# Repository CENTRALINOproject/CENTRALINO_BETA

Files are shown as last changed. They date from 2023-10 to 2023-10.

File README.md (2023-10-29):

<p align = "center">
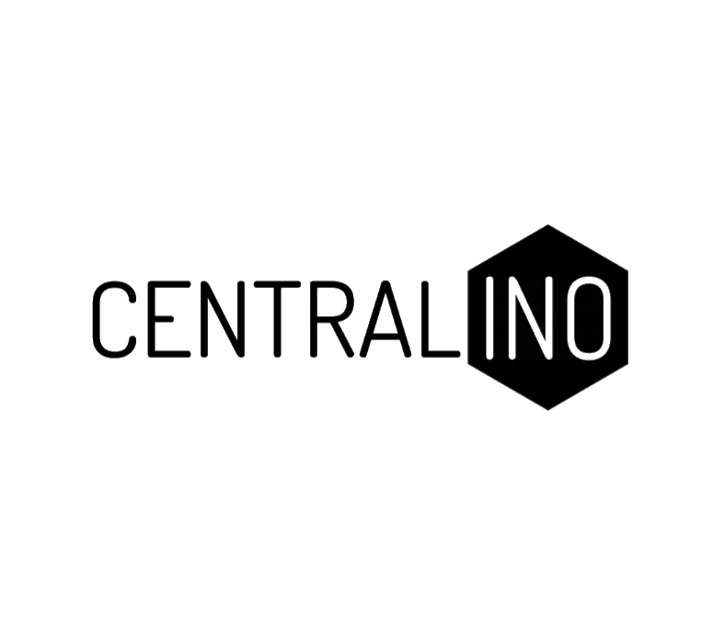
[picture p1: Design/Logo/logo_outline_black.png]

<br>
<i>Your world in your hands.</i>
</p>

> **Arduino-powered device** for _near-field_ **remote control of multiple power outlets**. 
> 
> The device can be programmed and scheduled with timers thanks to its internal clock. 
> 
> It can be **easily configured using its Android app** counterpart, which is designed for devices operating with Android provided of a _bluetooth transmitter_.
> 
> The app also supports **voice commands** with a very simple syntax.

# CENTRALINO
<p align = "right">
Last modified: 19th June 2017
</p>

**Project reference fields:** 

`Novel Technologies`, `Internet of Things (IoT)`, `Home Automation`.

## Hi, I'm Filippo 👋
This is a very old project of mine, it was born in January 2017 and concluded in June the same year. 
This was my first project in the field of electronics and programming.
I was 17 years old and I guess you can tell I was a bit naive, but I was very passionate about it and I still am.

This project has many flaws, but it was a great learning experience, I'm quite fond of it, so I decided to share it here as something to remember. 

Something that will always suggest how ...
<p align = "right">
<b>...every long journey begins with a first step.</b>
</p>

<p align = "center">
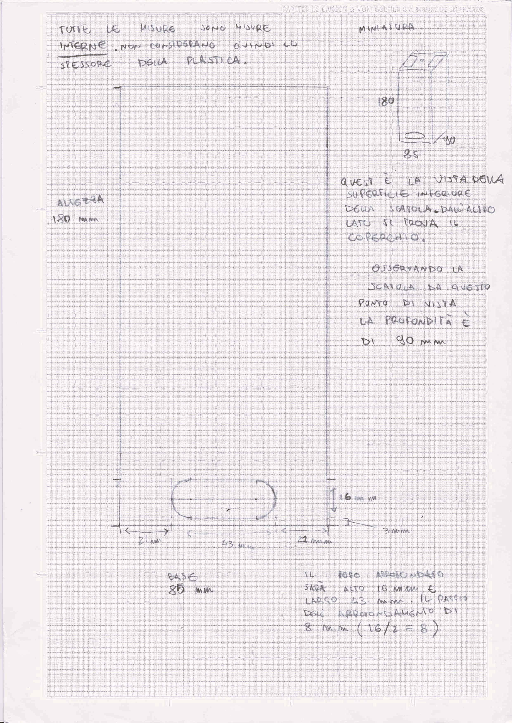
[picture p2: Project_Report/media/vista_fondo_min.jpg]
sketch

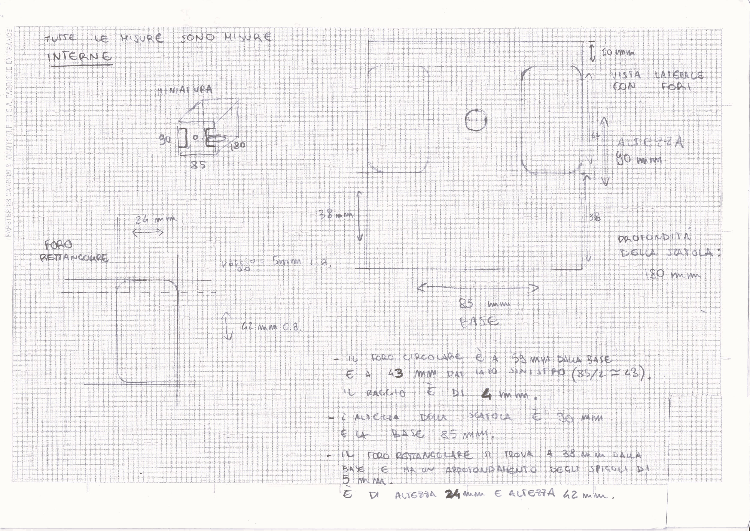
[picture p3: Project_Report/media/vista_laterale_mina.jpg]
lateral sketch

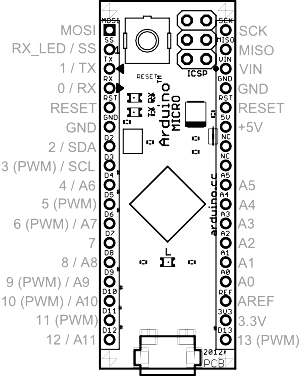
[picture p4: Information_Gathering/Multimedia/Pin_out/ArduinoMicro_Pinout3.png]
pinout arduino micro

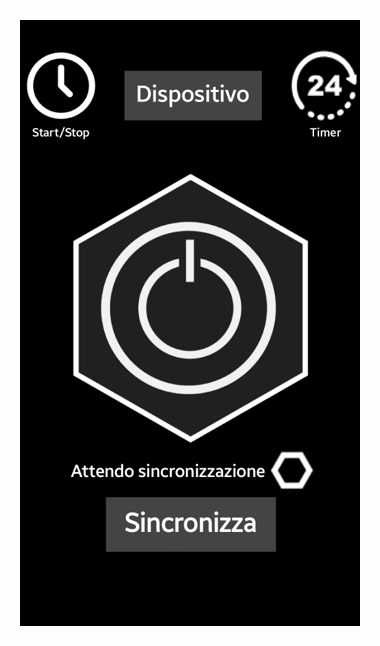
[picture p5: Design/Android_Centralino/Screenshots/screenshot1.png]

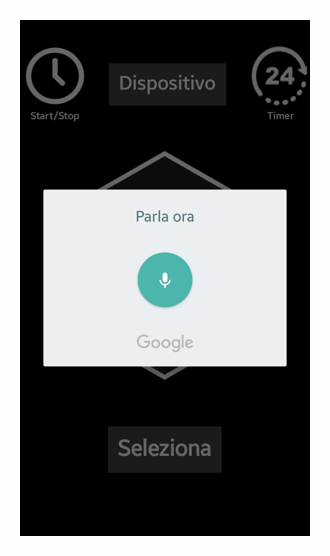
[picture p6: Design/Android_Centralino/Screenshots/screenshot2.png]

</p>

------------------------------------------------------
##### Small note on language 🇮🇹 🇬🇧:
The project was born in Italian, so unfortunately many of the comments in the code as well as documentation and the report are in Italian.
I apologize for this, but I hope that the code is still understandable and that the documentation is still useful (maybe with the help of a translator).

**I decided to have at least the README in English, so that the core of the project as well as the repository structure is understandable to everyone**.

**I also decided to translate a part of the report, concerning the code structure and rationale.**

Such translated document can be found [here](Code_Rationale.md).

**I also translated the Android app presentation concerning the App GUI.** 

Such translated document can be found [here](Design/Android_Centralino/Screenshots/Presentation.md).

## Idea and objective:

The project was born with the purpose of making residential and working complex more connected to the people who inhabit it. The project aims to enhance humans environmental control. 
CENTRALINO is designed to control electrical devices such as household appliances, electric, air conditioners, heating systems, and similar.

An increased control can change a person's experience with the surrounding world. The CENTRALIzation of automation is sometimes not just a convenience but a necessity, e.g. in case of subjects with disabilities. 

"Smart homes" are a topic that companies are vigorously addressing to offer increasing automation and integration between systems and services. 
Home automation involves a complex mix of various technologies and requires strong interdisciplinary collaboration.

### The project aims to:

 - Enhance security of electrical devices populated environments.
 - Reduce operating costs.
 - Convert old environments and old systems into more dynamic ones.
 - Simplify the design, installation, maintenance, and use of technology.
 - As a whole: improve the quality of life.

## Description of the project:

The project is named "CENTRALINO" (Italian for "switchboard"), the name reflects its function of both **centralizing** and **managing** control, much like in telecommunications.

CENTRALINO is a device that allows remote control of multiple power outlets with the possibility to be programmed and scheduled at specific intervals using an internal clock.

The device is easily configured with mobile devices such as phones, tablets, or computers. The latter only needs to run an Android OS and be provided of a Bluetooth transmitter.

## Functions of the device:

Currently, there are three main functions, but the **most important aspect** is that there is an **infrastracture basis that anyone can use to develop their own custom functions** or also implement **new communication protocols**.

1. **Instant On/Off** - Instantaneous switching on and off of the selected device (which means indirect control on its power outlet). 

2. **On/Off with alarm** - Similar to the previous function, but with the possibility of specifying a time at which the device will be turned on or off.

    To do so the device uses the RTC (Real-Time Clock) to compare CENTRALINO's time with the user-set "alarm" time.

3. **On/Off with a timer** - Similar to the previous function, but with the possibility of specifying a duration after which the device will be turned off.

>**Q: How is the CENTRALINO device set to the current time?** 
>
>**A:** It receives the timer duration in minutes from the Android app counterpart and sets the RTC accordingly.

------------------------------------------------------

# Repository structure

    .
    |
    ├── Information_Gathering
    │   ├── Documents                           # Documents concerning components working principles
    │   │    ├── Bluetooth                      # Code snippets and protocol description of bluetooth communication
    │   │    ├── Infra_Red                      # Semiconductor and diodes working principles
    │   │    ├── Transfer_Protocols             # I2C and SPI protocols description
    │   │    └── Flex_sensor                    # Flex sensor working principles
    │   │
    │   └── Multimedia                          # Pin configuration for different hardware components
    │        ├── ...
    │        └── ...
    │
    ├── Design                                  # Design files
    │   ├── Android_Centralino                  # Android app files and latest version apk 
    │   ├── Logo                                # Logo images
    │   └── Software                            # Arduino code files
    |       ├── CLIENTino_versions              # CENTRALINO code versions
    |       ├── Librerie                        # Arduino libraries
    |       └── ...
    │      
    └── Project_Report                          # Final report of the project
        ├── Presentazione_applicazione.pdf      # Android app presentation
        ├── Relazione progetto CENTRALINO.pdf   # Project report
        └── ...

## Information gathering on components: 🔧🔩

I used to create small documentation files for each component and some of them are here listed:

- [Bluetooth Coding](/Information_Gathering/Documents/Bluetooth/Bluetooth_coding.md)
- [Bluetooth](/Information_Gathering/Documents/Bluetooth/Bluetooth_study.md)
- [InfraRed and semiconductors](/Information_Gathering/Documents/Infra_Red/Semiconduttori.md)
- [Transfer Protocols](/Information_Gathering/Documents/Transfer_Protocols/Transfer_protocols.md)
- [Flex Sensor](/Information_Gathering/Documents/Flex_sensor/Flex_sensor.md)

## Design: 📐

Here is possible to find the latest version of the Android app and the Arduino code.

- [Android app](/Design/Android_Centralino/App_builds/STABLE_CENTRALINO1_3.apk) 📱
    - Overview of the App GUI is available [here](/Design/Android_Centralino/Screenshots/Presentation.md)
    - Overview of the App code structure is available [here](Code_Rationale.md#rationale-behind-the-android-app-code-structure)

- [Arduino code](/Design/Software/CLIENTino_versions/CLIENTinoPRESENTATION1_1/CLIENTinoPRESENTATION1_1.ino) ⚙
    - Overview of the Arduino code structure is available [here](Code_Rationale.md#rationale-behind-the-arduino-code-structure)

## Project report: 📝

The project report is available [here](/Project_Report/Relazione%20progetto%20CENTRALINO.pdf) (in Italian).

The android app presentation is available [here](/Project_Report/Presentazione_applicazione.pdf) (in Italian).

------------------------------------------------------

# Implementation 

## Tools used (Software).

 - **Fritzing**: is a free software for electronic design, focused on the transition from simple prototypes to the printed circuit board to be sent to production. Useful for designing the prototype of the circuit even before it is built.
 - **Arduino IDE**: is the integrated development environment (Integrated Development Environment) of Arduino, it is a multiplatform application in Java used to compile the code with which the microcontroller that manages the sensors and other components is programmed.
 - **MIT App Inventor (Framework)**: is a web application created by Google but now owned by the Massachusetts Institute of Technology. A development environment useful for creating applications for personal use.
 - **BlueStacks**: is an application created by the American company BlueStacks Systems Inc. in 2011. BlueStacks App Player is an android app emulator for MacOS and Windows operating systems. The main features are the fully customizable environment, support for multiple operating system configurations and integration with Google Play.

 ## System architecture

A user can connect to CENTRALINO with the appropriate software application simply via Bluetooth. 
  
### The final system will be based on the presence of three characters:

<p align = "center">
diagram
</p>

  - **USER**: connects via bluetooth to the devices.
  - **CENTRALINO**: controls the power outlet.
  - **CENTRALINO-SERVER**: enables the user to control all the associated CENTRALINO (CLIENTs) without ever having to disconnect from CENTRALINO SERVER, which will take care of managing the communications with the others.

    The latter has not been created yet. However, by adding a communication layer on top of the current one with very little effort, it would be possible to create a network of CENTRALINO devices that operate synchronously under the control of a single central server.

------------------------------------------------------

## Tools used (Hardware):

 - Welder.
 - Cellulose adhesive tape.
 - Screwdrivers.
 - Solder wire.
 - Liquid silicone.

## Components used (Hardware):

     • Jumpers for solderless male-male connections.
     • Bread Board for experimental prototypes of solderless circuits.
     • Infrared receiver.
     • Buttons/Buttons.
     • Bluetooth transceiver module – module for Bluetooth transmission and reception.
     • Micro SD Mini Slot – Module for connection with a micro SD card for data storage.
     • Assortment of resistors from 1 to 10 M Ohm (Ω).
     • RTC (Real Time Clock) Real Time Clock – module with battery.
     • Micro ATmegax32u4 powered by 5V (microcontroller).

## Cost of components:

Prices are taken from the following sites:
     - AliExpress: is a branch of the "Alibaba Group" company that unites Chinese companies and offers a retail service to an international market, mainly targeting European buyers. It is the supplier of our components.

     • Jumpers = 120 pieces for €2.39.
     • Bread Board = 2 pieces for €0.74.
     • Infrared LEDs = 20 pieces for €1.25.
     • IR receiver = 10 pieces for €0.73.
     • Buttons/Buttons = 100 pieces for €1.44.
     • RTC (Real Time Clock) = 1 piece for €1.20.
     • Micro ATmegax32u4 = 3 pieces for €4.59 each.
     • Micro SD Mini slot = 2 pieces for €0.47 each.
     • Assortment of resistors = 300 pieces for €1.62.
     • Bluetooth HC-06 module = 2 pieces for €2.73 each.
     • 2-channel relay module (Sain Smart) = 1 piece for €9.00.

TOTAL = 

    2.39 * 1 + 0.74 * 2 + 1.25 * 1 + 0.73 * 1 + 1.44 * 1 + 1.20 * 1 + 4.59 * 3 + 0.47 * 2 + 1.62 * 1 + 2.73 * 2 + 9.00 * 1
= €40.88

> Actually not all the components are strictly necessary, but they were bought in order to have some spare parts in case of damage or malfunction.

#### Enclosure

    • Box = 1 piece for €7.00.

Produced by a local company: Tomea Plastiche.

The enclosure is a box made of plexiglass, a material that is aesthetically pleasing, partially fireproof and relatively easy to work with. Wood and metal were excluded, the first for its predisposition to fire and the second for its well-known electrical conductivity.

### Implementation specifications

In order to be able to implement the device in a larger system, the device only needs a connection to the mains powered at 220 V (Volts) (such as the domestic power grid) and a current voltage not exceeding 15 A (Ampere) to avoid damaging the circuit or incurring a malfunction of the device. 

------------------------------------------------------

### Further development

Possibly in the future the CENTRALINO server may be provided with a wirless antenna in order to communicate with a router, which in turn communicates with the user, possibly via the internet. However, this poses a problem of security and privacy. 

<p align = "center">
diagram
</p>

### Known issues:

 #### Concerning the Instant On/Off function:
For greater safety, future security measures should be implemented to prevent continuous switching on and off of the same outlet to avoid damaging the connected devices and the microcontroller itself.

 #### Concerning voice commands:
The voice commands syntax is very simple, but it is also very limited. It is not possible to deviate even just a little without incurring in unrecognized commands. This is due to the total absence of natural language processing, which in 2017 I dint know how to implement.

 #### Concerning InfraRed communication:
The code structure of the device is able to eventually support infrared communication, but it is not implemented yet to the same extent as Bluetooth. Only basic functions are implemented such as instant on/off of a single outlet. However the physical circuitry is designed to support it and the code structure is ready to be expanded.

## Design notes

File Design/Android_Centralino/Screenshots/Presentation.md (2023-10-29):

# Brief overview of the App UI

## Home Screen

App prompts the user to "connect" to the centralino. This is done by connecting through bluetooth. 

<p align="center">
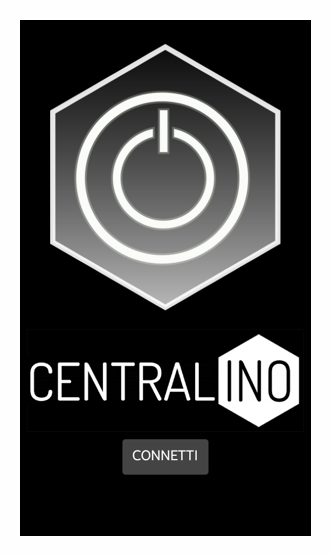
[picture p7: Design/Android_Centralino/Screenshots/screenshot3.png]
Home Screen
    
</p>

> In case the bluetooth is not enabled, the app will ask the user to enable it and guide to settings.

<p align="center">
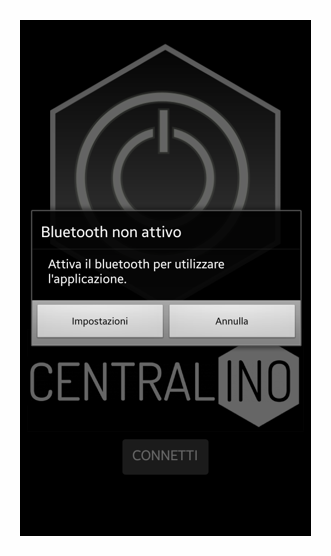
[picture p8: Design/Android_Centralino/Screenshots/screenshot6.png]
BT is not enabled
    
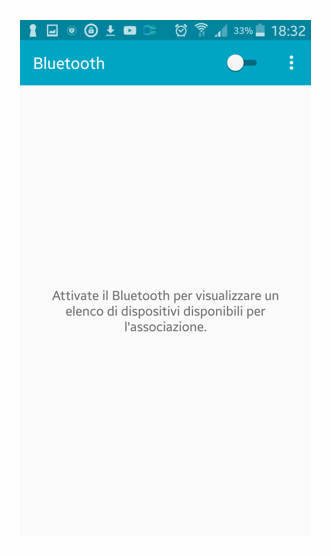
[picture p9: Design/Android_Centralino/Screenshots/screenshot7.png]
BT settings
    
</p>

## Waiting for sync

Once the bluetooth is enabled, the app will start searching for the centralino. Once connected it will prompt the user to sync the available devices connected to the outlets. 

This is done by sending a request to the centralino to send the list of devices connected to the outlets. The centralino will respond with a list of devices. Described in detail [here](../../../Code_Rationale.md#automatic-retrieval-of-the-number-of-devices-connected-to-centralino-by-the-app).

-----------------------------------------------------
### Main screen

<p align="center">
    Waiting for sync
</p>

**Top left**: Alarm icon indicates the possibility to set a time for the device to turn on/off. See [Setting an alarm](#setting-an-alarm).

**Top right**: Timer icon indicates the possibility to set a timer for the device to turn on/off. See [Setting a timer](#setting-a-timer).

**Center**: Main button allows instant on/off control of the currently selected device. 

**Bottom center**: Sync button. This button will be enabled once the centralino is connected. It will allow the user to sync the devices connected to the outlets.

---------------------------------------------------

## Device selection

The app will then display the list of devices and prompt the user to select the device to control.

<p align="center">
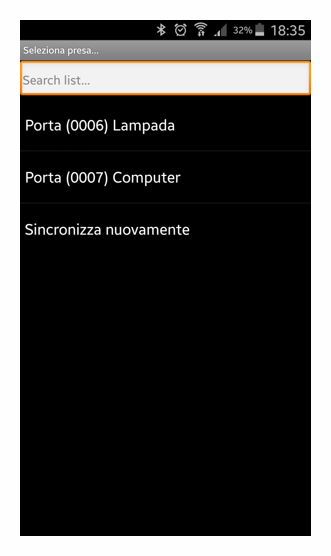
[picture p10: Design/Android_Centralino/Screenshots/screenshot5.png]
Device selection
    
</p>

Devices available in the screehsot are `Lamp`, `Computer`, `New sync`. 

## Voice control

By holding the central button, the user can use voice commands to control the device. The app will prompt the user to speak the command.

<p align="center">
    Voice control
</p>

## Setting a timer

<p align="center">
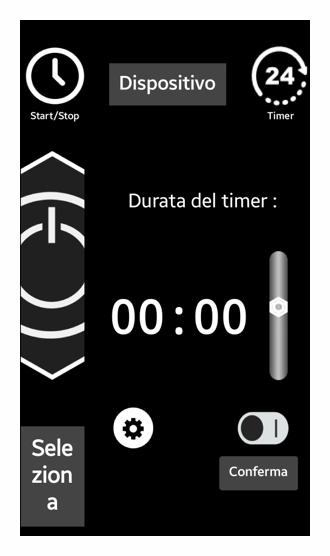
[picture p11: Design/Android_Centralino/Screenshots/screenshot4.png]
Setting a timer
    
</p>

## Setting an alarm

<p align="center">
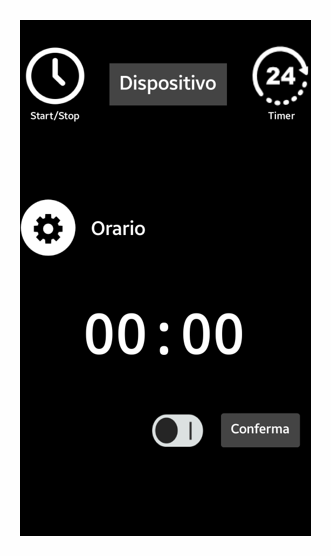
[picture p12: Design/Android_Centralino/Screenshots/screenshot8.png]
Setting an alarm
    
</p>

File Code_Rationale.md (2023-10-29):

# Arduino and Android code rationale
-----------------------------------------------------------

## Rationale behind the Arduino code structure

Referring to the latest version of the code, available [here](/Design/Software/CLIENTino_versions/CLIENTinoPRESENTATION1_1/CLIENTinoPRESENTATION1_1.ino).

### Brief overview of the code structure:
The code utilizes two data structures named `function` and `relay`. 

The `function` structure is responsible for containing the information received through Bluetooth packets, while the `relay` structure is responsible for storing information related to the physical device's outlets. 

Each `relay` structure will have its own:
 - activation and deactivation times, 
 - a timer,
 - a numerical description to indicate on which physical relay to issue a command, especially the pin address so that the microcontroller knows where to send the activation/deactivation signal. 

#### How is the information received from the Bluetooth packets stored?

An additional layer on top of the Bluetooth communication system was created to make the system more flexible. Bluetooth covers all seven levels of the ISO/OSI, but with an additional layer, it is possible to managae different power outlets an the same CENTRALINO (making this comunication mean flexible to our purspose).

#### Bluetooth Packet Structure:

##### Initiator and terminator:
Each Bluetooth packet consists of 16 bytes and has a packet initiator "[" (ASCII: 91) and a terminator "]" (ASCII: 93). 
Without these, it would be impossible to determine when a packet begins or ends, making byte stream handling much more manageable. 

##### Content and divisions:
Inside the packet, there are additional divisions indicated by the symbol "," (ASCII: 44). It helps determine the beginning and end of each packet sector, providing greater packet integrity (in the case of erroneous transmissions, if there are no ",", the packet will not be considered valid. For a better understanding, refer to the "void bluetooth_Parser()" function). 

**Packet final structure**

    [ 
        Activity (2 digits) 
        , 
        Extra_value (4 digits) 
        , 
        Extra_value2 (6 digits) 
    ]

 - `Activity` varies based on Wake-up/Timer and On/Off. 
 - `Extra_value` contains the pin number to which the command should be directed. 
 - `Extra_value2` contains, in the case of "Wake-up," the time in the hh:mm:ss format, and in the case of "Timer," the time in milliseconds.

##### Activity handling:
The system also has an "activity handler"; it serves to manage packets once they have been "routed" and understand the actions required. 

The variable `activity` mentioned in the previous point stores the code corresponding to the action the microcontroller must perform (e.g., 01 and 02 are the `activity` corresponding to instantaneous power On and Off). 

In `Extra_value`, is stored the device number, the packet refers to, so the value found in `rel[x].socket` is, in fact, the pin to which the relay is connected and to which `Extra_value` refers (this mechanism makes it possible to address packets to individual devices, similarly to a "MAC address"). 

In `Extra_value2`, you can find the supplementary value that supports the "activity." For example, the times for "alarms" expressed as "001650" (for integrity reasons, they are always six digits). The one just mentioned is an alarm for 16:50.

> Example packet: "[03,0006,001650]". 
>
> It sets a power-on alarm for 16:50 on pin 6.

### Main Challenges

#### Limitations of the microcontroller:
The microcontroller lacks an internal clock, making it impossible for it to determine the time during activities. This required the use of an external component, a Real-Time Clock module, to manage the time. 

However, this component does not have alarm or timer functions, so the microcontroller had to handle time and activity deadlines on its own. 

Additionally, there was the issue that if two `relay` structures had the same deactivation time and the time for acquiring the time was too slow, the system might be too slow to manage the alarms. This was resolved with the "void turn_by_match()" function, which checks each individual `relay` structure in times well below a second and ensures that multiple `relays` can be turned on/off simultaneously, even when the times coincide down to the second.

#### Automatic retrieval of the number of devices connected to CENTRALINO by the app:
To inform the application about the devices connected to the device, and for this purpose, a superficial description of the power outlets was required. Thus, the `description` variable with a legend (referred to in the code as MEANINGS OF DESCRIPTION) was introduced. The mechanism through which the application learns about the various `descriptions` of the `relay` structures is as follows:

> - The software application sends a packet with activity = 50, i.e., a Discovery (requesting information to be sent).
> - The device sends as many packets as there are "relay" structures with activity = 51 and the respective rel[].description (the description of each structure)
> - Finally sends a packet with activity = 99, which means that the relays have been completed, and the application can stop waiting for more information.

----------------------------------------------------------- 

## Rationale behind the Android app code structure

Referring to the latest version of the code, app .apk available [here](/Design/Android_Centralino/App_builds/STABLE_CENTRALINO1_3.apk)

### Brief explanation
The application mainly uses the use of global variables that are continuously used in block to send packets with the `activity`. These three variables take their name from the physical device system CENTRALINO, therefore they are also called `activity`, `extra_value` and `extra_value2`.

#### Animations
The animations are minimal and take place thanks to the "expansion" of self-moving areas that move the contents of the page to be displayed by the user. When a button is pressed, the cycle starts that "expands" the "push_container" (both "right" and "left") with variables that increase the area covered on the screen. Once "Left_container" and/or "Right_container" have moved, they remain in the position they are in until the next button press.

#### Bluetooth picker
The bluetooth_picker allows you to choose between devices associated with the phone quickly and intuitively.

#### Voice command recognition
Voice command recognition takes place by identifying specific words within a sentence. If the words "turn on" or "turn off" are present in the spoken sentence, the algorithm searches the rest of the sentence for the name of a device that it knows to be connected to the device. If the device is found, the application sends the appropriate signal, otherwise it signals it with a sound notification.

#### On the infrastructure of the app
The App Inventor development platform is based on the use of events. Android events act as a system kernel. They allow you to always know when a certain action has occurred and therefore allow you to call specific functions when those "events" occur. For example, when a button is pressed, it will raise the button.onclick() event and it will be possible to call your own "procedure" (function) whenever the event is raised. Events are many and very varied. The events related to the screen, i.e., "screen.BackPressed()" and "screen.Initialize()", the events related to the buttons of various types ("timePicker" and similar) have been mainly used, and as can be seen from the operating code, the tinyDB object/component with its various methods and functions has been widely used.

### Main Challenges

#### Event Handling
The transition from a conventional programming paradigm to a more intricate one can pose substantial challenges. Unlike traditional sequential code, this paradigm relies on dynamic event-driven behavior, necessitating a shift in coding approach.

#### Scarcity of Documentation
Given that App Inventor is not structured around a conventional programming language, authoritative documentation pertaining to command syntax is notably sparse. While the platform's intuitive operation aids in most cases, instances where intuitive cues fall short demand extensive research and comprehension of commands for achieving predefined objectives.

#### App Inventor Limitations
Significant impediments arise from the utilization of App Inventor, primarily owing to its ongoing beta development status. This platform is susceptible to recurrent crashes, diverse bugs, and frequent disruptions in its partial functionality, posing substantial operational challenges.

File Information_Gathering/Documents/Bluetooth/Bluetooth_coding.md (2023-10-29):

# Bluetooth Codici 

## Note preliminari:

Citazione dalla grande guida dei moduli HC-0X :

 > "3. Notes. (1) HC-03 and HC-05’s command should end up with “\r\n”. It means when you finish programming, you should add terminator (“ENTER” or “0x0d 0x0a”) to the program. It’s different from HC-04 and HC-06 (They don’t need terminator)." 
 
-cit [source](http://cdn.instructables.com/ORIG/FKY/Z0UT/HX7OYY7I/FKYZ0UTHX7OYY7I.pdf)

Secondo la guide di Arduino e instructables i pin del bluetooth vanno connessi così: 
> Pin del Micro per RX ———->      TX

> Pin del Micro per TX ———->      RX

> 3.3V         ———->      VCC

> GND        ———->      GND

### Librerie necessarie:

#include <SoftwareSerial.h>

### Dichiarazioni:

Pre-setup & post-libreria questo :
 - SoftwareSerial nomedelsoftwareseriale(esempio:"bluetooth")(PIN RX,PIN TX);
Nel setup:
 - Nomedelsoftwareseriale.begin(38400);

"In modalità AT il modulo HC comunica a 38400 baud." -cit
"Gran parte di questo capitolo è preso da questa guida su Instructables. Per cambiare configurazione al vostro modulo (ad es. cambiare velocità di trasmissione, nome, pin, ecc.) dovete entrare in modalità AT. L'HC-06 dovrebbe essere sempre in questa modalità, mentre l'HC-05 dev'essere acceso tenendo premuto il tasto "KEY" oppure mettendo a +3.3v il pin key sulla board. " 
-cit http://www.raspibo.org/wiki/index.php?title=HC-05_e_HC-06#Differenze_HC-05_e_HC-06

## Funzioni:

### Verifica della connessione :
#Questa funzione ritorna 1 se la software serial è attiva e sta "ascoltando" (streammando il flusso dati) mentre ritorna 0 se non sta "ascoltando" .

``` C++
int nomedelsoftwareseriale_connection_state()
  {int a=0;
if (nomedelsoftwareseriale.isListeninig())
{a=1}
return a; 
  }
  ```

### Flush del buffer sul software seriale :
#Questa funzione semplicemente scarta TUTTO quello che c'è nel buffer inserendolo nella variabile flush e sovrascrivendolo ogni volta. Non c'è modo di invertire questa funzione.

``` C++
void buffer_flush()
{
  while(nomedelsoftwareseriale.available()>0)
    {
    char flush = nomedelsoftwareseriale.read();
    }
} 
```

### Trasmissione di un messaggio intero e stringa :
#Questa funzione trasmette sul software seriale inizializzato (qualsiasi dipendentemente dal nomedelsoftwareseriale ) una stringa o un intero passata/o alla funzione, il nome della variabile nella funzione è 'transimission'.
``` C++
void message_string_transmit (string transmission)
{
nomedelsoftwareseriale.write(transmission);
}

Piccola variante della funzioni precedenti che permette di inviare variabili di interi. 

void message_int_transmit (int transmission)
{
nomedelsoftwareseriale.write(transmission);
}
```

### Funzione per la restituzione della lunghezza del buffer del software seriale.

``` C++
int buffer_lenght();
{int lenght=0;
x=nomedelsoftwareseriale.available();
return x;
}
```

### Verifica dei messaggi :
#Questa funzione ritorna il contenuto del buffer del software seriale se presente altrimenti ritorna NULL, se il buffer supera il limite di 2048 elementi il buffer non viene letto e viene flushato poiché illeggibile.
Esiste anche readString ma questo metodo mi sembra più sicuro, non ottimale, sicuro.

``` C++
char serial_buffer_retrieve() 
{int char_ind=0, char_ind2=0, x; 
 x=lenght_buffer();

if (x>0)&&(x<2048)
#'x>0' significa che ci sono x dati nel buffer, svuota (buffer_flush()) il buffer se ci sono più di 2048 elementi, altrimenti si va verso il buffer overflow.
{
      char buffer_retrieve[x];
 
      #inizializzazione buffer_retrieve[x](sotto) 
for (char_ind=0; char_ind<x; char_ind++) 
{
buffer_retrieve[char_ind]=' ';
} 

#scrive su buffer_retrieve[x](sotto)
for (char_ind2=0; char_ind2<x; char_ind2++) 
{
char_retrieve[char_ind2] = nomedelsoftwareseriale.read(); 
} 
return char_retrieve[x]; 
} 
buffer_flush();
return null;
}
```

Funzione per l'identificazione (detecting) di messaggi singoli o multipli contenuti nel vettore di caratteri passato alla funzione. 
Si utilizza la variabile char end_message per stabilire una combinazione di caratteri all'interno del messaggio con il significato di 'fine messaggio'.
Si utilizza la variabile int lenght per sapere quanto è lungo il vettore di caratteri essa sarà calcolabile grazie alla funzione buffer_lenght(), la funzione appena esplicitata andrà posizionata con criterio prima della funzione serial_buffer_retrieve;
La funzione ritorna il numero di messaggi (il numero di volte che viene trovato nel vettore 'detecting' il vettore char 'end_message') sotto forma di intero.

### Esempio : 

Vettore end_message = "*r"
Vettore detecting = "ciao *r come *r stai? *r"
in questo esempio verrano detectati 3 messaggi (3 volte è presente "*r").

``` C++
int message_detect(char detecting[], char end_message[|2 circa?|], int lenght)
{int number_of_messages=0, utility_ind=0;
for( utility_ind=0; utility_ind<lenght; utility_ind++)
{
if( detecting[utility_ind] == end_message[1])
if(( detecting[utility_ind+1] == end_message[2])&&(utility_ind!=lenght-1))
#la riga sovrastante serve ad evitare che venga letto un carattere in più rispetto alla lunghezza del vettore stesso. (esempio utility_ind==19 allora utility_ind+1==20 QUESTO NON DEVE ACCADERE) questo problema è anche risolvibile modificando il for ma una soluzione vale l'altra in questo caso.
  number_of_messages++; 
}
return number_of_messages;
}
```

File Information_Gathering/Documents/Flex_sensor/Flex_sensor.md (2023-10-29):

# Cosa è un "Flex sensor" e come funziona.

Un "Flex sensor" è...

Un sensore che ha la forma di una striscia sottile. Esso permette di ricevere un segnale elettrico analogico che varia in base all'angolo di curvatura del sensore. Nell'immagine sottostante esso è fotografato nel suo stato di tensione e quello di flessione.

<p align="center">
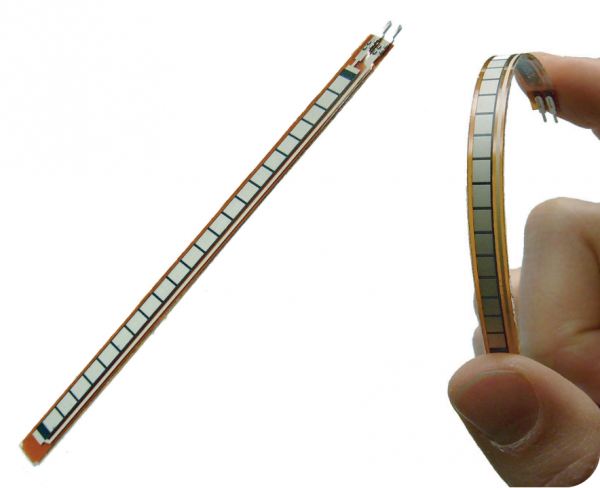
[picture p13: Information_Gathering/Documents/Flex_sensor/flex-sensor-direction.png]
  
</p>

## Come funziona il "Flex sensor":

Su un lato il "Flex sensor" (sensore di flessione) è ricoperto di un inchiostro polimerico che ha particelle conduttrici in esso. Quando il sensore è teso (completamente dritto), le particelle danno all'inchiostro una resistenza di circa 30kΩ. Quando il sensore è curvo o flesso in qualsiasi modo le particelle si distanziano tra loro, aumentando la resistenza (fino a circa 50-70kΩ quando il sensore è piegato a 90°, come nel disegno sottostante).
 
Quando il sensore si tende nuovamente, la resistenza ritorna al valore originale. Misurando la resistenza, si può determinare quanto il sensore sia piegato. 
 
<p align="center">
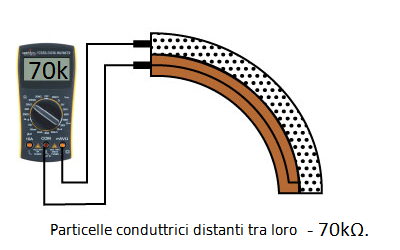
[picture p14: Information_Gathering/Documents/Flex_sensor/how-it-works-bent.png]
  
</p>

<p align="center">
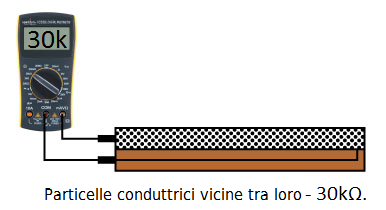
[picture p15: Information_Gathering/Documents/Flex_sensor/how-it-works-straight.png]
  
</p>

Connessioni :

•	Una resistenza dovrebbe connettere AX(Pin analogico n° X) al GND(terra).
•	 Il "Flex sensor" dovrebbe connettere AX all'erogatore di tensione 3.3V
Quanto più la resistenza sul sensore aumenta (in seguito ad una flessione), tanto più il voltaggio su AX dovrebbe dimminuire.
Nelle due immagini sottostanti si mostra come è necessario collegare un "Flex sensor" ad un microcontrollore a finché funzioni correttamente. 

<p align="center">
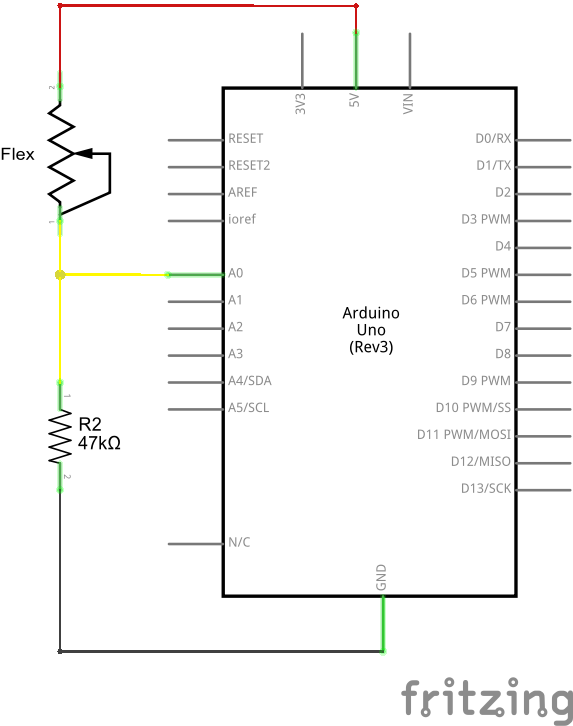
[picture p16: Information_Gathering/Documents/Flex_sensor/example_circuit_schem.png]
  
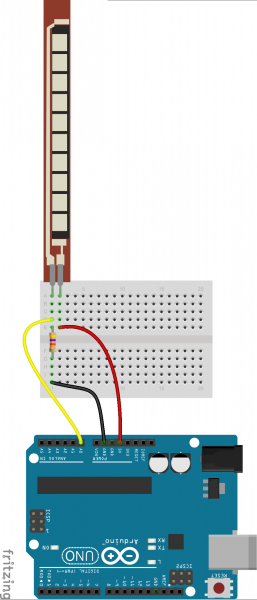
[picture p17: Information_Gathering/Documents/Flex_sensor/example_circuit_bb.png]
  
</p>

Dichiarazioni :

``` C++
const int FLEX_PIN = AX; // Pin analogico connesso al divisore dell'output del sensore

// Measure the voltage at 5V and the actual resistance of your 47k resistor, and enter them below:
const float VCC = 4.98; // Measured voltage of Ardunio 5V line
const float R_DIV = 47500.0; // Measured resistance of 3.3k resistor

// Upload the code, then try to adjust these values to more
// accurately calculate bend degree.
const float STRAIGHT_RESISTANCE = 37300.0; // resistance when straight
const float BEND_RESISTANCE = 90000.0; // value of resistance at 90 deg
```

Dichiarazione nel setup():
``` C++
void setup() 
{
  Serial.begin(9600);
  pinMode(FLEX_PIN, INPUT); 
}
```
Dichiarazione nel loop():
``` C++
void loop() 

{
  // Read the ADC, and calculate voltage and resistance from it
  int flexADC = analogRead(FLEX_PIN);
  float flexV = flexADC * VCC / 1023.0;
  float flexR = R_DIV * (VCC / flexV - 1.0);
  Serial.println("Resistance: " + String(flexR) + " ohms");
  // Use the calculated resistance to estimate the sensor's bend angle:
  float angle = map(flexR, STRAIGHT_RESISTANCE, BEND_RESISTANCE,0, 90.0);
//la funzione map() serve a rapportare il valore flexR tra straight_resistance(minimo) e
// bend_resistance(massimo) sulla scala tra 0(minimo) e 90(massimo) (gradi)
  Serial.println("Bend: " + String(angle) + " degrees");
  Serial.println();

  delay(500);
}
```

Fonti:

https://learn.sparkfun.com/tutorials/flex-sensor-hookup-guide#example-program
"One side of the sensor is printed with a polymer ink that has conductive particles embedded in it. When the sensor is straight, the particles give the ink a resistance of about 30k Ohms. When the sensor is bent away from the ink, the conductive particles move further apart, increasing this resistance (to about 50k-70K Ohms when the sensor is bent to 90°, as in the diagram below).
When the sensor straightens out again, the resistance returns to the original value. By measuring the resistance, you can determine how much the sensor is being bent. "

"Development environment specifics:
Arduino 1.6.7"

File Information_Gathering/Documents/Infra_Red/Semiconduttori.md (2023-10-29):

# I SEMICONDUTTORI
L'atomo usato nei semiconduttori è il silicio, un atomo tetravalente (4 elettroni di valenza), che per ciò forma legami molto forti con gli altri atomi di silicio. Per creare corrente bisogna creare un passaggio di elettroni, quindi si usa inserire atomi diversi: questo processo è chiamato drogaggio. 
Drogaggio tipo Negativo: si inseriscono elementi pentavalenti (Arsenico), così facendo vi è un elettrone in meno, che è libero. 
Drogaggio tipo Positivo: si inseriscono elementi trivalenti (alluminio), così si crea una lacuna, e gli altri elettroni vi si spostano.
# DIODO
il diodo è composto da due elementi: uno a drogaggio P (con le lacune), uno con drogaggio N (elettroni in più, negativi). Il punto di giunzione si chiama Giunzione PN. Dalla parte della P vi è l'ANODO, dalla parte della N vi è il CATODO.  
<p align="center">
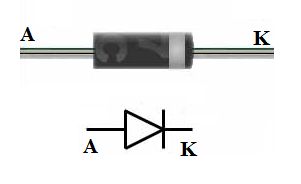
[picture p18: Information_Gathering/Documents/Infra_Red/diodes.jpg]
diodes
  
</p>

La resistenza è da 1KOhm. La corrente scorre dall'anodo al catodo (anche se in realtà la corrente scorre al contrario). 

## Sommario
IL DIODO SERVE A FAR SCORRERE LA CORRENTE IN UN SOLO VERSO. PASSA CORRENTE SOLO SE Va>Vk. QUANDO IN UN DIODO SCORRE CORRENTE, AI SUOI CAPI SI CREA UNA TENSIONE DI SOGLIA (0.6 – 0.7 V.)

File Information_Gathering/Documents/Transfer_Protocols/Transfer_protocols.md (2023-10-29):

# Protocolli di trasferimento

Per rendere semplice il trasferimento di informazioni tra sensori e microcontrollori sono stati realizzati due tipologie di protocolli: I2C (Inter-Integrated Circuit) e SPI (Serial Peripheral Interface).
Entrambi i sistemi hanno i propri pro e contro che li rendono più o meno convenienti per l’applicazione data.
Le librerie di Arduino permettono di utilizzare questi protocolli con estrema facilità.
In fase progettuale la scelta del protocollo dipende dal tipo di dispositivo che si vuole utilizzare. Sicuramente potrete trovare in commercio dispositivi che permettono di utilizzare entrambi i protocolli ma è più comune trovare dispositivi che supportano un solo standard.

## DIFFERENZE TRA SPI E I2C
SPI supporta la comunicazione full-duplex con un throughput molto più alto rispetto ad I2C. non è limitato a parole di 8 bit, in modo da poter inviare messaggi di ogni genere e con contenuti e scopi arbitrari. L’interfaccia SPI non richiede resistenze di pull-up, il che si traduce in un minore consumo di energia. Tuttavia, I2C è più semplice avendo meno linee il che significa che meno piedini sono richiesti per interfacciarsi ad un circuito intergrato. Quando si comunica con più di un dispositivo slave, I2c possiede il vantaggio di un indirizzamento in banda (a noi non interessa), al posto di avere una linea chip select per ogni slave. I2c supporta inoltre lo slave acknowledgment che significa che si è certi del dispositivo con cui si sta comunicando. Con SPI, un master può inviare dati a vuoto e non saperlo. In generale SPI è consigliato per applicazioni che comunicano lunghi flussi di dati e non solo parole come locazioni di memoria.
Lunghi flussi di dati sono presenti in applicazioni in cui si lavora con un processore di segnali digitali o con un ADC, per esempio, SPI sarebbe perfetto per riprodurre dell’audio memorizzato in una eeprom e riprodotto attraverso un convertitore digitale analogico. Inoltre, dato che SPI supporta elevate dimensioni di dati in confronto a I2C, soprattutto grazie alla sua capacità duplex, è molto raccomandato per applicazioni veloci, che raggiungono le decine di MegaHertz. Inoltre dato che non ci sono dispositivi per l’indirizzamento sviluppati per SPI il protocollo è molto più difficile da usare nel caso di più dispositivi slave. Questo significa che quando si utilizzano più di un nodo, in genere utilizzare I2C è consigliato

## INTERFACCIA SPI

<p align="center">
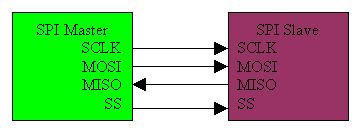
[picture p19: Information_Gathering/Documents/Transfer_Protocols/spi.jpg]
  
</p>

come si può vedere nella figura, SPI ha 4 linee. La linea SCLK è la linea di clock, il clock è generato dal master e scandisce la comunicazione in entrambe le direzioni, e questa linea è un ingresso per tutti gli slave. MOSI è la linea master output slave input e porta i dati dal master verso lo slave. La linea MISO è l’opposto, prende l’output dello slave e lo indirizza al master. Per finire la linea SS conosciuta anche come CS è utilizzata per selezionare lo slave a cui trasferire i dati. Di solito la sequenza di trasferimento consiste nel porre a livello basso la linea SS con un piedino di I/O generico, inviare un numero di X segnali di clock con la giusta polarità e fase, porre a livello alto la linea SS per terminare la comunicazione.
I dati sono trasmessi in entrambe le direzioni, per cui in un sistema “transmit only” i byte ricevuti saranno scartati e in un sistema “receive only” deve essere mandato un byte fittizio. Bisogna aver cura di non invertire la il segnale SS durante la comunicazione siccome questo introdurrà errori. La polarità e il controllo della fase del clock avvengono su ogni fronte del segnale di clock in cui i dati sono ricevuti o inviati. Deve essere settato per coincidere tra master e slave. Esiste inoltre una versione di SPI 3-wire che tuttavia supporta solo la comunicazione half duplex. Questa implementazione usa una linea SISO, questa linea bidirezionale singola trasporta i dati in entrata e in uscita dallo slave. Questa modalità ha una tendenza a non essere supportato dai microcontroller ma può essere facilmente implementato via software.

## I2C

<p align="center">
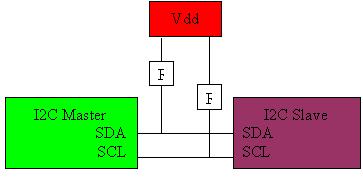
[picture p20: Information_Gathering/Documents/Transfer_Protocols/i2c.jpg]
  
</p> 

I2C consiste di due linee bidirezionali che sono tenute alte a Vdd. La linea SDA corrisponde ai dati seriali e SCL è il clock seriale. I moduli standard I2C supportano indirizzi slave a 7 bit e supportano fino a 112/128 nodi, alcuni moduli estesi supportano indirizzamenti slave a 10 bit, tuttavia tutti i moduli sono limitati ad una capacità di bus di 400pF. Le velocità standard si aggirano intorno ai 10kbps per la modalità Low-speed 100kbps nella modalità Fast plus, e 3.4Mbps nella modalità Hi-speed. I tre tipi di messaggi definiti dal protocollo I2C sono un singolo messaggio che il master scrive ad uno slave, un singolo messaggio che il master legge da uno slave e un messaggio combinato dove il master dispone almeno due letture e/o scritture ad uno o più slave.
La sequenza di comunicazione inizia con il master che invia un bit di start seguito dall’indirizzo dello slave a 7 o 10 bit e infine un bit che seleziona l’operazione: 1 per leggere e 0 per scrivere. A questo punto, se l’indirizzo dello slave esiste sul bus, lo slave invierà un bit di acknowledgment al master. I data sono dunque trasmessi sulla linea SDA nella direzione specificata dal master. Un bit di acknowledgment viene mandato alla fine della trasmissione di ogni byte fino al ricevimento della fine della trasmissione. L’unica eccezione si ha quando il master è in modalità ricevimento e lo slave in modalità trasmissione il master non invierà nessun bit di acknowledgment dopo l’invio dell’ultimo bit ricevuto. In ultimo la comunicazione viene terminata con il master che invia un comando di stop.
I comandi di start e stop altro non sono che semplici transizioni dall’alto al basso (start) sulla linea SDA con SCL alta, o dal livello basso al livello alto (stop) sulla linea SDA con SCL a livello alto. Le transizioni per i bit di dati sono sempre eseguite quando la linea SCL è bassa; lo stato alto è solo per i comandi di start e stop.
Fortunatamente questo fornisce una conoscenza migliore di questi due protocolli, e le loro differenze. Dovrebbe essere molto più semplice scegliere tra i due per un’applicazione data. Ma la vita non è così semplice, bisogna comunque considerare se altri tipi di comunicazione non si addicono bene per l’applicazione sarebbe meglio ancora non utilizzare affatto un protocollo seriale ma utilizzare un tipo di comunicazione parallela.

Fonti: 
http://www.maffucci.it/2015/10/03/esercizio-arduino-in-60-minuti-usare-un-display-oled/
http://it.emcelettronica.com/comunicazione-seriale-i2c-o-spi-quale-usare

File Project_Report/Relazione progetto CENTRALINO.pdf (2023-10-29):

1

CENTRALINO

Di Castellani Filippo.

Data ultima modifica

7/7/2017

Progetto CENTRALINO | 2

Indice

Dispositivo fisico CENTRALINO.

- Documentazione generale di progetto :
- Idea del progetto.
- Caratteristiche.
- Funzioni.
- Disegno forma e cianografia.
- Interfaccia utente.
- Elenco componenti.
- Scelta componenti e preventivo.
- Simulazioni.
- Scheda di progetto.
- Analisi dei requisiti.
- Analisi delle competenze necessarie.
- Architettura di sistema.
- Specifiche implementative.
- Documento tecnico :
- Documentare il completamento del progetto e tabella sui tempi delle attività.
- Strumenti utilizzati (Software).
- Strumenti utilizzati (Hardware).
- Codice.
- Spiegazione del codice e le sue funzionalità e particolarità.
- Problematiche degne di nota affrontate nella creazione del codice.

- Manutenzione.

Applicazione software CENTRALINO.

- Documentazione generale di progetto :
- Idea del progetto
- Caratteristiche.
- Interfaccia utente.
- Simulazioni.
- Architettura di sistema.
- Specifiche implementative.
- Documento tecnico :
- Documentare il completamento del progetto e tabella sui tempi delle attività.
- Codice.
- Spiegazione del codice e le sue funzionalità e particolarità.
- Problematiche degne di nota affrontate nella creazione del codice.
- Manutenzione.
- Licenze
- Codici e relative spiegazioni.
- Codice dispositivo fisico CENTRALINO
- Codice per microcontrollore Arduino.
- Breve spiegazione.
- Problematiche principali.
- Codice applicazione CENTRALINO
- Codice descrittivo della grafica dell'applicazione.
- Codice operativo dell'applicazione.

- Breve spiegazione.
- Problematiche principali.
- Conclusioni :
- Futuri sviluppi.
- Dedica.
- Fonti.

Dispositivo fisico CENTRALINO

Documentazione generale di progetto :

- Idea del progetto.
- Il progetto nasce con l'intenzione di rendere qualsiasi plesso abitativo,

residenziale o lavorativo più connesso con le persone stesse che lo popolano. Il

progetto è il tentativo di portare ad un nuovo il livello di controllo dell'ambiente

per l'uomo. CENTRALINO rende a portata di mano il controllo di tutto ciò che di

elettrico ci circonda. È possibile controllare elettrodomestici, strumenti di lavoro,

strumenti musicali, fornelli elettrici, impianti di aereazione, condizionatori,

sistemi di riscaldamento e così via tutto ciò che necessita di elettricità per

funzionare. Questa centralizzazione di controllo può in alcuni casi cambiare

totalmente l'esperienza di una persona con il mondo circostante, per esempio nel

caso di una persona disabile. La comodità dell'automatizzazione a volte non è solo

una comodità è bensì una necessità. In questi anni il tema della cosa domotica è

un tema in cui le aziende si stanno confrontando duramente per offrire sempre una

maggiore automazione e integrazione con sistemi domotici. La domotica è un

complesso di moltissime tecnologie diverse e richiedono una forte

interdisciplinarità si parla di ingegneria edile, architettura, ingegneria energetica,

automazione, elettrotecnica, elettronica, telecomunicazioni, informatica e design.

Il progetto CENTRALINO come la domotica in generale ambisce perciò a:

- Migliorare la qualità della vita.
- Migliorare la sicurezza.

- Semplificare la progettazione, l'installazione, la manutenzione e l'utilizzo

della tecnologia.

- Ridurre i costi di gestione.
- Convertire i vecchi ambienti e i vecchi impianti in ambienti più dinamici.
- Caratteristiche.
- Il nome del progetto è "CENTRALINO", prende il nome proprio dal tipo di

operazione che fa, sia "centralizzare" il controllo ma anche gestirlo, come accade

in telefonia. Consiste in un dispositivo che permette il controllo remoto di un

presa di più prese di corrente con la possibilità di essere programmabile ad

intervalli di tempo grazie ad un orologio interno. Il dispositivo si configura

facilmente con i dispositivi mobili come telefoni, tablet o computer. Quest'ultimo

deve solamente supportare applicazioni create per sistemi operativi Android ed

essere provvisto di trasmettitore Bluetooth.

- Settore di riferimento : nuove tecnologie, Internet of Things (Internet delle Cose),

domotica.

- Funzioni
- Le funzioni per ora sono 3 ma la cosa più importante è che ormai c'è una base che

chiunque può usare per sviluppare le proprie funzioni personalizzate. Le funzioni

sono :

- 1) Spegnimento/Accensione istantaneo/a – Per una maggiore sicurezza in

futuro saranno implementate misure di sicurezza secondo le quali non sarà

possibile accendere e spegnere in continuazione la stessa prese per evitare di danneggiare la componentistica del dispositivo collegato e di

CENTRALINO stesso.

- 2) Spegnimento/Accensione con sveglia. Sfrutta l' RTC per confrontare il

tempo di CENTRALINO con l'orario che viene impostato dall'utente che

imposta la "sveglia".

- 3) Spegnimento/Accensione con timer. Sfrutta la libreria <Time.h> che

permette l'utilizzo di un oggetto (strumento informatico) di

immagazzinamento di orario, data e fondamentalmente permette di avere

un orario locale sempre aggiornato anche senza un dispositivo come

l'RTC. Interrogare in continuazione l'RTC significherebbe aumentarne

troppo il consumo di batteria (la batteria dell'RTC) e siccome richiede

tempo cambiarla si preferisce usare la libreria citata e aumentare quindi la

durata della batteria. Il dispositivo fisico CENTRALINO riceve

dall'applicazioni software CENTRALINO in minuti la durata del timer e

esegue delle operazione per sapere a quante ore, minuti e secondi

corrispondono.

- Disegno forma e cianografia.

- Interfaccia utente.
- L'interfaccia utente di CENTRALINO è prettamente manuale, è possibile solo la

disattivazione completa di esso tramite il pulsante blu all'interno della scatola

contenitrice. CENTRALINO è programmabile ed è possibile interagire con esso

solo con l'applicazione software apposita a meno che non lo si voglia spegnere

tramite il suddetto pulsante interno.

- Elenco componenti.
Nome | Venditore | Prezzo (€) | Breve descrizione
Modulo relay da 2 canali | Sain Smart | 9.00 | Modulo per il controllo del flusso di
| | | corrente.
Arduino Micro | Ali-express 4.50 | Microcontrollore
Modulo Bluetooth HC-06 | Ali-express 5.20 | Modulo per la trasmissione senza fili
| | | Bluetooth
Modulo RTC (Real Time
Clock)
Ali-express 3.50 | Modulo orologio indipendente e
| | | autonomo (alimentato a batteria)
Scatola | Tomea
| plastiche | 7.00 | Scatola contenitrice.

Tabella 1

- Scelta dei componenti e preventivo.
- I componenti hanno uno scopo prototipale, non si esclude affatto la futura

rielaborazione e nuova creazione di una lista di componenti più specifici.

- La scatola contenitrice è appositamente stata realizzata in plexiglass perché è il

materiale che più si avvicina alla necessità di un materiale esteticamente

accattivante, parzialmente ignifugo e relativamente facilmente realizzabile. Sono

stati esclusi legno e metallo, il primo per la sua predisposizione al fuoco e il

secondo per la sua nota conduttività elettrica.

- Il preventivo per la realizzazione dello stesso progetto è di 29.2 € per quanto

riguarda la componentistica che è stata utilizzata. Supponendo una produzione in

serie il prezzo calerebbe drasticamente. Una delle forze infatti del progetto stesso

è anche il basso costo di costruzione che esso richiede.

- Simulazioni.
- Sono state effettuate delle simulazioni in ambienti controllati e sicuri con esiti

positivi, testando tutte le funzionalità di CENTRALINO.

Scheda di progetto

- Analisi dei requisiti.
- CENTRALINO è stato pensato per funzionare con i mezzi di comunicazione senza

fili. Requisito basilare è perciò un mezzo di comunicazione senza fili, la versione

attuale sfrutta la tecnologia Bluetooth ma lascia aperte le possibilità all'utilizzo di

altre non essendo strettamente dipendente da essa.

- CENTRALINO è stato pensato per funzionare come una rete di dispositivi che

collaborano nello stesso ambiente. Perciò il protocollo di messaggistica tra i vari

CENTRALINO si è sviluppato intorno a questa necessità, provvedendo a far si che

fosse possibile avere molti dispositivi tutti collegati contemporaneamente. Come

avviene lo scambio di pacchetti di dati tra i vari CENTRALINO verrà spiegato

successivamente nell'apposito paragrafo.

- Analisi delle competenze necessarie.
- Inglese:
- Le ricerche necessarie a comprendere e documentarsi sulle strumentazioni

più adatte a dar vita a questo progetto sono in vasta preponderanza presenti

sul web in lingua inglese. Senza la conoscenza della lingua fare ricerche

specifiche sarebbe quasi impossibile. C'è inoltre grande bisogno di una

conoscenza di termini tecnici della lingua poiché si utilizza un determinato

tipo di lessico nelle documentazioni al proposito di apparecchi elettronici.

- Fisica generale ed elettronica:

- Conoscenza necessaria per un sicuro lavoro manuale con correnti ad alte

tensioni come quelle con cui CENTRALINO lavora. Conoscenza del

funzionamento di un circuito e dei possibili corretti posizionamenti dei relay

magnetici. In più sono necessarie le conoscenze di sintassi informatica e

logica specifiche dei circuiti, indispensabili per il funzionamento dei

programmi.

- Informatica:
- Vengono utilizzati per la produzione del progetto i seguenti linguaggi di

programmazione :

- C.
- C++.
- Conoscenze base di java.
- Essi non sono strettamente collegati allo studio effettuato a scuola, tuttavia

i metodi per interfacciarsi ed imparare nuovi linguaggi sono in maggior

parte stati appresi con lo studio in aula.

- Elettronica pratica:
- Conoscenze tecniche per l'assemblaggio, la saldatura dei componenti e la

realizzazione del circuito.

- Italiano:
- Capacità descrittive per la più adeguata forma di descrizione e spiegazione

per un progetto che necessita di alte capacità lessicali per non fraintenderne

il funzionamento. Necessarie per la compilazione di un manuale tecnico

facilmente interpretabile.

- Tecnologia progettazione di sistemi:
- Conoscenze di tecniche di base e approfondite per lo sviluppo di:
- Software multi-piattaforma.
- Conoscenza dei sistemi di trasferimento dati necessari al

trasferimento senza fili (Bluetooth ora ma futuramente verrà

sviluppato anche WI-FI, e onde-radio a meno di 2.5 Ghz)

protocollato a pacchetti.

- Conoscenza del sistema ISO/OSI.
- Interfaccia per l'utente.
- Interfacciamento tra il sistema operativo del dispositivo fisico

CENTRALINO e il software applicativo CENTRALINO (sul

dispositivo Android).

- Le sottocategorie sono innumerevoli perciò queste due grandi categorie a simbolo

delle vaste conoscenze necessarie.

- Organizzazione d'impresa:
- Possibili e probabili risvolti futuri non ancora presi in

considerazione per mancanza di tempo.

- Capacità manuali e di inventiva:
- Da non sottovalutare.

Architettura di sistema

- Un utente può collegarsi a CENTRALINO con l'apposita applicazione software

semplicemente tramite le impostazioni Bluetooth offerte dall'applicazione stessa. Una

volta che l'utente si connette ad un CENTRALINO, per controllarne un altro dovrà prima disconnettersi da quello a cui è già collegato. Il sistema finale si baserà sulla presenza di

tre personaggi :

- Utente controllore (utilizza applicazione software descritta nella sezione

successiva della relazione) che impartisce i comandi ai dispositivi

CENTRALINO.

- CENTRALINO (descritta in questa parte della relazione) che controlla la presa di

corrente.

- CENTRALINO-SERVER (non descritta in questa relazione ma di cui è prevista

la futura creazione) che da la possibilità all'utente di controllare tutti i

CENTRALINO associati senza mai doversi disconnettere da CENTRALINO

SERVER che provvederà lui stesso a gestire le comunicazioni con gli altri.

- Specifiche implementative
- Per funzionare ed essere implementato in un sistema più grande, CENTRALINO

necessità solamente di una connessione alla rete elettrica alimentata a 220 V (Volt)

(come ad esempio la rete elettrica domestica) ed una tensione di corrente non

superiore a 15 A (Ampere) per non rischiare di danneggiare il circuito o incorrere

in un malfunzionamento del dispositivo.

Documento tecnico :

- Documentare il completamento del progetto e tabella sui tempi delle attività.
- CENTRALINO si trova al momento nella sua versione ultima ma come già

espresso in questo documento sono già previste future migliorie. Il progetto è

stato pensato a Febbraio 2017 e la sua realizzazione prototipale è giunta al

termine in Giugno 2017 . Le macro fasi del completamento del progetto sono

state:

Fase | Durata
- Ideazione del progetto e stesura di un documento
iniziale dove si chiariscono gli obbiettivi e le
funzionalità del progetto che si intende realizzare.
| 2 settimane ca.
- | Analisi dei requisiti. | 1 settimana ca.
- | Analisi delle peculiarità tecniche dei requisiti. | 1 settimana ca.
- Ricerche di natura tecnica sulle caratteristiche dei
| componenti e le loro funzionalità, in particolare moduli e ricerche sul funzionamento delle reti elettriche. | 2 settimane ca.
- | Scelta dei componenti. | 3 giorni ca.
- Ideazione e progettazione del software residente
| nel microcontrollore che gestisce tutti i componenti collegati. | 1 settimana ca.
- Lunga e dolorosa creazione del software (trattata
nell'apposito paragrafo).

1 mese ca.

- | Assemblaggio dei componenti. | 1 settimana ca.
- Test e cura dei difetti di creazione, hardware e
| software, ma soprattutto software. | 1 settimana ca.
- Ideazione dell'applicazione software utile al
| controllo di CENTRALINO | 4 giorni ca.
- Progettazione e realizzazione del sistema di
| scambio dati tra : applicazione e CENTRALINO; tra CENTRALINO e CENTRALINO SERVER.. | 2 settimane ca.
- Scelta dei criteri per la creazione dell'apparato
grafico e successiva creazione.

1 settimana ca.

- Realizzazione del sistema software utilizzato dall'applicazione.

1 settimana ca.

- Test di funzionamento dell'applicazione e correzione di errori grafici e software

1 settimana ca.

- Test di utilizzo dell'applicazione all'opera in casi reali d'uso (connessa a CENTRALINO).

1 settimana ca.

- Progettazione della scatola contenitrice di
CENTRALINO.

2 giorni ca.

- | Creazione di questo documento | 2 giorni ca.
Tabella 2
- Strumenti utilizzati (Software).
- Fritzing: è un software libero per la progettazione elettronica, focalizzato sul

passaggio da semplici prototipi al circuito stampato da inviare alla produzione.

Utile a disegnare il prototipo del circuito ancora prima che venga costruito.

- Arduino IDE: è l'ambiente di sviluppo integrato (Integrated Development

Enviroment) di Arduino, è un'applicazione multipiattaforma in Java usata per

compilare il codice con cui viene programmato il microcontrollore che gestisce i

| sensori e gli altri componenti.
- AliExpress: è un ramo dell'azienda "Alibaba Group" che unisce imprese cinesi e

offre un servizio di vendita al dettaglio a un mercato internazionale, rivolgendosi

prevalentemente a compratori europei. E' il fornitore dei componenti.

- MIT App Inventor (Framework): è una applicazione web creata da Google ma ora

posseduto dal Massachusetts Institute of Technology. Un ambiente di sviluppo

utile a creare applicazioni per android di uso personale.

- BlueStacks : è un'applicazione creata dall'azienda americana BlueStacks Systems

Inc. nel 2011. BlueStacks App Player è un emulatore di app android per i sistemi

operativi MacOS e Windows. Le caratteristiche principali sono l'ambiente

completamente personalizzabile, il supporto per molteplici configurazioni di

| sistema operativo e l'integrazione con Google Play.

- Strumenti utilizzati (Hardware):
- Saldatore.
- Cacciaviti vari.
- Stagno.
- Silicone liquido.
- Strumenti di misura di precisione.
- Spiegazione del codice e le sue funzionalità e particolarità.
- (Si trova nella sezione apposita "codici e relative spiegazioni").
- Problematiche degne di nota affrontate nella creazione del codice.
- (Si trova nella sezione apposita "codici e relative spiegazioni").
- Manutenzione.
- CENTRALINO è completamente autonomo e non necessità di manutenzione. Se

si desidera effettuare un aggiornamento del software è possibile farlo connettendo

il microcontrollore di CENTRALINO ad un qualsiasi dispositivo provvisto di

compilatore ARDUINO IDE e scaricando il codice open source fornito. Il codice

aggiornato di CENTRALINO si trova sul sito di hosting GitHub all'indirizzo web:

- " https://github.com/CENTRALINOproject "

Applicazione software CENTRALINO

Documentazione generale di progetto :

- Idea del progetto.
- L'idea di CENTRALINO si concretizza solamente con la creazione di un mezzo

che ne rende immediato l'utilizzo. La soluzione per questo progetto è stata quella

di creare un'applicazione che rendesse intuitivo l'utilizzo del dispositivo e di

conseguenza l'utilizzo delle sue funzionalità. Nulla esclude che un domani

CENTRALINO non possa essere controllato da un qualsiasi dispositivo capace di

trasmettere messaggi Bluetooth.

- Caratteristiche.
- L'applicazione riconosce da se stessa se il dispositivo su cui è eseguita può

supportare le sue funzionalità e le quando non lo è lo segnala con notifiche

all'utente.

- Per essere il più intuitiva possibile l'applicazione è stata creata tenendo in mente

un principale obbiettivo fisso ovvero "la semplicità". Si desiderava che l'utente

trovandosi davanti ad una nuova interfaccia non si trovasse mai spiazzato e perciò

è stata adottata una tecnica stilistica sviluppatasi ffin dalla metà del 1900, ovvero

il minimalismo (Minimal art). Le icone risultano perciò quasi scarne e i colori

sono ridotti al minimo (bianco e nero).

- Interfaccia utente.
- Nelle seguenti tabelle e paragrafi si mostrano le funzionalità del "Menù a

scorrimento" e del "pannello dei pulsanti". Nelle seguenti tabelle si parla spesso di

"accendere" / "spegnere" / "accensione" / "spegnimento"; in questi casi ci si riferisce sempre all'accensione e lo spegnimento dei dispositivi connessi al

dispositivo fisico CENTRALINO.

- L'interfaccia deve dare modo all'utente di impostare le tre attività offerte

dall'applicazione, ovvero : Spegnimento/accensione istantaneo/a, Sveglia

(permette di impostare l' accensione/spegnimento ad orari precisi), Timer

(permette di impostare l' accensione/spegnimento ad un intervallo di tempo

preciso).

- L'interfaccia è stata completamente realizzata partendo da zero. Persino le icone

sono state curate poiché era impossibile trovare immagini che fossero "adatte" o

che in generale calzassero per l'effetto che si intendeva ottenere.

- L'interfaccia utente si struttura di 2 schermate principali (il codice si trova nel

paragrafo successivo):

- Home (pagina iniziale).
- Schermata delle attività (nel codice "Default_screen").
- La "schermata delle attività" si può a sua volta scomporre in due macro aree:
- Menù a scorrimento (nel codice "Slider_container").
- Pannello dei pulsanti (nel codice "Button_panel"). Permette di accedere

alle varie aree del "Menù a scorrimento".

Menù a scorrimento

Nome | Icona (se presente) | Nome nel codice | Funzione
Imposta manualmente | | Sveglia / Timerpicker_timer | Permette di scegliere manualmente l'orario a cui si vuole impostare l'accensione o lo spegnimento .

Interruttore
acceso/spento
| Toggle_on_off | Fa si che all'orario
| | impostato dell'utente
| | CENTRALINO spenga
| | o accenda.
Pulsante di conferma | Set_clock_send /
| Confirm_timer | Conferma l'attività che
| | si vuole e la imposta su
| | CENTRALINO.
Slider del tempo | Slider_canvas | Permette di impostare
| | manualmente il tempo
| | del timer.

Pulsante
spegnimento/accensione
istantaneo/a

Hexagon_button Permette di spegnere/accendere Istantaneamente. Il colore del pulsante cambia in base allo stato della presa di corrente.

Pulsante comandi
vocali

Hexagon_button Permette di controllare con la voce i dispositivi collegati a CENTRALINO utilizzando i comandi "spegni (nome dispositivo)" e "accendi (nome dispositivo)".

Pulsante di
sincronizzazione
Sync_button | Se premuto effettua la sincronizzazione dei dispositivi connessi al dispositivo fisico CENTRALINO con l'applicazione.

Tabella 3

Pannello dei pulsanti

Nome | Icona (se presente) | Nome nel codice | Funzione
Apri-sezione destra | | Right_button | Apre la sezione destra del menù, le sezione per la funzione Timer.

Selezione
dispositivo
| Bluetooth_picker | Apre il menù a lista che
| | permette di scegliere tra i
| | dispositivi associati tramite
| | Bluetooth.
Apri-sezione sinistra | Left_button | Apre la sezione destra del
| | menù, le sezione per la
| | funzione Sveglia.

Tabella 4

- Simulazioni.
- Sono state effettuate delle simulazioni sull'emulatore di sistemi Android

BlueStacks versione 2.0.8.5638 e sul dispositivo Samsung S5 con sistema

operativo Android versione 5.0 con esiti positivi.

- Architettura di sistema
- Si rimanda alla lettura del paragrafo sull'architettura di sistema presente nel

capitolo "Dispositivo fisico CENTRALINO".

- Specifiche implementative
- Per funzionare ed essere implementato l'applicazione CENTRALINO necessità

solamente di una connessione Bluetooth con il dispositivo fisico CENTRALINO e

che il dispositivo su cui è installata l'applicazione supporti l'applicazione stessa

(sistemi operativi Android 4.0 / 5.0 / 6.0).

Documento tecnico :

- Si rimanda alla lettura della Tabella 2 presente nel capitolo "dispositivo fisico

CENTRALINO".

- Codice (Si trova nella sezione apposita "codici e relative spiegazioni").

- Spiegazione del codice e le sue funzionalità e particolarità (Si trova nella sezione

apposita "codici e relative spiegazioni").

- Problematiche degne di nota affrontate nella creazione del codice (Si trova nella sezione

apposita "codici e relative spiegazioni").
- Manutenzione.
- L'applicazione CENTRALINO non necessità di manutenzione e verrà aggiornata

ogni volta che si troverà un difetto o verrà introdotta una nuova funzione. Essa

potrà essere scaricata gratuitamente dalla pagina di GitHub ufficiale di

CENTRALINO citata nel seguente punto.

- L'applicazione di CENTRALINO si trova al seguente indirizzo web e per

scaricarla non è necessaria nessuna registrazione.

- " https://github.com/CENTRALINOproject "

Licenze.

- Il software di CENTRALINO è registrato secondo la MIT License. La MIT

License "è una licenza permissiva, cioè permette il riutilizzo nel software

proprietario sotto la condizione che la licenza sia distribuita con tale software."

- Relativa etichetta :
- Il software dell'applicazione di CENTRALINO è anche esso distribuito secondo

la stessa licenza. In più bisogna specificare che l'applicazione è stata creata con

l'applicazione web "MIT AppInventor 2.0 Beta" che si basa sulle teorie

dell'apprendimento del costruzionismo ("Il costruzionismo è basato sulla teoria

del costruttivismo secondo la quale l'individuo che apprende costruisce modelli

mentali per comprendere il mondo intorno a lui. Il costruzionismo sostiene che

l'apprendimento avviene in modo più efficiente se chi apprende è coinvolto nella

produzione di oggetti tangibili"). MIT AppInventor gode della sua propria

licenza, le applicazioni create con esso sono perciò soggette anche ad essa.

- Per quanto riguarda la forma fisica di CENTRALINO, la componentistica di

CENTRALINO sono aspetti non ancora tutelati da nessuna licenza o brevetto data

la non totale certezza di quali componenti si utilizzeranno in futuro, tuttavia

quando verranno rese di pubblico dominio le caratteristiche saranno distribuite

secondo la licenza Attribution-ShareAlike 4.0 International (CC BY-SA 4.0)

- Relativa etichetta :

Codici e relative spiegazioni.

Codice dispositivo fisico CENTRALINO

- Codice per microcontrollore Arduino.

{Versione del codice CLIENTinoBETA1.4.ino}

#include <MemoryFree.h>

#include <SoftwareSerial.h>

#include <IRremote.h>

#include <string.h>

#define rxPin 9

#define txPin 10

#define RECV_PIN 4

/***************************PLEASE MODIFY THIS LINE WHEN NEEDED*************************/ #define total_relay 2 // Total number of relay connected

#include <Wire.h>

#include "RTClib.h"

#include <TimeAlarms.h>

#include <TimeLib.h>

#include <Time.h>

/********RTC*********************/ RTC_DS1307 rtc;
tmElements_t tm;

#if defined(ARDUINO_ARCH_SAMD)

// for Zero, output on USB Serial console, remove line below if using programming port to program the Zero!
#define Serial SerialUSB

#endif

/********BLUETOOTH***************/ SoftwareSerial bluetooth(rxPin, txPin);

/*******Infra-Red****************/ IRrecv irrecv(RECV_PIN);
decode_results results;

String bluetooth_Buffer;

struct function
{
int activity;
int extra_value;
int extra_value2;
} function_temp;

struct relay
{
int socket = 0;
int hour_daily_end = 61;
int minute_daily_end = 61;
int second_daily_end_and_start = 0; int hour_daily_start = 61;
int minute_daily_start = 61;

int timer_off_hour = 61;
int timer_off_minute = 61; int timer_off_second = 61;

int timer_on_hour = 61;
int timer_on_minute = 61;
int timer_on_second = 61;

int description = 0;
} rel[total_relay];

void all_rel_HIGH()
{
for (int i=0; i<total_relay ;i++)
{
digitalWrite(rel[i].socket, HIGH); Serial.print("Impostato ad HIGH pin n. "); Serial.print(rel[i].socket); Serial.print(" per struttura rel[] n. "); Serial.println(i);
}
}

void init_output_rel()
{

for (int i=0; i<total_relay ;i++)
{
pinMode(rel[i].socket, OUTPUT); Serial.print("Inizializzato pin n. "); Serial.print(rel[i].socket); Serial.print(" per struttura rel[] n. "); Serial.println(i);
}
}

void setup ()
{
/*
#ifndef ESP8266

while (!Serial); // for Leonardo/Micro/Zero #endif
*/
Serial.begin(9600); //set baud rate bluetooth.begin(9600);
init_output_rel(); //Declare output all relays all_rel_HIGH(); //Set HIGH all relays delay(1000);

irrecv.enableIRIn(); // Start the receiver //FOR DEBUG
/* Serial.begin(57600);
if (! rtc.begin()) {
Serial.println("Couldn't find RTC"); while (1);
}
*/

if (! rtc.begin()) {
Serial.println("Couldn't find RTC"); while (1);
}
if (! rtc.isrunning()) {
Serial.println("RTC is NOT running!");
rtc.adjust(DateTime(F(__DATE__), F(__TIME__)));
// rtc.adjust(DateTime(year, month, day, hour, min, sec)); IF NEED ADJUSTMENTS }
DateTime now = rtc.now();
setTime(now.hour(),now.minute(),now.second(),now.month(),now.day(),now.year());

/*********PLEASE HERE DECLARE THE PIN'S OF THE RELAYS, ONE EACH REL[] STRUCTURE*******/ //example : rel[].socket = pin connected to relay ;

rel[0].socket = 6;
rel[0].description = 1;
rel[1].socket = 7;
rel[1].description = 3;

}
void printDigits(int digits) {
Serial.print(":");
if(digits < 10)
Serial.print('0');
Serial.print(digits);
}

void digitalClockDisplay()
{
// digital clock display of the time DateTime now = rtc.now();
Serial.print(now.hour());
printDigits(now.minute()); printDigits(now.second()); Serial.println();
}

bool ir_handler(decode_results *results) {
if (results->value == 0xA90 ) turn_off();
else
return false;
}

void bluetooth_handler()
{
char check = ' ';
check = bluetooth.read();
if ((int(check)!= 13)&&(int(check)!= 10 )&&(int(check)!= 32)) //Ignore '\r' , '\n' and spaces bluetooth_Buffer += check;
else
{
Serial.println("Relivated unprintable chars, ASCII value is : "); Serial.println(int(check));
}
Serial.print("Value of bluetooth buffer is = '"); Serial.print(bluetooth_Buffer); Serial.println("'");

if (check==']')
bluetooth_Parser();
}

/********************************MEANINGS OF DESCRIPTIONS********************************* 1 = Lamp
2 = Chandelier
3 = Computer
4 = Fridge
5 = Fan
6 = Microwave
7 = Charger
8 = Electric shutter
9 = Amplifier
10 = Speakers
11 = Aircooler
12 = Confetti's cannon
*****************************************************************************************/

/**********************STRUCTURE BLUETOOTH PACKAGE**************************************** * ('figures' in italian : 'cifre')
* ([) Message opening 1 position : [0]
* (1st number, two figures) Activity 2 position : [2]
* (,) 1 position : [3]
* (2nd number , four figures) Extra_value 4 position : [7] * (,) 1 position : [8]
* (3rd number , six figures) Extra_value2 6 position : [14]
* (]) message closer 1 position : [15] Total = 16 *****************************************************************************************/

void bluetooth_Parser()
{ Serial.println("Open bluetooth parser");
if (int(bluetooth_Buffer.length())!=16) //Hard coded dimensions and particularities of the message
{Serial.println("Lenght check not passed"); Serial.println(int(bluetooth_Buffer.length()));
bluetooth_Buffer = "";}
else if (bluetooth_Buffer[0]!='[') {Serial.println("Opener check not passed"); Serial.println(bluetooth_Buffer[0]); bluetooth_Buffer = "";}
else if (bluetooth_Buffer[3]!=',') {Serial.println("First comma check not passed"); Serial.println(bluetooth_Buffer[3]); bluetooth_Buffer = "";}
else if (bluetooth_Buffer[8]!=',') {Serial.println("Second comma check not passed"); Serial.println(bluetooth_Buffer[8]); bluetooth_Buffer = "";}

else if (bluetooth_Buffer[15]!=']') {Serial.println("Closer check not passed"); Serial.println(bluetooth_Buffer[15]); bluetooth_Buffer = "";}
else
{ String temp_string;
long temp=0;

Serial.print("Received package : ");
Serial.println(bluetooth_Buffer);
temp_string=bluetooth_Buffer.substring(1,3); // substring (from [index] ,to [index we want in the sub +1])// https://www.arduino.cc/en/Reference/StringSubstringtemp=atoi(temp_string.c_str());
function_temp.activity = int(temp);
Serial.print("Received activity : "); Serial.println(function_temp.activity); temp_string=bluetooth_Buffer.substring(4,8); temp=atoi(temp_string.c_str()); function_temp.extra_value = int(temp); Serial.print("Received extra_val : "); Serial.println(function_temp.extra_value); temp_string=bluetooth_Buffer.substring(9,15); temp=atoi(temp_string.c_str()); function_temp.extra_value2 = int(temp); Serial.print("Received extra_val2 : "); Serial.println(function_temp.extra_value2);

bluetooth_Buffer=""; //Reset buffer for new packets

activity_manager();
}
}

// ACTIVITY MANAGER
void activity_manager ()
{ Serial.println("Open activity manager"); Serial.println(function_temp.activity);
digitalClockDisplay();
if (function_temp.activity == 1) // Turn OFF relay n. extra_value turn_off();
if (function_temp.activity == 2 ) // Turn On relay n. extra_value turn_on();

if (function_temp.activity == 3 ) // Set timer to turn ON relay n. extra_value in time extra_value2

set_timer_on();

if (function_temp.activity == 4 ) // Set timer to turn OFF relay n. extra_value in time extra_value2
set_timer_off();
if (function_temp.activity == 5 ) // Set daily START on relay n. extra_value in time extra_value2
set_daily_start();

if (function_temp.activity == 6 ) // Set daily END on relay n. extra_value in time extra_value2
set_daily_end();

if (function_temp.activity == 50 ) // REQUEST of OFFER bluetooth_offer();

// 51 is an OFFER package (Will never be received on CLIENTino)
// 99 is a CLOSE communication_packet (Will never be received on CLIENTino)*/

return;
}

void bluetooth_offer()
{
Serial.println("Offer now :");
for (int i=0; i<total_relay; i++)
send_package(51, rel[i].socket, rel[i].description ); send_package(99, 0, 0); //Close comunication return;
}

void send_package(int activity, int extra_value, int extra_value2) { //Serial.println("FLAG send package");
//Serial.println("Send package"); //Serial.print("freeMemory()=");
//Serial.println(freeMemory());
if ((activity>99)||(extra_value>9999)||(extra_value2>999999))
{
Serial.println("Unable to send the packet because of uncorrect values"); }
else
{

String packet = "";
String aux_activity = zero_padd(activity, 2); //Serial.println("THIS IS AUX ACT"); //Serial.println(aux_activity);
String aux_extra_value = zero_padd(extra_value, 4); //Serial.println("THIS IS AUX EXTRA"); //Serial.println(aux_extra_value);
String aux_extra_value2 = zero_padd(extra_value2, 6); //Serial.println("THIS IS AUX EXTRA 2"); //Serial.println(aux_extra_value2);

packet += '[';
packet += aux_activity;
packet += ',';
packet += aux_extra_value; packet += ',';
packet += aux_extra_value2; packet += ']';

Serial.print("This is packet"); Serial.println(packet); //packet.concat(aux_activity) bluetooth.print(packet);
}
return;
}

String zero_padd(int value, int spaces) { Serial.println("FLAG zero_padd"); String result="";
Serial.println("FLAG zero_padd1"); int padds=spaces, aux_value=value; Serial.println("FLAG zero_padd2");

if(aux_value!=0)
{
do
{
Serial.println("FLAG zero_padd3"); Serial.println(aux_value);
if (aux_value > 0)
{
aux_value = aux_value / 10; Serial.println("This is aux after /10"); Serial.println(aux_value);
padds--;
}

}
while (aux_value > 0);

}
else
{
padds=spaces-1;
}
Serial.print("This is value :"); Serial.println(value);
Serial.print("This is spaces :"); Serial.println(spaces);
Serial.print("This is padds :"); Serial.println(padds);
if (padds!=0)
{
if (padds==1)
result="0";
else if (padds==2)
result="00";
else if (padds==3)
result="000";
else if (padds==4)
result="0000";
else if (padds==5)
result="00000";
else if (padds==6)
result="00000";
}

result.concat(value);

return result;
}

void set_timer_off()
{
rel[function_temp.extra_value].timer_off_hour = hour()+function_temp.extra_value2/3600; rel[function_temp.extra_value].timer_off_minute = minute()+function_temp.extra_value2/60; rel[function_temp.extra_value].timer_off_second = second()+function_temp.extra_value2%60; adjust_timer_off();
}

void set_timer_on()
{

rel[function_temp.extra_value].timer_on_hour = hour();//+function_temp.extra_value2;///3600; rel[function_temp.extra_value].timer_on_minute = minute();//+function_temp.extra_value2;///60; rel[function_temp.extra_value].timer_on_second = second()+function_temp.extra_value2 ;//%60; adjust_timer_on();
}

void adjust_timer_on()
{
if(rel[function_temp.extra_value].timer_on_second >= 60) {
rel[function_temp.extra_value].timer_on_minute = rel[function_temp.extra_value].timer_on_minute + rel[function_temp.extra_value].timer_on_second / 60; rel[function_temp.extra_value].timer_on_second = rel[function_temp.extra_value].timer_on_second % 60; }

if(rel[function_temp.extra_value].timer_on_minute >= 60)
{ rel[function_temp.extra_value].timer_on_hour = rel[function_temp.extra_value].timer_on_hour + rel[function_temp.extra_value].timer_on_minute / 60 ; rel[function_temp.extra_value].timer_on_minute = rel[function_temp.extra_value].timer_on_minute % 60;
}

if(rel[function_temp.extra_value].timer_on_hour >= 24) rel[function_temp.extra_value].timer_on_hour = rel[function_temp.extra_value].timer_on_hour % 24;

}

void adjust_timer_off()
{
if(rel[function_temp.extra_value].timer_off_second >= 60) {
rel[function_temp.extra_value].timer_off_minute = rel[function_temp.extra_value].timer_off_minute + rel[function_temp.extra_value].timer_off_second / 60; rel[function_temp.extra_value].timer_off_second = rel[function_temp.extra_value].timer_off_second % 60; }

if(rel[function_temp.extra_value].timer_off_minute >= 60)

{ rel[function_temp.extra_value].timer_off_hour = rel[function_temp.extra_value].timer_off_hour + rel[function_temp.extra_value].timer_off_minute / 60 ; rel[function_temp.extra_value].timer_off_minute = rel[function_temp.extra_value].timer_off_minute % 60; if(rel[function_temp.extra_value].timer_off_hour >= 24) rel[function_temp.extra_value].timer_off_hour = rel[function_temp.extra_value].timer_off_hour % 24;
}
}

void set_daily_end()
{
rel[function_temp.extra_value].hour_daily_end = function_temp.extra_value2/100; rel[function_temp.extra_value].minute_daily_end = function_temp.extra_value2%100; }

void set_daily_start()
{
rel[function_temp.extra_value].hour_daily_start = function_temp.extra_value2/100; rel[function_temp.extra_value].minute_daily_start = function_temp.extra_value2%100; }

int match_time(int i)
{ int result=0; //No match founded

int hour_now = hour();
int minute_now = minute();
int second_now = second();
if ( (rel[i].hour_daily_end==hour_now) && (rel[i].minute_daily_end==minute_now) ) //return 6 (same n. as activity)
if ( rel[i].second_daily_end_and_start==second_now)
{

Serial.println(" match with daily_end, I'll return 6");

result=6;
}
if ( (rel[i].hour_daily_start==hour_now) && (rel[i].minute_daily_start==minute_now)) //return 5 (same n. as activity)
if( rel[i].second_daily_end_and_start==second_now )
{
Serial.println(" match with daily_start, I'll return 5"); result=5; //Turn on founded

}
if ( (rel[i].timer_off_hour==hour_now) && (rel[i].timer_off_minute==minute_now ) ) //return 4 (same n. as activity)
if (rel[i].timer_off_second==second_now)
{
Serial.println(" match with timer_off, I'll return 4"); rel[i].timer_off_hour = 61;
rel[i].timer_off_minute = 61;
rel[i].timer_off_second = 61;
result=4;
}
if ( (rel[i].timer_on_hour==hour_now ) && (rel[i].timer_on_minute==minute_now) ) //return 3 (same n. as activity)
if( rel[i].timer_on_second==second_now )
{
Serial.println(" match with timer_on, I'll return 3"); rel[i].timer_on_hour = 61;
rel[i].timer_on_minute = 61;
rel[i].timer_on_second = 61;
result=3;
}

return result;
}

void turn_by_match()
{ Serial.println("Checking by match : "); for (int i=0; i<total_relay; i++)
{int match_result = match_time(i);
if (match_result == 6) //daily_end turn_off_pin(i);
else if (match_result == 5) //daily_start turn_on_pin(i);
else if (match_result == 3) //timer_on turn_on_pin(i);
else if (match_result == 4) //timer_off turn_off_pin(i);
else Serial.println("No match founded"); }
}

void turn_on_pin(int index) {
digitalWrite( index , LOW); Serial.println("ON");

delay (4000);
}

void turn_off_pin(int index) {
digitalWrite( index , HIGH); Serial.println("OFF");
delay (4000);
}

void turn_off()
{
digitalWrite(function_temp.extra_value , HIGH); Serial.println("OFF");
delay (4000); //this is to not overcharge the relay }

void timer_turn_off()
{
digitalWrite( rel[function_temp.extra_value2].socket , HIGH); Serial.println("OFF");
delay (4000); //this is to not overcharge the relay
}

void timer_turn_on()
{
digitalWrite( rel[function_temp.extra_value2].socket , LOW); Serial.println("ON");
delay (4000); //this is to not overcharge the relay
}

void turn_on()
{
digitalWrite(function_temp.extra_value , LOW); Serial.println("ON");
delay (4000); //this is to not overcharge the relay }

void digitalClockDisplay_notRTC()
{
// digital clock display of the time

Serial.print(hour());
printDigits(minute());
printDigits(second());
Serial.println();
}

void loop ()
{
if(bluetooth.available())
bluetooth_handler();
if (irrecv.decode(&results)) ir_handler(&results);

digitalClockDisplay_notRTC(); turn_by_match();
Serial.print("freeMemory()="); Serial.println(freeMemory());

delay(50);
}
- Breve spiegazione
- Il codice sfrutta due strutture dati chiamate "function" e "relay". La struttura

"function" ha il compito di contenere le informazioni che vengono ricevute con i

pacchetti Bluetooth, mentre, la struttura "relay" ha il compito di contenere le

informazioni relative alle prese del dispositivo fisico CENTRALINO. Ogni

struttura "relay" avrà un suo orario di accensione e spegnimento, un suo orario per

il timer e avrà una descrizione numerica che servirà invece a far capire all'utente

che controlla CENTRALINO su quale "relay" andrà ad impartire un comando e

soprattutto l'indirizzo del pin tramite il quale il microcontrollore sa dove inviare il

segnale di accensione / spegnimento. Nel paragrafo seguente verrà spiegato

perché è stato necessario adottare tante strutture "relay" quante sono le prese.

- Il sistema di comunicazione è molto importante perché grazie ad esso si riesce ad

ottenere un livello di comunicazione all'interno del livello 7 del modello ISO/OSI

il Bluetooth infatti copre tutti e 7 i livelli dell'ISO/OSI ma senza un'ulteriore

divisione interna sarebbe stato impossibile avere più di una sola presa di corrente

allo stesso CENTRALINO (rendendolo poco flessibile). Ogni pacchetto bluetooth

è composto di 16 byte e ha un iniziatore di pacchetto "[" (ASCII: 91) e un

terminatore "]" (ASCII: 93) senza di essi non si potrebbe determinare quando un

pacchetto inizia o finisce e questo rende molto facile maneggiare i flussi di byte.

All'interno del pacchetto ci sono ulteriori divisioni date dal simbolo "," (ASCII:

44) esso serve a capire quando inizia un settore del pacchetto e ne inizia un altro,

in più danno un maggiore grado di integrità al pacchetto stesso (in caso di

trasmissioni errate se non sono presenti "," il pacchetto non verrà considerato

valido. Per maggiore comprensione guarda la funzione void bluetooth_Parser() ).

La struttura finale del pacchetto è questa.

Struttura di un pacchetto Bluetooth :

[ Activity
(2 cifre)

, Extra_value
(4 cifre)
, | Extra_value2
(6 cifre)

]

Tabella 5
- Dentro ai pacchetti si trovano i comandi impartiti dall' applicazione software

CENTRALINO. Activity varia in base Sveglia/Timer e Acceso/spento.

Extra_value contiene il numero del pin a cui deve essere indirizzata il comando.

Extra_value2 contiene nel caso della "Sveglia" il tempo in formato hh:mm:ss e

nel caso del "Timer" il tempo in millesimi di secondo.

- Il sistema ha anche un "activity handler"; esso serve ad amministrare i pacchetti

una volta che sono stati "smistati" e capire quali azioni sono richieste a

CENTRALINO. Con la variabile "activity" mostratasi nel punto precedente si

immagazzina il codice che corrisponde all'azione che CENTRALINO deve

compiere ( Es. 01 e 02 sono le "activity" che corrispdono ad Accensione e

Spegnimento istantanei). In "Extra_value" si trova il dispositivo a cui il pacchetto

sta facendo riferimento, perciò il valore che troviamo in rel[x].socket è di fatto il

pin a cui il relay è collegato e quello a cui fa riferimento Extra_value (questo

meccanismo rende indirizzabili i pacchetti ai singoli dispositivi, similmente al

"MAC address" di un computer). In "Extra_value2" si trova il valore suppletivo

che da manforte alla "activity". In "Extra_value2" si trovano ad esempio i tempi

per le "sveglie" espressi così "001650"(per motivi di integrità sono sempre 6

cifre), questa appena scritta è una sveglia per le 16 e 50.

- Esempio pacchetto : "[03,0006,001650]". Esso imposta una sveglia di

accensione alle ore 16 50 per il pin 6.

- Problematiche principali.
- Le problematiche principali sono state tante ma per comodità del lettore ne

verranno tratte solo due tra tante elencate e non.

- 1) Il microcontrollore non ha un orologio interno è perciò impossibile far

si che esso capisca da se che ore sono al momento delle attività. Questo ha

fatto si che fosse necessario un componente adibito proprio a quello (Real

Time Clock module) tuttavia questo componente non ha funzioni di

sveglia o timer era perciò necessario che il microcontrollore gestisse da se

l'orario e le scadenze delle attività. Inoltre si aggiunge l'ulteriore problema

che se due strutture "relay" avessero avuto lo stesso orario di scadenza e il tempo di acquisizione dell'orario fosse stato troppo lento c'era possibilità

che il sistema fosse troppo lento a gestire le sveglie. Si è risolto con la

funzione void turn_by_match() che controlla ogni singola struttura "relay"

in tempi molto al di sotto del secondo e fa si che sia possibile

spegnere/accendere più "relay" contemporaneamente anche quando gli

orari combaciano al secondo.

- 2) Doveva essere possibile far sapere all'applicazione software

CENTRALINO quali dispositivi erano connessi al dispositivo fisico

CENTRALINO e per fare questo era necessaria una descrizione anche

superficiale delle prese di corrente. Per questo è stata introdotta la

variabile "description" che ha una leggenda (nel codice sotto il nome di

MEANINGS OF DESCRIPTION). Il meccanismo tramite il quale

l'applicazione viene a sapere le varie "description" delle strutture "relay" è

questo :

- App. Software CENTRALINO manda pacchetto con activity = 50

ovvero una Discovery (richiede che gli vengano mandate le

informazioni).

- Disp. Fisico CENTRALINO manda tanti pacchetti quante sono le

strutture "relay" con activity = 51 e la relativa rel[].description

(description di ogni struttura) e infine manda un pacchetto con

activity = 99 che significa che i relay sono terminati e l' A.S.

CENTRALINO può smettere di aspettare che glie ne arrivino altri.

- 3) Zero padding (non affrontata sul documento).

- 4) Conflitti di formato dati e atoi() (non affrontata sul documento).

Codice applicazione CENTRALINO

- Codice descrittivo della grafica dell'applicazione.

{I seguenti documenti si trovano nel file .aia generato dal framework di App Inventor}

- Codice operativo dell'applicazione.

Per motivi di compatibilità questa parte di codice avrà un aspetto leggermente differente da

quello visto fino ad ora. Essendo App Inventor ancora in una versione BETA non è possibile

esportare i progetti in formato testuale perciò si è costretti ad esportarlo in formato grafico.

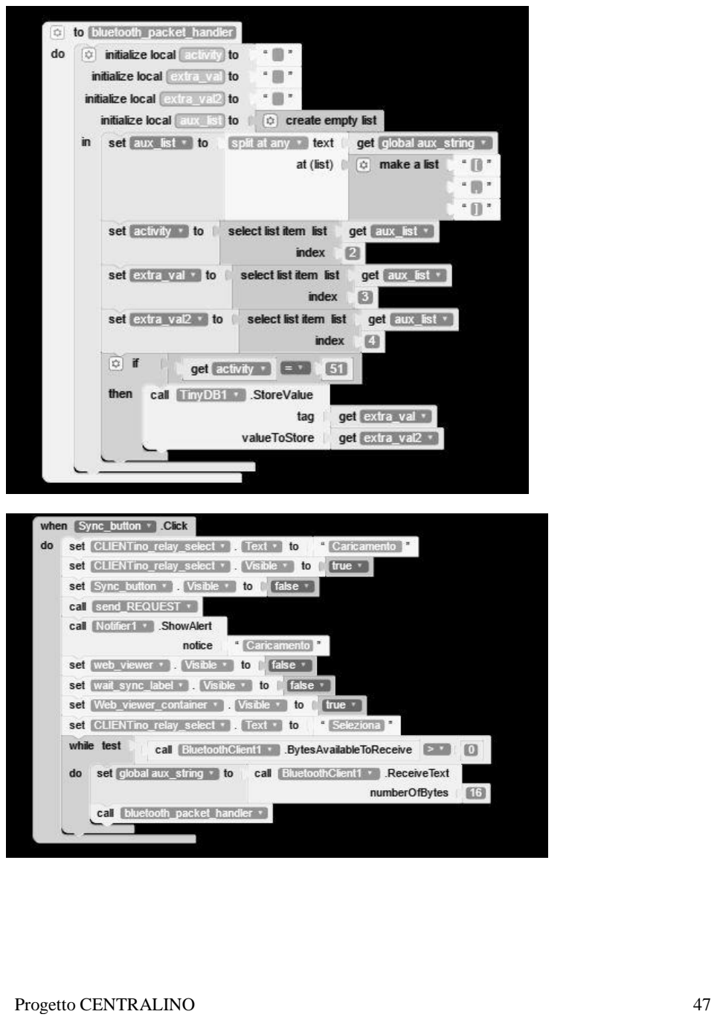
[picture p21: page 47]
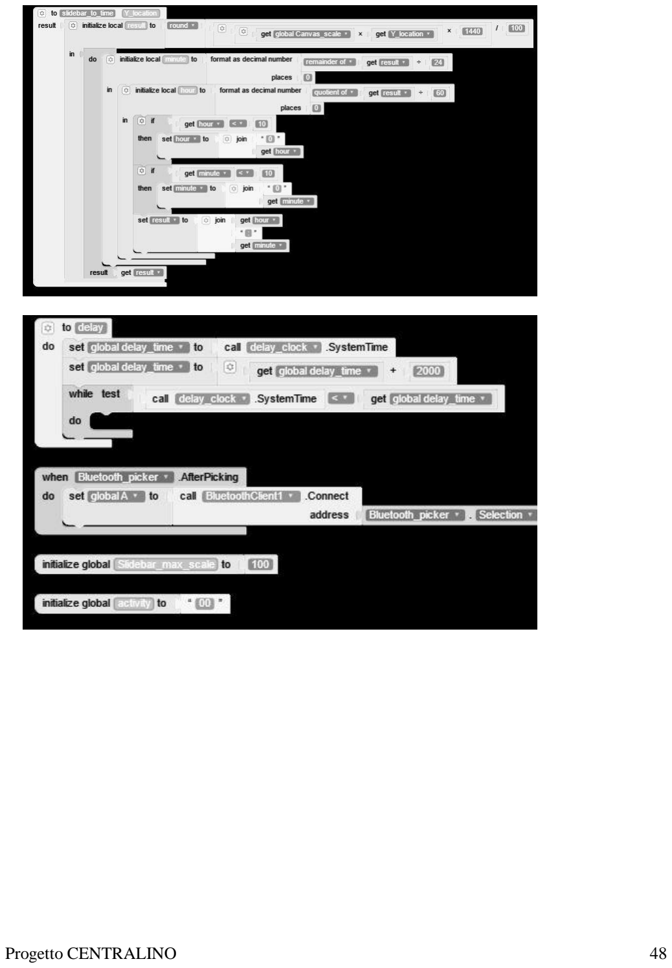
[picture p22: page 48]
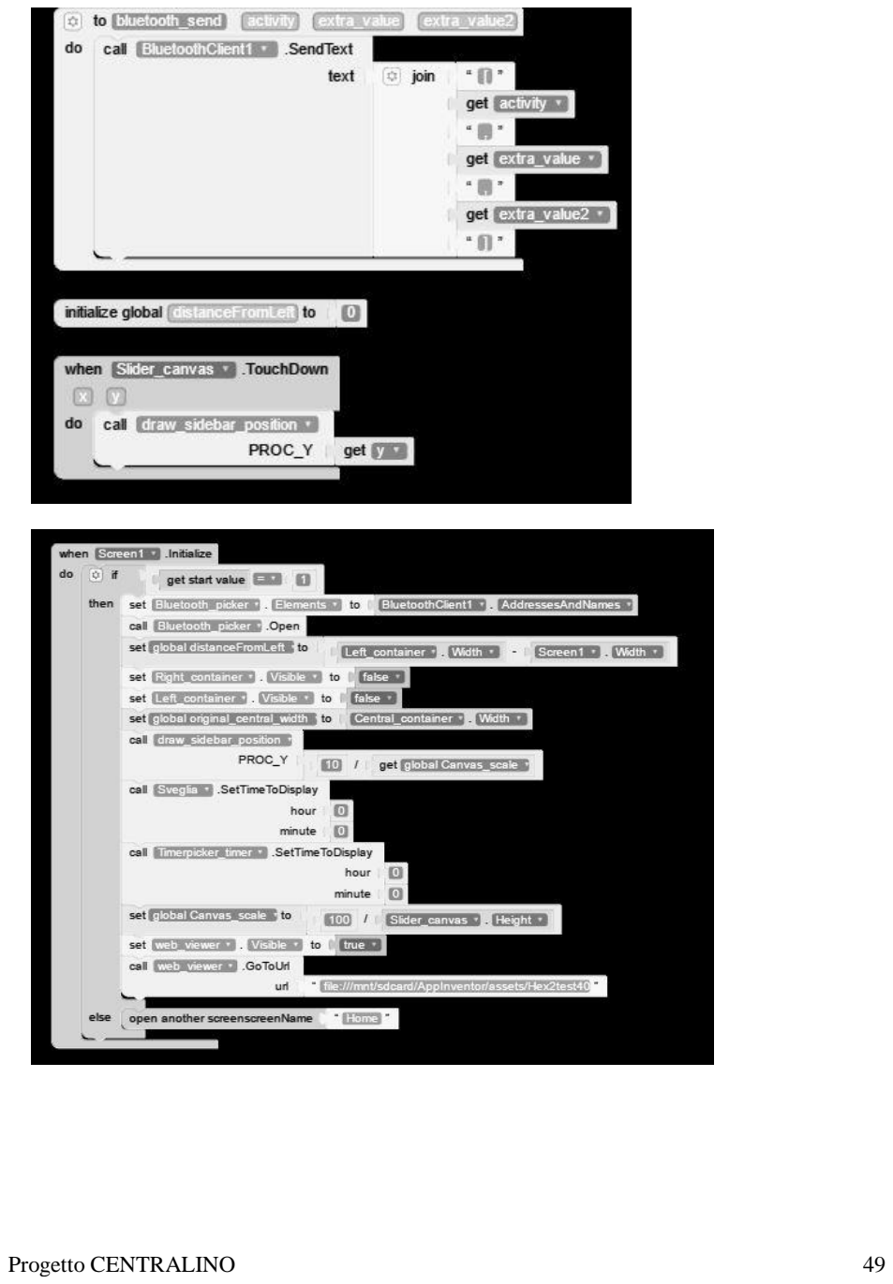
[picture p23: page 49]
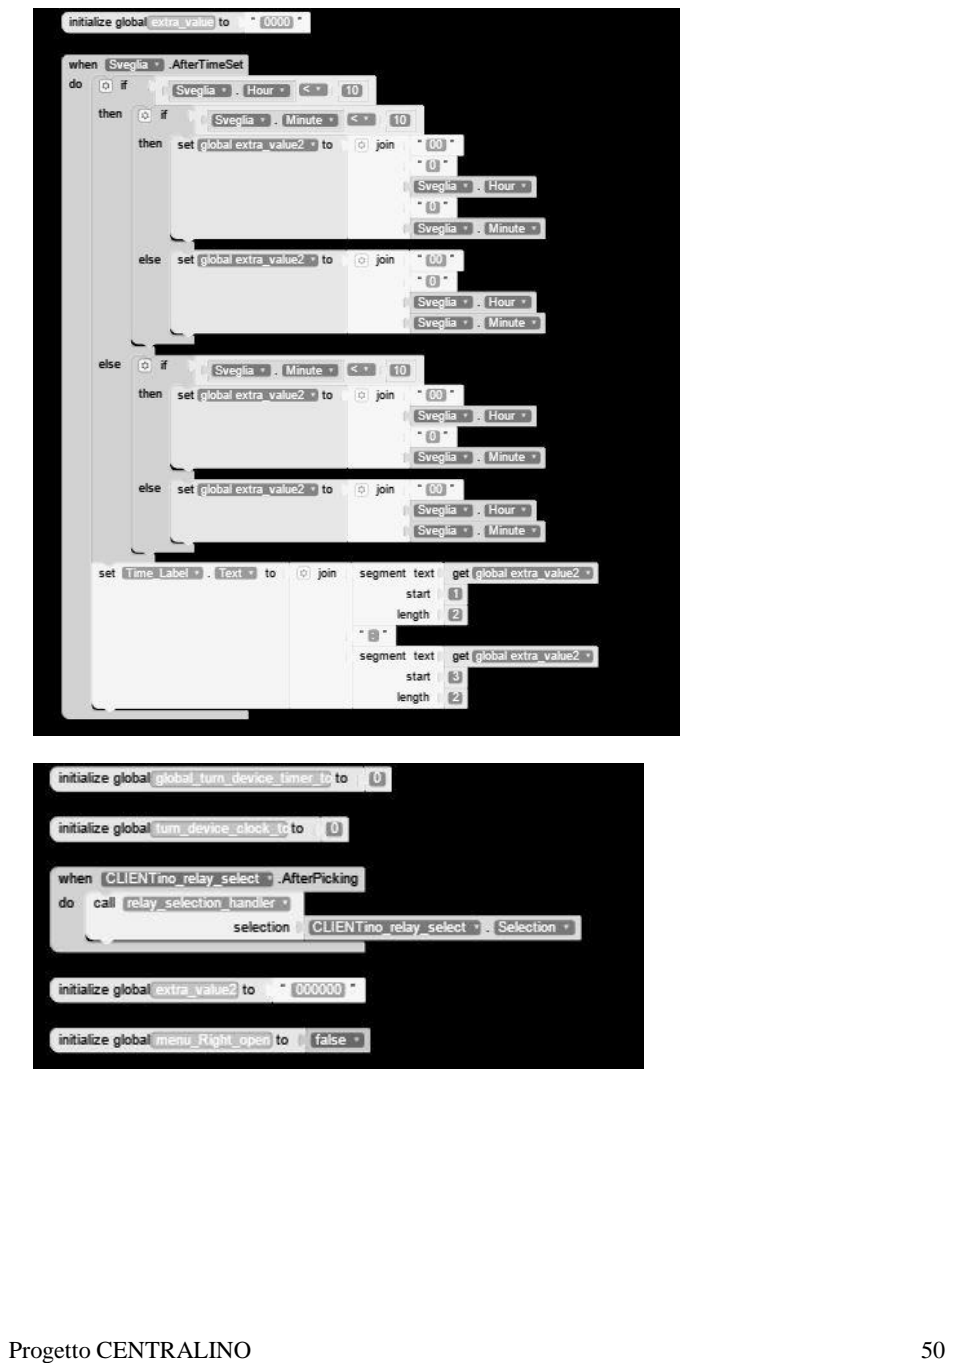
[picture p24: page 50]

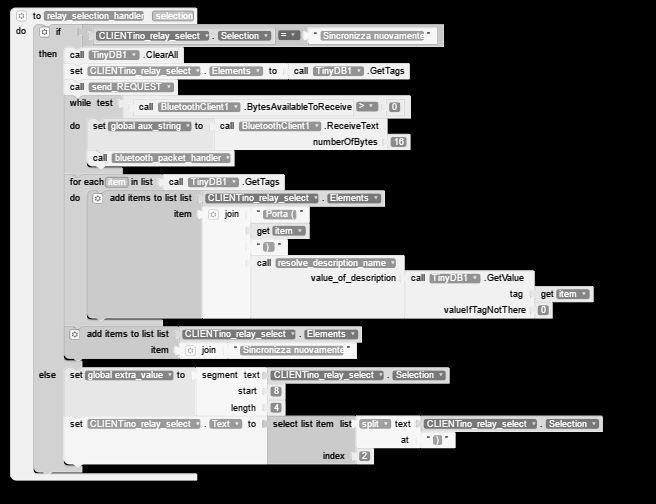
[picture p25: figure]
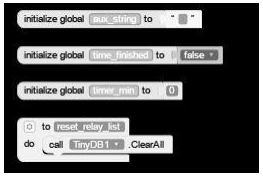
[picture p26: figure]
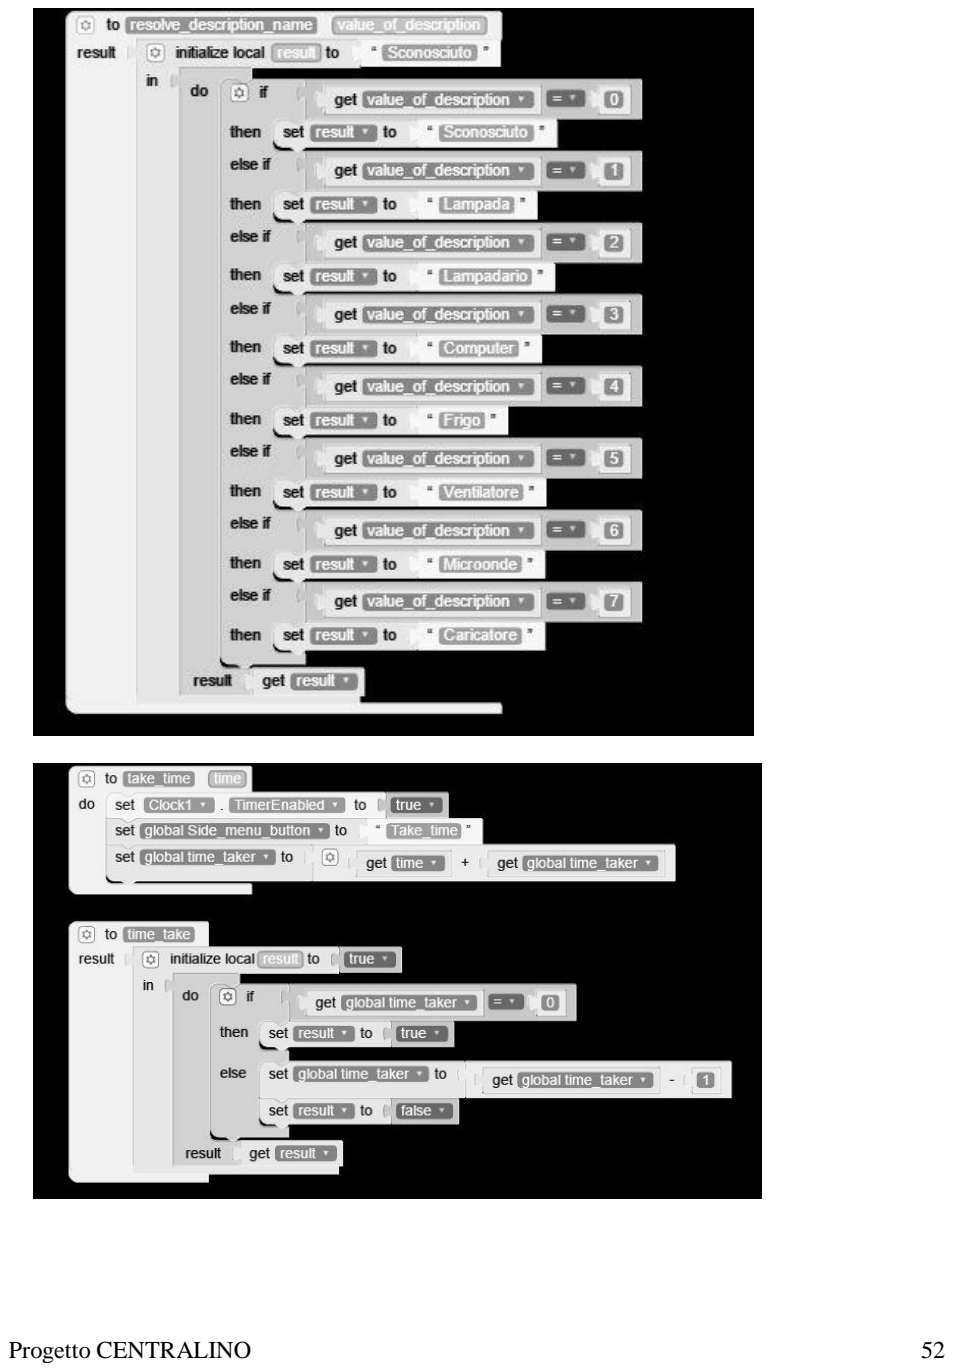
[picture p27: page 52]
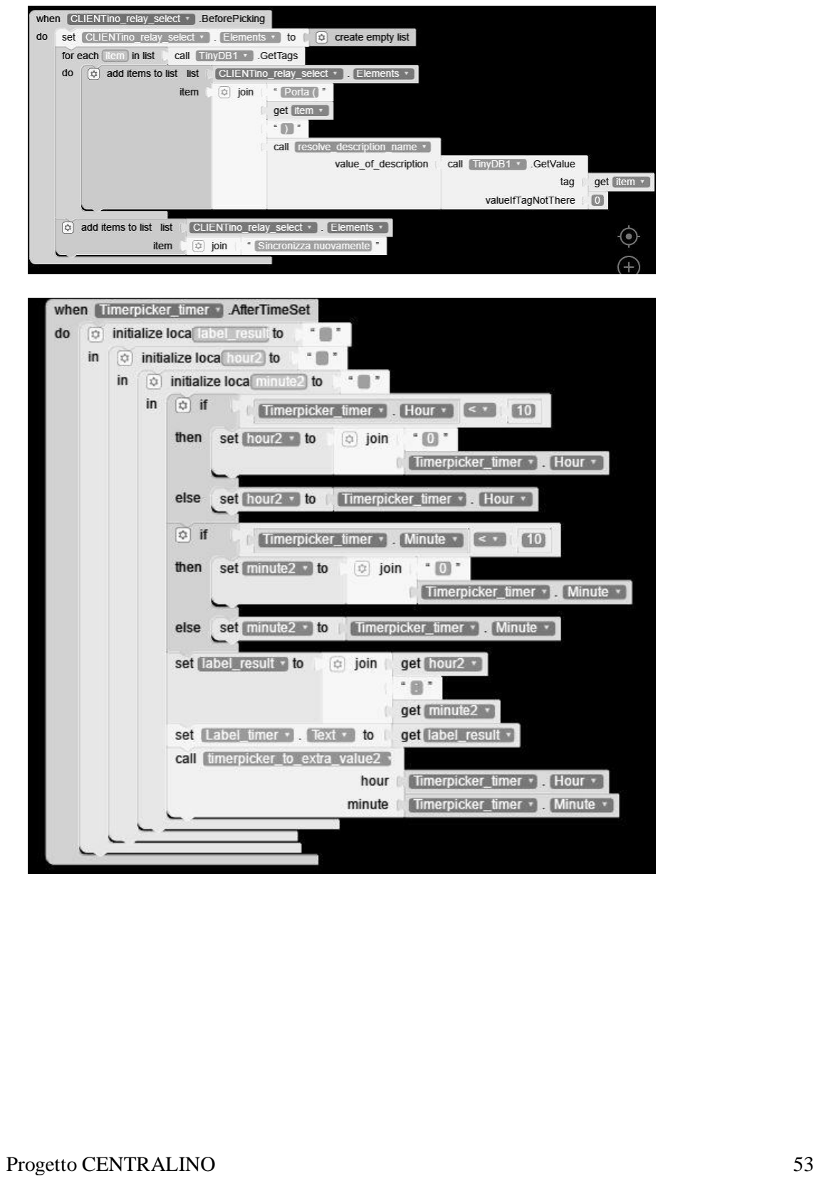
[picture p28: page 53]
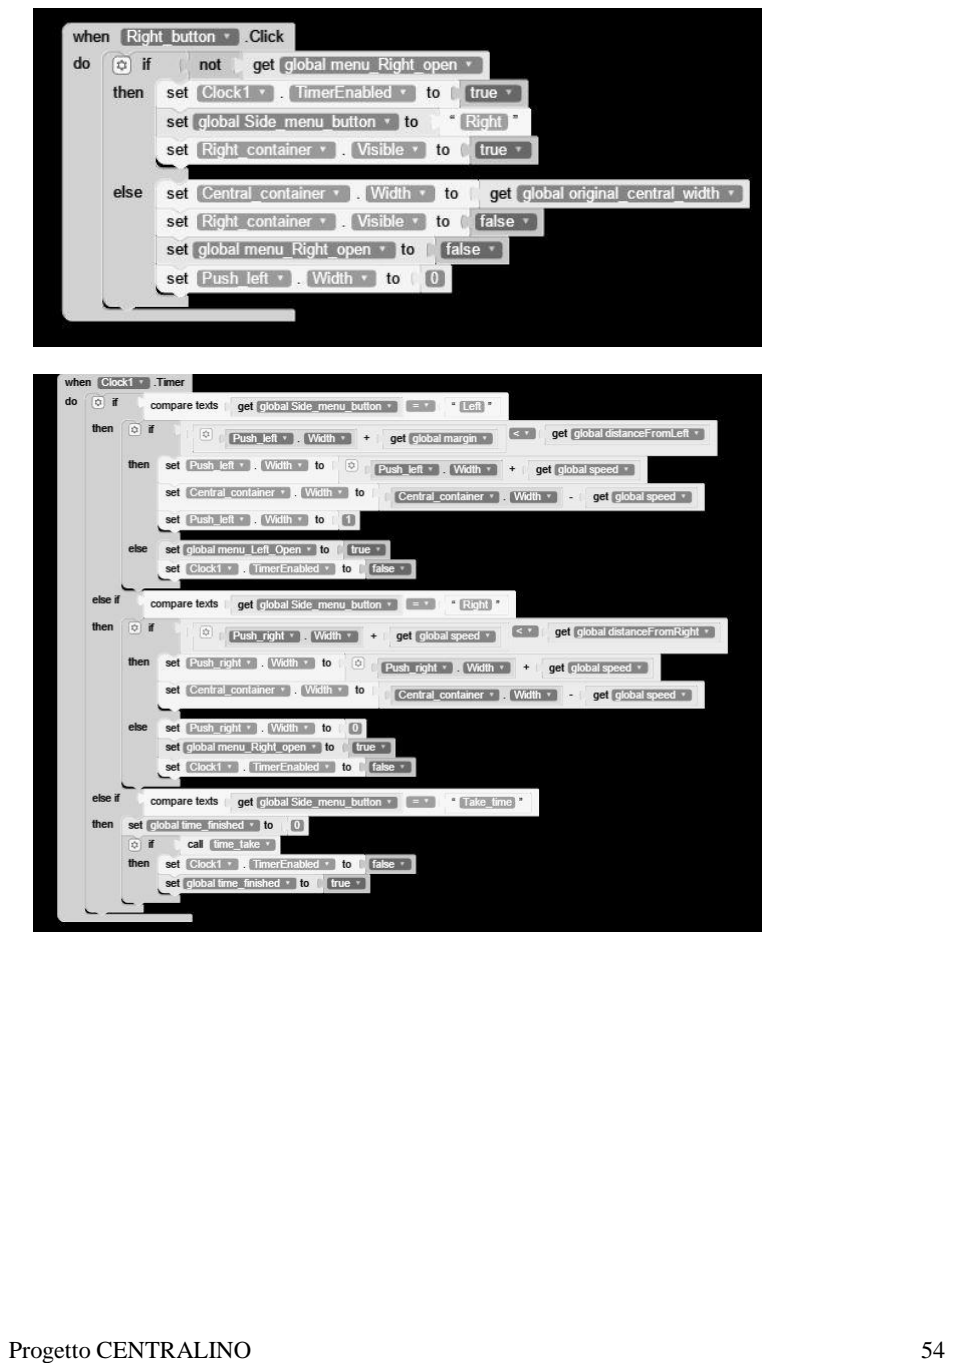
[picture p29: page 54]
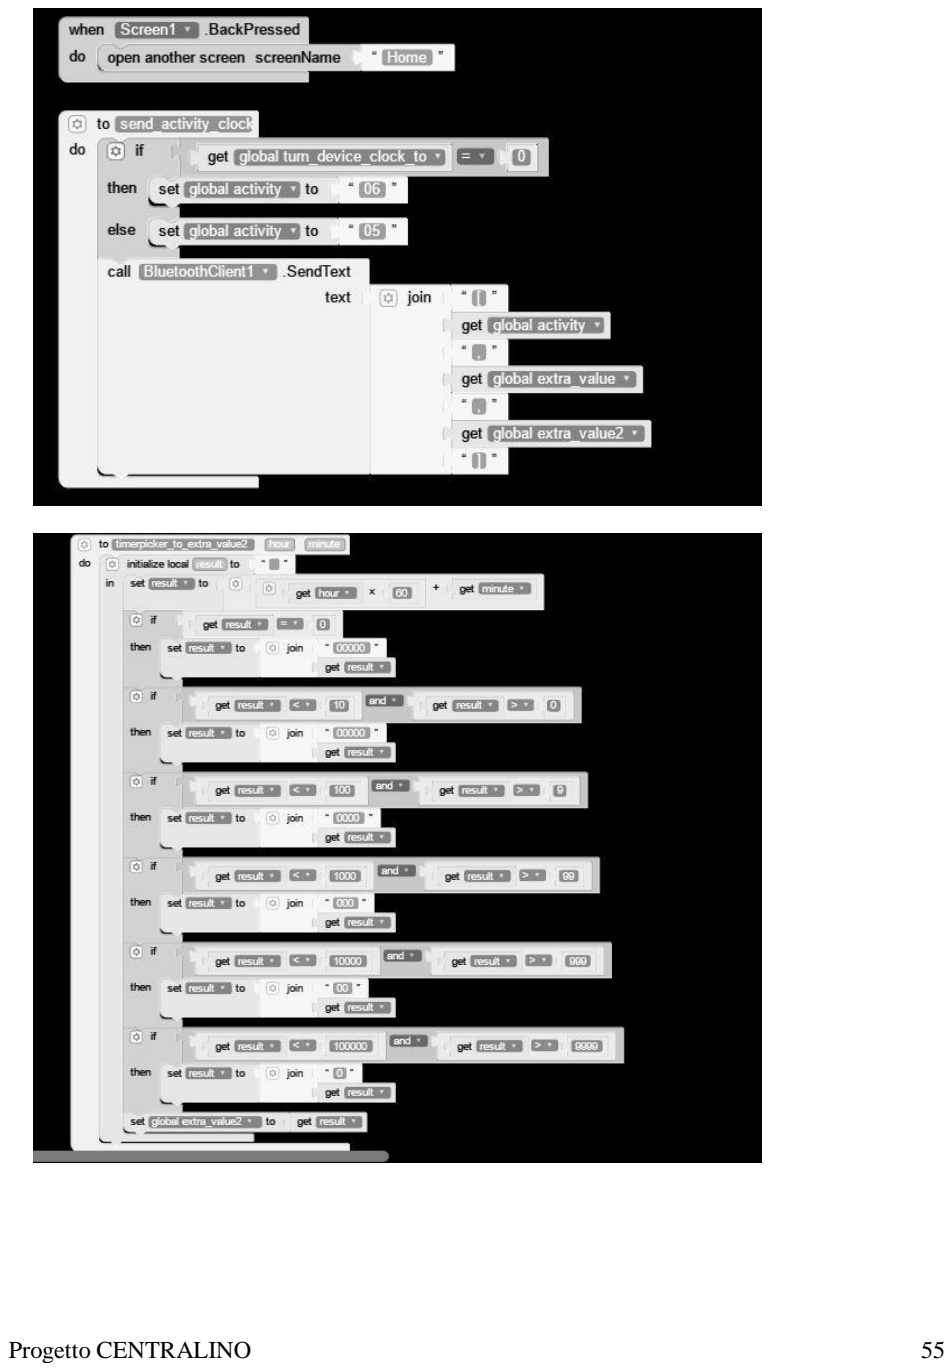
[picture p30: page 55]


- Breve spiegazione
- L'applicazione sfrutta principalmente l'utilizzo di variabili globali che vengono

continuamente usate in blocco per mandare i pacchetti con le "activity". Queste

tre variabili prendono il nome dal sistema del dispositivo fisico CENTRALINO,

pertanto si chiamano anche esse "activity", "extra_value" e "extra_value2".

- La piattaforma di sviluppo di App Inventor si basa sull'utilizzo degli eventi. Gli

eventi di Android fungono come un kernel di sistema. Essi permettono di sapere

sempre quando una determinata azione è accaduta e permettono quindi di richiamare funzioni specifiche quando quegli "eventi" si verificano. Per esempio

quando un pulsante viene premuto solleverà l'evento pulsante.onclick() e sarà

possibile chiamare una propria "procedure" (funzione) ogni qualvolta si solleverà

l'evento. Gli eventi sono molti e molto variegati. Sono stati utilizzati

principalmente gli eventi legati allo schermo ovvero "screen.BackPressed()" e

"screen.Initialize()",gli eventi legati ai pulsanti anche di vario tipo ("timePicker" e

simili) e come si può evincere dal codice operativo si è fatto largo uso

dell'oggeto/componente tinyDB con i suoi vari metodi e funzioni.

o

- Problematiche principali
- Innanzitutto il passaggio da un sistema di programmazione tradizionale ad uno

più articolato può essere fuorviante. Certamente lo è stato, iniziare a ragionare

non più per flusso di codice ma per eventi. Sapere che il codice non fa sempre le

stesse operazioni in sequenza bensì si comporta in modo differente in base agli

eventi che nascono è molto differente da ciò che è stato appreso in classe, tuttavia

con il tempo è stato possibile districarsi sempre meglio in questo tipo di mentalità

di programmazione.

- Non essendo App Inventor un vero e proprio linguaggio di programmazione è

molto raro trovare documentazione affidabile sulla sintassi dei comandi,

fortunatamente il loro funzionamento è molto intuitivo ma nei casi in cui questa

intuitività è venuta meno, c'è stato bisogno di spendere molto tempo nella ricerca

e nella comprensione di comandi adeguati al perseguimento degli obbiettivi.

- Un grande problema è stato riscontrato nell'utilizzo stesso di App Inventor proprio

per via del fatto che è una piattaforma in via di sviluppo e si trova ancora nella

fase BETA, è spesso soggetta a crash, bug di varia natura e frequenti interruzioni

di funzionamento parziale.

- Conclusioni :
- Futuri sviluppi:
- CENTRALINO come già detto è un progetto che ha ancora molte

potenzialità da sviluppare, anzi , si può dire quasi che questo primo lavoro

sia solo l'inizio. In futuro si prediligerà certamente un altro tipo di

integrazione con l'ambiente, come ad esempio, macchinari che nascono di

fabbrica con la possibilità di integrarsi in sistemi domotici.

- Dedica
- Dedico questo lavoro ai professori e i compagni che mi hanno spinto a

fare questo progetto, che hanno creduto che lo potessi fare e mi hanno

sorriso quando cercavo di spiegare cosa fosse quando ancora non aveva

forma. Ancora di più lo dedico e ringrazio i professori e i compagni che

non hanno creduto che lo potessi fare, e si sono stupiti quando il progetto

ha iniziato a prendere forma, senza l'una o l'altra non avrei avuto la spinta

necessaria a portarlo a termine.

Fonti

" https://it.wikipedia.org/wiki/Licenza_MIT "

" https://it.wikipedia.org/wiki/Costruzionismo_(teoria_dell%27apprendimento) "

" https://it.wikipedia.org/wiki/Domotica"

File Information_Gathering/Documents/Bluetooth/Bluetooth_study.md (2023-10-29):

# Studio sul Bluetooth

Il Bluethoot opera a bande di frequenze assegnato circa sui 2,45 Ghz.
Per ridurre interferenze possiede 79 canali e prevede un Frequency Hopping di 1.600 volte al secondo. (Il che lo rende estremamente sicuro per le trasmissioni).
Solo uno Slave (dispositivo associato ricevente) alla volta può comunicare con il Master (dispositivo mittente) sebbene si possano connettere fino a 7 Slave ad un solo Master.

<p align="center">
  
</p>

I collegamenti che possono essere stabiliti tra i diversi dispositivi sono di due tipi: orientati alla connessione (Connection Oriented) e senza connessione (Connectionless).
Un collegamento orientato alla connessione richiede di stabilire una connessione tra i dispositivi prima di inviare i dati;
mentre, un link senza connessione non richiede alcuna connessione prima di inviare i pacchetti.

La tecnologia Bluetooth definisce due tipi di collegamenti a supporto delle applicazioni voce e trasferimento dati: 
Un servizio asincrono senza connessione (ACL, Asynchronous ConnectionLess) 
Un servizio sincrono orientato alla connessione (SCO, Synchronous Connection Oriented).

## Stati di un dispositivo Bluetooth

Un dispositivo Bluetooth si può trovare essenzialmente in due stati: in quello di connessione o in quello di standby. L'unità si trova nello stato di connessione se è connesso ad un altro dispositivo ed è coinvolto con esso alle normali attività. Se il dispositivo non è connesso, o non è coinvolto alle attività della piconet, allora esso si trova automaticamente nello stato di standby. Questo stato è stato concepito come un modo per far risparmiare energia ai dispositivi. Se uno di essi non è coinvolto attivamente all'interno di una connessione, non c'è motivo che assorba picchi di potenza pari a quelli dei dispositivi attivi. Quando un'unità si trova in standby ascolta il canale ogni 1,28 secondi per eventuali messaggi dal master.

## Modalità di un dispositivo Bluetooth

Quando un dispositivo passa dallo stato di standby a quello di connessione, esso può essere collocato in una delle seguenti modalità:

    •  Active mode: l'unità partecipa attivamente alla piconet, sia in ricezione che in trasmissione, ed è sincronizzata al clock del master. Il master trasmette regolarmente per mantenere la sincronizzazione del sistema. Gli slave hanno un indirizzo di 3 bit AM_ADDR (Active Member Address).
    •  Hold mode: il master può mettere i dispositivi slave nello stato di Hold per un tempo determinato. Durante questo periodo nessun pacchetto può essere trasmesso dal master anche se il dispositivo mantiene il suo AM_ADDR e la sincronizzazione con il master. Questa modalità operativa è utilizzata generalmente nel momento in cui non si devono inviare pacchetti ad un dispositivo per un periodo relativamente lungo (questo ci fa capire che tale modalità operativa è supportata solamente nel caso in cui tra due dispositivi bluetooth ci sia un collegamento di tipo ACL). Durante questo periodo, il dispositivo si può spegnere per risparmiare energia. L’Hold mode può essere utilizzata anche nel caso in cui un'unità vuole scoprire o essere scoperta da altri dispositivi bluetooth o vuole partecipare ad altre piconet.
    •  Sniff mode: lo slave che passa in questo stato si trova in una modalità di risparmio energetico. Per entrare nello sniff mode, master e slave devono negoziare due parametri: uno “sniff interval” ed uno “sniff offset”. Con il primo si fissano gli slot di sniff, mentre con il secondo si determina l'istante del primo slot di sniff. Quando il collegamento entra in sniff mode, il master può inviare pacchetti solamente all'interno degli sniff slot. Quindi lo slave ascolta il canale ad intervalli ridotti. Il master può costringere lo slave ad entrare in sniff mode, ma entrambi possono chiedere il passaggio. L'intervallo di sniff mode è programmabile.
    • Park mode: il dispositivo è ancora sincronizzato alla piconet ma perde il suo indirizzo di dispositivo attivo (AM_ADDR) e riceve un nuovo indirizzo di 8 bit (PM_ADDR, Park Mode Address). Questa modalità è stata ideata per avere la possibilità di costituire piconet con più di sette slave. Infatti si possono avere fino ad massimo di 255 (28-1) dispositivi in modalità Park. Utilizzando tale indirizzo il master è in grado d'identificare un particolare dispositivo in tale modalità ed effettuare il passaggio all’active mode. Le unità in questo stato ascoltano regolarmente il traffico sulla rete per risincronizzarsi e ricevere messaggi di broadcast. Questi ultimi, infatti, sono gli unici messaggi che possono essere inviati ad uno slave in park mode. La richiesta di passaggio in park mode può avvenire indifferentemente da parte del master o dello slave. Lo slave per richiedere l'attivazione al master riceve un indirizzo di Active Request (AR_ADDR) non unico.

## Architettura delle comunicazioni Bluetooth

<p align="center">
  
</p>

### Bluetooth Protocol Stack
Come avviene per l'architettura OSI, Bluetooth specifica un approccio a livelli nella sua struttura protocollare. Differenti protocolli sono utilizzati per differenti applicazioni. Indipendentemente del tipo di applicazione, però, lo stack protocollare Bluetooth porta sempre all'utilizzo dei livelli data-link e fisico. Non tutte le applicazioni usano tutti i protocolli dello stack Bluetooth, infatti, esso è rappresentato su più livelli verticali, al di sopra dei quali c'è un'applicazione specifica.
Scendendo un po' più in dettaglio è possibile identificare le funzioni principali svolte dai protocolli più importanti dello stack Bluetooth:
Bluetooth Radio: definisce i requisiti della parte in radio frequenza. Qui è dove i segnali radio vengono processati.

    •  Baseband: abilita il collegamento fisico tra dispositivi all'interno di una piconet. Tale livello si basa sulle procedure di inquiry e di paging per la sincronizzazione e la connessione di dispositivi bluetooth. Permette di stabilire i due diversi tipi di connessione (ACL e SCO).
    •  LMP: è responsabile dell'organizzazione del collegamento, del controllo tra dispositivi bluetooth e del controllo e negoziazione della dimensione dei pacchetti. È anche utilizzato per quanto riguarda la sicurezza: autenticazione e crittografia, generazione, scambio e controllo chiavi. Effettua anche il controllo sulle diverse modalità di gestione della potenza (park, sniff, hold) e sullo stato della connessione di un dispositivo all'interno della piconet. I messaggi LMP sono filtrati ed interpretati dal link manager in sede di ricezione, di conseguenza non saranno mai trasmessi ai livelli superiori. Questi messaggi hanno priorità maggiore rispetto ai pacchetti che trasportano dati utenti.
    •  L2CAP: esegue il multiplexing dei protocolli di livello superiore, la segmentazione e il riassemblaggio dei pacchetti e il trasporto di informazione relativa alla QoS (Quality of Service) ovvero è possibile richiedere una certa QoS da riservare ad un determinato link. L2CAP permette ai protocolli dei livelli superiori ed alle applicazioni di trasmettere e ricevere pacchetti di dati di dimensione superiore a 64 KB. Esso definisce solamente un collegamento di tipo connectionless. I canali audio di solito vengono fatti girare su collegamenti SCO; per ovviare a questo problema dati audio possono essere inviati all'interno di pacchetti di protocolli che girano su L2CAP.
    •  RFCOMM: emula una porta seriale (RS-232) sul protocollo L2CAP. Questo livello è necessario in quanto esistono applicazioni (come per esempio OBEX) che utilizzano un meccanismo di trasmissione seriale.
    •  TCS BIN: opera a livello bit e definisce i segnali di controllo per le chiamate voce e dati tra dispositivi Bluetooth e le procedure per gestire gruppi di dispositivi TCS.
    •  SDP: è un elemento importante all'interno della tecnologia Bluetooth, in quanto permette alle applicazioni di avere informazioni sui dispositivi, sui servizi offerti e sulle caratteristiche dei servizi disponibili. Dopo aver individuato il dispositivo che implementa un determinato servizio è possibile stabilire una connessione.
    •  AUDIO: la funzione di questo strato è quella di codificare il segnale audio. Due tecniche possono essere adottate: log PCM e CVSD; entrambe forniscono un flusso di bit a 64 kbit/s. La codifica log PCM (Pulse Code Modulation) consiste in una quantizzazione non uniforme a 8 bit. Nella codifica CVSD (Continuous Variable Slope Delta Modulation) il bit d'uscita indica se il valore predetto è maggiore o minore del valore della forma d'onda in ingresso, costituita da un segnale PCM con quantizzazione uniforme. Il passo è determinato dalla pendenza della forma d'onda.

Fonte : https://it.wikipedia.org/wiki/Bluetooth

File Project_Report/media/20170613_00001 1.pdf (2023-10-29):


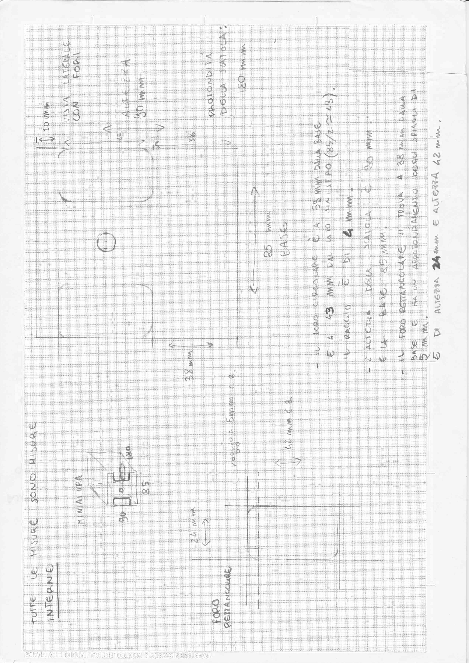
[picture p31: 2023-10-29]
Project_Report/media/vista_laterale_min.jpg

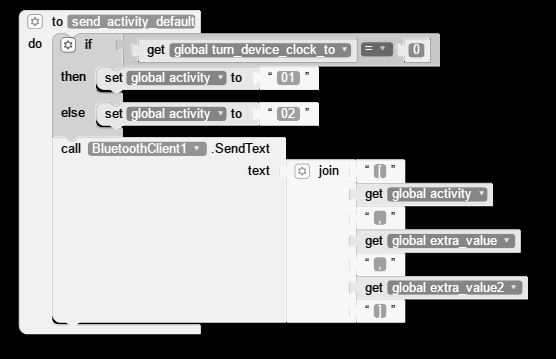
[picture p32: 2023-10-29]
Project_Report/Appinventor_blocks/cap/Capture21.JPG

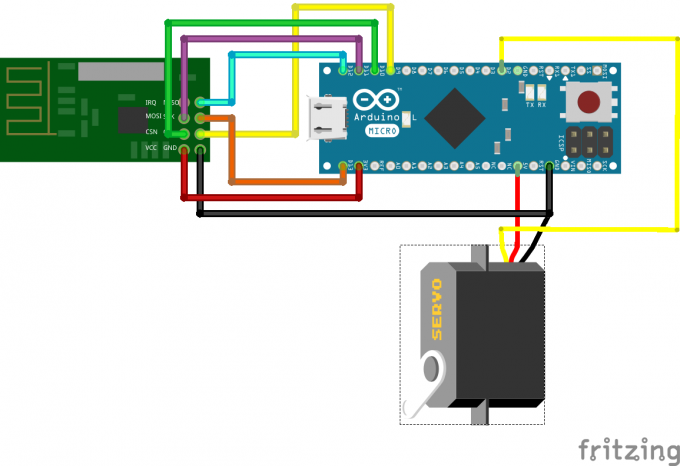
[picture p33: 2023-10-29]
Information_Gathering/Multimedia/Servo_pinout/NRf24L01-reciever_bb_615e38.png

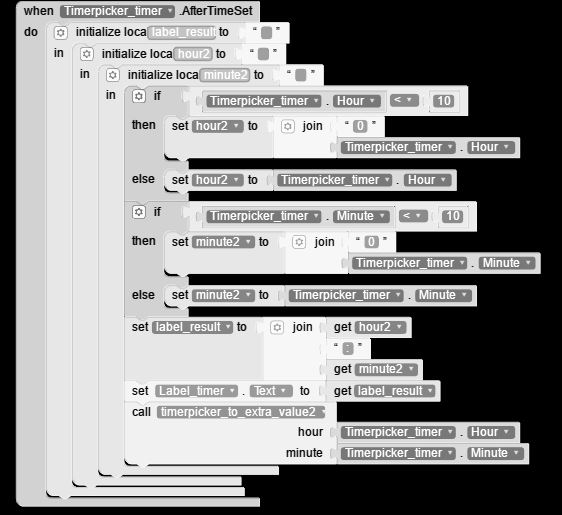
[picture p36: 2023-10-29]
Project_Report/Appinventor_blocks/cap/Capture15.JPG

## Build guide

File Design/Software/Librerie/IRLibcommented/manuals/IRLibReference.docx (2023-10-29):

# Users Manual for IRLib.

# A Library for Receiving, Decoding and Sending Infrared Signals Using Arduino.

(Revised June 2014)

This library is designed for using Arduino controllers for receiving, decoding and sending infrared signals such as those used by infrared remotes on consumer electronics. The work is based on earlier library called IRremote which was created by Ken Shirriff. This library is a major rewrite of that system. The original library defined only decoding and sending classes. The decoder class included the code for receiving the raw signals and measuring time intervals in them.

In this rewrite we separated the receiving from the decoding initially to make the code easier to understand. Our thinking was that receiving portion of the code was extremely hardware oriented and required knowledge of hardware interrupts, hardware times and other technical issues. Whereas the decoding portion of the process dealt with protocols used by IR devices. It was more likely that users want to implement new protocols and they would not want to have to deal with the technical details.

Overall I wanted to take a “black box” approach that would isolate as many of the internal details as possible so that the end-user did not have to deal with them. The separation of receiving and decoding also allowed for the possibility that the receiver could be reset to receive another sequence of signals while the decoding process was going on (although decoding is not generally very time intensive). This design decision to split receiving from decoding also facilitated the later decision in version 1.3 of the library to implement other methods of receiving signals.

This manual is divided into three major sections. First is a complete reference of all the classes, structures and methods included in the library. The reference section is designed for those who want to make maximum use of the facilities of the library. However you may not need to understand everything in this section in order to use it. We suggest that novices proceed to part two which is the tutorials section. There you will find some examples of the basic use of the library. Finally you can move on to the third section of this documentation which explains how to add additional protocols to the decoding and sending sections.

Note also that the code is well documented and skilled programmers who are familiar with infrared protocols and Arduino hardware or anyone interested should simply browse through the code itself for useful information.

# 1. IRLib Reference

This section is intended to be a complete reference to the classes, methods, and structures used in the library. It is divided into three sections: the receiver classes, the decoder classes, and the sending classes.

## 1.1 Receiver Classes

IR data is received on an input pin of the Arduino as a square wave of pulses of varying lengths. The length of the on and off pulses encodes the data. It is the job of the receiver class to record the timing of the pulses in the spaces between in an array and pass that information to the decoder class. This section contains an overview discussion of the receiving process, with an explanation of the base receiver class and three derived classes each with its own unique characteristics. In addition to the receiver classes which record basic pulse widths, there is a new additional receiver class for measuring the modulation frequency of an IR signal.

### 1.1.1 Receiver Overview

Infrared signals are received by an IR receiver device such as the first TSOP4438 or TSO58438 or similar. See the Hardware Considerations section for details. Although IR signals are sent as a series of modulated pulses, these receivers filter out the modulations and send you a signal in the form of a clean square wave. The output of the receiver is connected to one of the digital input pins of your Arduino. It is the job the receiver class to monitor this signal and to determine the length of the pulses known as “marks” in the length of the intervening idle periods known as “spaces”. The hardware receiver devices typically are normally high and the low when a signal is received. However the code compensates for this sort is useful to think of a “mark” as being “on” and a “space” as being “off”.

The duration of marks and spaces is measured in microseconds (1/1,000,000 of a second). Note however that the software makes use of the built-in Arduino function “micros(void)” which returns results in four microssecond granularity. Which means that values are always a multiple of four. This is for typical 16 MHz clocks on most Arduino models. On 8 MHz models results are in eight microsecond granularity. So whatever results we achieve are going to be no more accurate than that.

The receiver software is organized as a base class which of itself is not functional but contains methods which are common to all of the classes. The classes are:

- IRrecvBase Abstract base class
- IRrecv Original receiver class which uses 50 µs interrupt sampling
- IRrecvPCI Uses pin change interrupts to measure pulse duration
- IRrecvLoop Uses a tight code loop to poll the input pin

The data is stored in an array of unsigned int values. The first element of the array is the number of microseconds from the time the receiver is enabled until the time the first mark is received. This gap is typically discarded by the decoding routines. From there on, odd-numbered elements of the array contain the duration of the marks and even-numbered elements contain the duration of the spaces.

Most of the receiver classes are interrupt driven which means once they are initialized you can go off and do whatever you want until a complete sequence has been received. You determine when the sequence is complete by polling the method GetResults and when it returns true you can then obtain the results. Once a complete sequence has been received, the receiver class ignores any subsequent signals until it is reinitialized by you. However the IRrecvLoop is not interrupt driven and so when you call GetResults it sits in a tight loop and does not release control back to you until the complete signal has been received.

Although the library implements three different extensions to the base receiver class, you should have one and only one instance of a receiver class in your program because all the classes make use of global data and methods that are common to all of the classes. The data must be declared globally in the library because it is accessed by interrupt service routines. The structure of an interrupt service routines does not allow for the passing of any parameters. Therefore any data that the ISR accesses must be global.

You should read the next section about the base class because most of the methods work identically regardless of which derived class you actually instantiate. You should then read the section on the class which you are going to use so that you will understand the class specific issues.

Here is an extremely simple sample sketch showing the use of the IRrecv class. Either of the other two classes could be substituted in this example. You may wish to refer to this sample code while reading the description of the methods.

#include <IRLib.h>

IRdecode My_Decoder;

IRrecv My_Receiver(11); //Create the receiver. Use pin 11

void setup()

{

Serial.begin(9600);

My_Receiver.enableIRIn();//start receiving

}

void loop() {

if (My_Receiver.GetResults(&My_Decoder)) {//wait till it returns true

My_Decoder.decode();

My_Decoder.DumpResults();

My_Receiver.resume(); //restart the receiver

}

}

### 1.1.2. The IRrecvBase class

This base class is an abstract class which in and of itself is not functional but contains common code for the other receiver classes. The prototype of the class is in “IRLib.h” and the code is implemented in “IRLib.cpp”. The prototype is…

class IRrecvBase

{

public:

IRrecvBase(void) {};

IRrecvBase(unsigned char recvpin);

void No_Output(void);

void blink13(bool blinkflag);

bool GetResults(IRdecodeBase *decoder, const unsigned int Time_per_Ticks=1);

void enableIRIn(void);

virtual void resume(void);

unsigned char getPinNum(void);

unsigned char Mark_Excess;

protected:

void Init(void);

};

The constructor is

IRrecvBase(unsigned char recvpin);

The value passed is usually the pin number to which the receiver is connected. Although the single parameter is called “recvpin”, in the case of the IRrecvPCI class, the value passed constructor is not the receiver pin number but is the interrupt number. See IRrcevPCI for details.

Creating an instance of the receiver class does not enable the receiving of data. You must enable the receiver by calling

void enableIRIn(void)

This method sets the input pin to input mode and resets the index into the array of data values to zero. On the interrupt driven classes this enables interrupts and the receiver starts recording intervals. However when using the IRrecvLoop class, recording of signals does not begin until you call GetResults.

If you are only receiving signals in your program, you need only call this method one time. However if your program sends and receives IR signals, it cannot do both simultaneously. The sending of an IR signal disables the receiver. After you have sent a code you must reenable the receiver class using enableIRIn().

Once the receiver is running you then need to poll the class to see if a complete sequence has been received. You do this by repeatedly calling…

bool GetResults(IRdecodeBase *decoder,

const unsigned int Time_per_Ticks=1);

This method will return “true” when a complete sequence has been received and will return “false” otherwise. The first parameter is a pointer to a decoder class. This facilitates passing data from the receiver to the decoder.

The second parameter is optional. Is a multiplier which converts the recorded data into microseconds. The IRrecv class produces results in 50 µs ticks. It passes the number 50 as the second parameter so that GetResults will multiply the values in the array by 50 to convert them into actual microseconds. The other two receiver classes use the default multiplier 1 because they record actual microseconds do not need converting.

This method passes data into your decoder class. You can configure your decoder to use the same global array that is used by the receiver classes or your decoder can define its own extra buffer in which case the interval data is copied from the receiver’s array to the decoder’s array. The method also passes the index of the last array element used.

When a complete sequence has been received by the class it does not continue recording signals. It also does not resume recording once you have called GetResults because your decoder may be using the same array as the receiver and you do not want the receiver overwriting the array before you get it decoded.

To resume receiving data you must call the method…

virtual void resume(void);

That method is declared “virtual” because it is called by the IRrecvBase::enableIRIn method in the derived classes. This allows the derived classes to do things they need to do for themselves when resume is called.

In summary, you would typically call enableIRIn once at the beginning of your program and if your program uses the send classes you would need to use it after each sending of an IR signal. You would use “resume()” to resume reception after decoding or immediately after GetResults if your decoder uses its own array. You need not call “resume()” if you have called “enableIRIn()” because it will call it for you.

The remaining methods are not essential to the operation of the receiver but are useful.

For debugging purposes you may want to know if your Arduino is receiving a signal. If you initially call

void blink13(true)

Pin 13 will be blinked on every time a mark is received and blinked off when a space is received. The default is off and blinking will not occur.

Some users create custom boards for input and output of IR signals and those boards are connected to their Arduino even in the case where there really a sketch that only does input. It is theoretically possible that when running an “input only” sketch that the output pin could initialize high and your output LED would be on all the time. LED driver circuits are sometimes designed to overdrive the LED because it is used only intermittently. If it were to be accidentally left on continuously, it could burn out your circuit. If you want to ensure that this does not happen you can call.

void No_Output(void);

This will ensure that your output pin is set low. Note that in this library the output pin is determined at the time that the library is compiled and is based on the choice of internal hardware timer in the “IRLibTimer.h” file. That is why the receiver team can know what output pin to drive low.

As noted earlier, the constructor for IRrecvPCI is passed an interrupt number rather than a pin number. The pin number is computed based upon the type of hardware you are using and interrupt chosen. You can return the value of this pin number using…

unsigned char getPinNum(void);

This method also works for the other receiver classes although you probably already know which pin you are using because you sent it that information in the constructor.

Depending on the type of IR receiver hardware you are using, the length of a mark pulse is over reported and the length of a space is underreported. Based on tests performed by Ken Shirriff who wrote the original IRremote library upon which this library is based, the length of a received mark is about 100µs too long and a space is 100µs too short. That is the default value used by the receiver classes. However my own experience is that 50µs is a better value. In order to maintain backwards compatibility with earlier versions of the library we have maintained the 100µs default however you can now change that value based on your own experiences by changing the value of

unsigned char Mark_Excess;

You can examine or change this variable as desired. It is applied by adding that value to all odd-numbered elements of the interval array and is subtracted from even-numbered elements when the data is passed to your decoder by GetResults.

There is one protected method which is used for internal use.

void Init(void);

Is called by the constructors and it initializes the blink flag and the default mark excess values. There is also a global function used by the receiver class.

void do_Blink(void);

This performs the actual blinking of pin 13. It cannot be a method of this class because it is called from within an interrupt service routine. This function is used internally only.

### 1.1.3. IRrecv Class

This receiver class is based on the original receiver created by Ken Shirriff in his library IRremote upon which this library is based. It uses a hardware timer to trigger an interrupt every 50µs. Inside the interrupt routine it counts the number of these 50µs ticks while the pin is a mark and when the state changes it counts how many ticks in the space. When it receives an extraordinarily long space it presumes that the sequence has ended. It sets an internal flag noting that the sequence has been received. It stops recording time intervals and when the user calls GetResults the next time it will return true.

The internal hardware timer used is controlled by settings in the “IRLibTimer.h” file. Each type of Arduino platform such as Arduino Uno, Leonardo, Mega etc. has a choice of different timers. For example the Uno uses TIMER2 while the Leonardo uses TIMER1. You may need to change the default timer in the event of a conflict with some other library. For example the Servo library makes use of TIMER1 so if you’re using a Leonardo with a servo you would need to change the value in “IRLibTimer.h” to use a different timer.

The prototype of the class is in “IRLib.h” and the code is implemented in “IRLib.cpp”. The prototype is…

class IRrecv: public IRrecvBase

{

public:

IRrecv(unsigned char recvpin):IRrecvBase(recvpin){};

bool GetResults(IRdecodeBase *decoder);

void enableIRIn(void);

void resume(void);

};

As previously noted in the discussion of the base class, the constructor is passed the pin number of the input pin to which you have connected your receiver. There are no restrictions and any digital input pin can be used.

Note that when calling GetResults you only use the first parameter which is a pointer to your decoder class. Although the prototype only lists the constructor and three other methods, all of the methods available to the base class are available in this class.

You will need to enable input by calling enableIRIn() and will need to poll the GetResults method in your loop until it turns true. Although in our example code we called GetResults in a very small loop, because this class is interrupt driven you can do just about anything else inside your main loop function and only call GetResults when you are ready.

A reminder that when a complete stream has been received, no additional measurements are taken until you call the “resume()” method. If your decoder does not use its own buffer and relies upon the global buffer for the library, be sure not to call resume until your decoding is complete when you no longer have need of the buffer.

Because the interrupt service routine for this class must be declared globally, it is always created even if you do not use the IRrecv class. If you are using a timer interrupt for some other purpose, it can create a conflict because there are duplicate ISR functions declared. There is a conditional compile flag available in IRLib.h that effectively removes this entire class and the ISR from the library. If you need to remove the class you should comment out the line that reads

#define USE_IRRECV

There is no similar define to disable IRrecvPCI or IRfrequency classes because they use a different type of ISR with a unique name that will not conflict with other libraries or code. Also the IRrecvLoop is not interrupt driven so it will never conflict and does not need to be disabled.

Because this receiver only samples the input every 50µs there is a chance that it could sample at inopportune times and be as much as 98µs off when measuring intervals. If you are decoding a known protocol, this margin of error is usually acceptable. The decoder functions typically use +/-25% tolerance and that produces acceptable results. However if you are trying to analyze an unknown protocol you would be better suited to use either the IRrecvPCI or IRrecvLoop receiver class instead.

### 1.1.4. IRrecvPCI Class

This receiver class makes use of the hardware interrupt available on some pins of Arduino microcontrollers. It was created because it gives more accurate timings than the original IRrecv class which only samples the input every 50µs. The code is loosely based upon and inspired by the work by the developers of the AnalysIR program. AnalysIR is a Windows-based application which allows you to graphically analyze IR input signals through and Arduino, Raspberry Pi or other microcontrollers systems. Many thanks to the developers of that software for their assistance and input into the development of this class. You can find more about their software at http://analysir.com

The class sets up the pin change hardware interrupt which calls the interrupt service routine every time the input pin switches from low to high or high to low. At each change, the code calls the built in function “micros()” and that value is subtracted from the timestamp of the previous change. Because the micros() function is only accurate to 4µs on 16 MHz systems or 8µs on 8 MHz systems, that is the limitation of accuracy of this method.

While it is much more accurate than the original IRrecv class which only had 50µs or worse accuracy, it may not be suitable for everyday use. The class has difficulty determining when a sequence has ended. Normally we assume a sequence has ended when a space interval is longer than a certain amount. But we cannot know how long the final trailing space is until the first mark of the next sequence begins. The code attempts to compensate for this by checking for an extremely long space each time that the user calls GetResults. However unless you call that routine extremely frequently, it is more likely that the next sequence will begin. While that does not adversely affect the reception and subsequent decoding of an initial sequence, if the next sequence comes quickly then the receiver may miss it or may start reception in the middle of a sequence thus giving only partial therefore jumbled results. To avoid this problem we suggest that you not resume the receiver immediately but instead put a “delay(500);” or longer statement after you have finished decoding.

Although this class does not use internal hardware timers, it is still recommended that you call “enableIRIn()” after using any sender routines.

As with the IRrecv class, the interrupt service routine is disabled once a completed sequence has been detected and is not re-enabled until you call either “enableIRIn()” or “resume()”.

The prototype of the class is in “IRLib.h” and the code is implemented in “IRLib.cpp”. The prototype is…

class IRrecvPCI: public IRrecvBase

{

public:

IRrecvPCI(unsigned char inum);

bool GetResults(IRdecodeBase *decoder);

void resume(void);

private:

unsigned char intrnum;

};

Note that the parameter passed to the constructor is an interrupt number and not a pin number. The value you specify is passed to the built in “attachInterrupt()” function. The table below shows which interrupts are available on various types of Arduino hardware and the resulting pin numbers used by those interrupts. NOTE: these interrupt numbers which are passed to “attachInterrupt()” are not necessarily identical to the interrupt numbers in the datasheet of the processor chip you are using. These interrupt numbers are a system unique to the “attachInterrupt()” Arduino function. For more information on attachInterrupt see http://arduino.cc/en/Reference/AttachInterrupt

Board | int.0 | int.1 | int.2 | int.3 | int.4 | int.5 | Int.6
Uno, Ethernet | 2 | 3
Mega2560 | 2 | 3 | 21 | 20 | 19 | 18
Pinoccio | 4 | 5 | SCL(15) | SDA(16) | RX1(13) | TX1(14) | 7
Leonardo | 3 | 2 | 0 | 1 | 7
Due | (see below)

The Arduino Due board has powerful interrupt capabilities that allow you to attach an interrupt function on any available pins. This library has not been tested using this platform but theoretically should work.

Note this table is also used by the IRfrequency class and is implemented by the following global function which is implemented in IRLib.cpp and whose prototype is in IRLib.h..

unsigned char Pin_from_Intr(unsigned char inum);

The constructor takes the interrupt number which you pass and computes the pin number. If you wish to verify which pin number it has chosen based on your interrupt you can use the getPinNum() function to make sure that the hardware detection is working properly.

Although the prototype of this class only lists 2 methods, all of the methods of the base class are available.

### 1.1.5. IRrecvLoop Class

This version of the receiver class uses a tight internal loop to poll the input pin. It makes no use of hardware interrupts or internal timers to compute the intervals. It does use the “micros()” function to compute time intervals so it has the limitations of that function. Specifically the function is only accurate to 4µs on 16 MHz systems or 8µs on 8 MHz systems. Although we have attempted code the loop as tightly as possible there still is some amount of overhead in the loop itself which could affect the accuracy. However it is still much more accurate than the 50µs off the original IRrecv. This makes it a good choice for analyzing unknown protocols.

Because no interrupts are involved, the class does not begin recording intervals when you initially call “enableIRIn()” as is the case with other classes. This class only samples input when you call GetResults. That method then takes over control of your program and does not relinquish it until it has received a complete sequence. The function always returns true. Because it takes over control of your program and does not allow you to do other things while it is looking for a sequence, this version of the class may not be practical for everyday use.

It is still recommended that you follow all of the procedures for when to call enableIRIn() and or resume() methods as you would with other versions of the class.

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

class IRrecvLoop: public IRrecvBase

{

public:

IRrecvLoop(unsigned char recvpin):IRrecvBase(recvpin){};

bool GetResults(IRdecodeBase *decoder);

};

Although the prototype only lists the constructor and GetResults, all of the methods of the base class are available. Like IRrecv, the value passed to the constructor is the number of the receiver pin. Any available digital input pin can be used.

### 1.1.6. Global Receiver Structures

In addition to the base class and the three derived classes that are used for receiving IR signals, there is a globally defined structure that is used by the classes. Good object-oriented design would have us put all of the data associated with a class inside the class itself. However much of the data we use needs to be accessible from an interrupt service routine. A limitation of an ISR is that we cannot pass it any parameters and it cannot be part of a class. So all of the data used by the ISR must be in some globally available location. Unless you’re going to implement your own receiver class or create custom decoder classes need access to this data, you need not deal with the structure. It is solely for internal use. The file “IRLibRData.h” contains the following definitions

enum rcvstate_t {STATE_UNKNOWN, STATE_IDLE, STATE_MARK, STATE_SPACE, STATE_STOP, STATE_RUNNING};

typedef struct {

unsigned char recvpin; // pin for IR data from detector

rcvstate_t rcvstate; // state machine

bool blinkflag; // TRUE to enable blinking of pin 13 on IR processing

unsigned long timer; // state timer, counts 50uS ticks.(and other uses)

unsigned int rawbuf[RAWBUF]; // raw data

unsigned char rawlen; // counter of entries in rawbuf

}

irparams_t;

extern volatile irparams_t irparams;

The enum values are the “states” in which the interrupt service routine keeps track of the receiving process. They are used by IRrecv and IRrecvPCI.

The structure called irparams gives Jack of the input pin, the state of the receiver, the flag used by the pin 13 blinker, a variable to count the number of ticks in the interval, the array which contains the length of sequence of marks and spaces and the index into that array which will contain the length of the sequence when it is complete.

Note that the entire structure is declared “volatile” which informs the compiler to always immediately store results in their location and immediately retrieve them when needed because they may get changed by the ISR in the middle of the calculation.

The decoder class contains a pointer to an array. The default is that that pointer is initialized to “irparams.rawbuf” which is the same array used by the receiver class. You have the option to define your own array for use by the decoder by changing that pointer to a different array. The receiver method GetResults will copy the values either to itself if you did not specify a different array or it will copy the results to your array if you have changed that pointer. See the section on IRdecodeBase::UseExtnBuf(void *P); for details. The GetResults method also copies rawlen to a similarly named variable in the decoder class.

### 1.1.7 IRfrequency Class

Normally you would use a TSOPxxxx IR receiver device to detect IR signals. These devices demodulate the signal into square waves measured in hundreds or thousands of microseconds. However the actual IR signals are modulated at frequencies from 36 kHz as high as 57 kHz depending on the protocol. If you have an unknown protocol, you can typically receive such a signal using a device that has been tuned to 38 kHz however if you then want to accurately retransmit the signal you need to know the actual frequency. This requires a different type of receiver such as a TSMP58000 that passes the modulated signal through directly. See the section Hardware Considerations for more info on connecting these devices.

Because the signals are so short (17.5 µs to 27.7 µs) it is difficult to accurately measure them. The only way is to use a hardware interrupt pin and an extremely fast interrupt service routine. However these measurements are limited to the accuracy of the micros() function which is only accurate to 4 µs on 16 MHz systems and 8 µs µs on 8 MHz systems. The accuracy of the measurement can be slightly improved by taking several hundred measurements and averaging them.

The IRfrequency class implements an interrupt driven system for measuring frequency. See the examples folder for sample code using this class. The IRrecvDumpFreq example requires both a TSOP and TSMP device connected to 2 different pins. It detects both the frequency using IRfrequency and the pattern of pulses using IRrecvPCI or IRecvLoop receivers. You could also use the original IRrecv receiver class but it degrades the accuracy of the frequency calculation because the interrupt every 50 µs interferes. The other sample code is IRfreq and it uses only the TSMP device to measure frequency and it does nothing else. Measuring frequency by itself is the most accurate method but there may be applications where you need to measure frequency and protocol simultaneously.

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

class IRfrequency

{

public:

//Note this is interrupt number, not pin number

IRfrequency(unsigned char inum);

void enableFreqDetect(void);

bool HaveData(void); //detective data received

void disableFreqDetect(void);

void ComputeFreq(void); //computes but does not print results

void DumpResults(void); //computes and prints results

unsigned char getPinNum(void);//get value computed from interrupt number

double Results; //results in kHz

unsigned char Samples; //number of samples used in computation

private:

volatile unsigned char Time_Stamp[256];

unsigned char intrnum, index, pin;

unsigned long Sum;

};

The parameter to the constructor is the interrupt number you will use for detecting the frequency. Note this is the same system of interrupt numbers used by the IRrecvPCI class. It is not the actual pin number for connecting the device. See the table in the section on IRrecvPCI. You can also use the getPinNum() method to retrieve the pin number once the class has been created. Note that although some of the methods of this class have the same name as the IRrecvBase class, it is not a derived class from that base. As with other receiver classes, you should instantiate only one copy of this class.

The class does not begin collecting frequency data until you call enableFreqDetect() method. This attaches the interrupt routine and begins waiting for a signal. The built in interrupt service routine calls micros() each time a signal is detected. It stores the least significant byte of that value in a 256 byte array. It continually detects data in the array and when it fills, the index wraps around. This overflow is very likely to occur because an IR stream will usually contain thousands of pulses. Therefore the measurement is only based upon the most recent 256 data points.

If you are simultaneously receiving a signal using a TSOPxxxx device and one of the three available receiver classes as in the IRrecvDumpFreq example, you can continue to operate the frequency detector until a complete sequence has been detected. However if you are measuring frequency alone as with the IRfreq example, you need to know when to quit. You can call the HaveData() method repeatedly in your main loop. It will return true if at least one buffer full of data has been collected.

When you are finished collecting data, you should call the disableFreqDetect() method. This will detach the interrupt and no further data is collected until you call enableFreqDetect() again. You then have a choice of either calling ComputeFreq which computes the frequency based on the timestamp data or DumpResults which will call ComputeFreq for you and display the results using Serial.print().

The computation measures the difference between successive timestamps. While the majority of the timestamps will be the time between pulses of the modulated signal, some of them will be the gaps caused by the spaces in the protocol. These gaps will be on the order of hundreds of microseconds rather than tens of microseconds. The computation discards these intervals and only considers those which are likely to be from the modulated signal itself. Because we’re only storing the least significant byte of data, some of the values will be inaccurate. The code attempts to eliminate anything that is unusually large or unusually small. It then averages the usable samples and computes a frequency measured in kHz. ComputeFreq stores the results in a float double value Results. It also tells you the number of actual samples used in the computation in the unsigned char Samples. If the Samples value is extremely small, you might wish to discard that data and remeasure.

The text strings of the DumpResults method are stored in program memory rather than RAM memory. However if you are not using the DumpResults method and you are running out of program memory may wish to disable this function. In IRLib.h there is a define

#define USE_DUMP

You can comment out that line was to save program memory. Note that this parameter also affects the DumpResults method of the decoder classes as well.

## 1.2 Decoder Classes

IR signals are encoded as a stream of on and off pulses of varying lengths. The receiver classes only record the length of pulses which we call “marks” and the intervals between them which we call “spaces”. However it is the decoder class which identifies the protocol used and extracts the data. It provides the user with the type of protocol it found if any, the value received, and the number of bits in that value. We implement the decoder as an abstract base class and nine additional derived classes. Seven of the classes are for the seven protocols which are built into the library. An eighth class consolidates the seven other classes into one omnibus class that decodes all seven protocols. A ninth class turned the data into a 32-bit hash code which can be used for deriving a value for data from an unknown protocol. Note however that the hash code is only good for detecting signals and cannot be used to re-create the signals for sending again.

Note: additional protocols are demonstrated in various example sketches provided with this library. These examples illustrate how to extend the library using object-oriented programming techniques without having to recompile it. It will be our policy for the foreseeable future not to directly add additional protocols to the library but to implement future protocols as example sketches. We will not accept any pull requests which add additional protocols to the main library. We will also not accept additional examples which do not implement both sending and decoding classes.

### 1.2.1. Decoding Overview

The data from the receiver class is in the form of an array of time intervals of the marks and spaces that constitute the data stream. That stream typically begins with some sort of header followed by the encoded bits of data which could be from 8 up to 32 or more bits followed by some trailer. Occasionally there are other sequences in the middle of the stream that are not actually part of the data that serve to separate the data into different sections. In order to make good use of the information we need a decoder which will take this data and convert it into a single binary value which identifies the particular function the remote is using.

The data sent by a remote often contains information such as a device number,-sub-device, function number, sub-function and occasionally information that designates that this is a repeated signal. The philosophy of this library is to not care about what the data represents. We take the philosophy that “You push the button and this is the stream of data that you get.” Our job is to get you that binary number usually expressed in hexadecimal and it’s up to you to decide what to do with it.

If you are using a supported protocol, that hexadecimal number can then be fed into a send class which will output the IR signal identical to the one that you received. There is one exception in that one of the decoders used for unknown protocols creates a 32-bit hash code from the input sequence. The hash code is extremely likely to be a unique representation of the original stream but there is no way to reverse that and re-create the stream from the hash code.

Different manufacturers use different protocols for encoding this data. That is what allows you to have a universal remote that can operate devices by different manufacturers and not have the signals get mixed up. That creates a problem for us because we need different programs to decode each different protocol. This library supports seven of the most common protocols. The example programs included with the library show how to decode and encode a number of additional protocols. We have seen references online to dozens of others which we do not support yet.

The library has a base decoder class and 10 additional extended classes. Seven of those classes are for the seven protocols we support directly. An eighth class creates a hash code out of that raw data which can turn the data into a unique binary number. Note that the hash code cannot then be used to re-create the original sequence for sending the data out again. The ninth class is an abstract class which defines common methods used by both RC5 and RC6 protocols. Finally, the tenth class combines the seven supported protocols into a single decoder.

### 1.2.2. IRdecodeBase Class

The library defines a base decoding class that is an abstract class which does not in and of itself do anything. All other decoder classes are extensions of this class. The prototype is in “IRLib.h’ and the code itself is in “IRLib.cpp”. The prototype for the class is…

typedef char IRTYPES; //formerly was an enum

class IRdecodeBase

{

public:

IRdecodeBase(void);

IRTYPES decode_type; // NEC, SONY, RC5, UNKNOWN etc.

unsigned long value; // Decoded value

unsigned char bits; // Number of bits in decoded value

volatile unsigned int *rawbuf; // Raw intervals in microseconds

unsigned char rawlen; // Number of records in rawbuf.

bool IgnoreHeader; // Relaxed header detection allows AGC to settle

virtual void Reset(void); // Initializes the decoder

virtual bool decode(void); // This base routine always returns

// false override with your routine

bool decodeGeneric(unsigned char Raw_Count, unsigned int Head_Mark,

unsigned int Head_Space, unsigned int Mark_One,

unsigned int Mark_Zero, unsigned int Space_One,

unsigned int Space_Zero);

virtual void DumpResults (void);

void UseExtnBuf(void *P); //Normally uses same rawbuf as IRrecv.

//Use this to define your own buffer.

void copyBuf (IRdecodeBase *source); //copies rawbuf and rawlen from

//one decoder to another

protected:

unsigned char index; // Index into rawbuf used various places

};

The constructors for the base class and for any of its derived classes take no input. Unlike the receiver classes there is no problem creating an instance of multiple decoder objects because each has its own internal data associated with it.

Data is passed from the receiver class to the decoder class when you call GetResults and pass it a pointer to your decoder. Get Results starts by calling your decoders “Reset()” method to clear out any previous data. It resets the decode_type to UNKNOWN and zeros out other values. It then copies the interval timing data into the array rawbuf and sets rawlen to the index of the last array element used. It is unlikely you would ever have need to call the Reset() method yourself but it is available if you need it.

User should then call the “decode()” method. It will analyze the raw data and if it is a recognized protocol it will set the “decode_type” value as one of the following values found in IRLib.h.

#define UNKNOWN 0

#define NEC 1

#define SONY 2

#define RC5 3

#define RC6 4

#define PANASONIC_OLD 5

#define JVC 6

#define NECX 7

#define HASH_CODE 8

#define LAST_PROTOCOL HASH_CODE

That “decode()” method also sets “value” to the binary value it decoded and sets “bits” to the number of bits of data. Most protocols have a fixed number of bits but some protocols such as Sony have different versions of the same protocol using different numbers of bits.

The method “DumpResults()” can be called after “decode()” to dump information about the received data to the serial monitor. You will have had to initialize serial output using “Serial.begin (int)” prior to calling it. Here is an example of typical data output by this method

Decoded Sony(2): Value:74BCA (20 bits)

Raw samples(42): Gap:11950

Head: m2300 s700

0:m550 s600 1:m1200 s600 2:m1150 s650 3:m1150 s600

4:m600 s600 5:m1150 s650 6:m600 s600 7:m550 s600

8:m1200 s600 9:m550 s650 10:m1150 s650 11:m1150 s600

12:m1150 s650 13:m1100 s650 14:m600 s600 15:m600 s600

16:m1150 s650 17:m550 s650 18:m1150 s600 19:m550

Extent=32650

Mark min:550 max:1200

Space min:600 max:650

The output identifies this a Sony protocol which is protocol “2”. The received value in hexadecimal is 0x74BCA and is 20 bits long. The stream contained 42 intervals (that is the value rawlen). It then dumps out all of the values from rawbuf. The first element of that array is the amount of time between initializing of the receiver and the first received mark. This gap is ignored by the decoder. The next two values are the length of the mark and space of the header sequence. The remaining values are the lengths of the marks and spaces of the data bits. Each mark is preceded by the letter “m” and spaces are “s”. The values are in microseconds. Because we used the IRrecv receiver you will note that all of the values are in 50µs increments.

At the end of the data bits, the method also reports the sum total of all of the intervals from the header through the stop bit. That information is significant for some protocols. It also tells you the maximum and minimum values of mark and space for data bits which can be useful for analyzing unknown protocols. Additional data analysis of unknown protocols can be found in the IRanalyze example sketch in the examples folder.

The text strings of the DumpResults method are stored in program memory rather than RAM memory. However if you are not using the DumpResults method and you are running out of program memory may wish to disable this function. In IRLib.h there is a define

#define USE_DUMP

You can comment out that line was to save program memory. Note that this parameter also affects the DumpResults method of the IRfrequency class as well.

When a decoder is created the pointer rawbuf is set equal to the global value irparams.rawbuf which is the global buffer used by the receiver class. In some circumstances you may wish to have your decoder use its own buffer so that you can resume receiving data while working with the previously received data in your decoder. You can change the buffer used by your decoder with the method

void UseExtnBuf(void *P);

You can pass a pointer to your new buffer and then GetResults will copy the raw data into this buffer instead of retaining it in the global buffer.

On some occasions you might wish to have more than one decoder and want to share the data between different decoders. In that case you would use…

void copyBuf (IRdecodeBase *source);

Note that the pointer you pass to that method is the pointer to the entire decoder class and not just the buffer. This method copies not only the values from rawbuf but it also copies rawlen.

The only remaining method in the base class is “genericDecode”. It is a general-purpose decoding routine used by many of the other protocols that share common attributes. It will be documented in the section on adding additional protocols to the library.

In addition to the base decoder class library also defines a function Pnames(IRTYPES type); which returns a pointer to a string containing the name of the protocol such as “Sony”, “NEC” etc. These strings are stored in flash memory or program memory so that it does not use valuable data RAM memory. It is used by DumpResults and may be useful to the end user as well.

Most protocols begin with an exceptionally long “mark” pulse which serves a number of purposes. One of the reasons it is generally long is that receiver devices have a special circuit called Automatic Gain Control or AGC that adaptively boosts the signal received so that it can be cleanly decoded. It has been our experience that when conditions are marginal such as a signal at an odd angle or a weak signal, then it takes time for the AGC to adjust itself. The result is the length of the opening “mark” is shortened. Many failed decodes occur because the header is too short. Consumer electronics devices such as TVs, DVD’s etc. only need to support a single protocol. So they do not need to concern themselves with the duration of the header in order to decide what to do. However our decoder classes all require that the received header pulse be reasonably close to the specification. You can turn off the requirement that the initial mark of the header is within normal tolerances. You do so by setting the value IgnoreHeader=true; This can improve the ability to decode weak signals by allowing the AGC to address.

Warning however if you’re using multiple protocols, it can give you an accurate results of the protocol type. Specifically the NEC and NECx protocols are identical except for the length of the initial header mark. Therefore an NECx signal would be reported as NEC when the IgnoreHeader parameter is true. Unfortunately the data values are unaffected. There may be other as yet unsupported pairs of protocols which cannot be distinguished from one another except by their header.

### 1.2.3. Specific Protocol Decoder Classes

The seven protocols shown below are each supported with their own decoder class. If you only need to use one protocol you should create an instance of one of these classes. The prototypes are in “IRLib.h” and the code itself is in “IRLib.cpp”. Each contains only one method “decode()” but of course they also have access to the data values and methods of the base class. The “decode()” method returns true if the data received could be successfully decode as that protocols and it returns false otherwise. The classes are…

class IRdecodeNEC: public virtual IRdecodeBase

{public: virtual bool decode(void);};

class IRdecodeSony: public virtual IRdecodeBase

{public: virtual bool decode(void);};

class IRdecodeRC5: public virtual IRdecodeRC

{public: virtual bool decode(void);};

class IRdecodeRC6: public virtual IRdecodeRC

{public: virtual bool decode(void);};

class IRdecodePanasonic_Old: public virtual IRdecodeBase

{public: virtual bool decode(void);};

class IRdecodeJVC: public virtual IRdecodeBase

{public: virtual bool decode(void);};

class IRdecodeNECx: public virtual IRdecodeBase

{public: virtual bool decode(void);};

The NEC, Sony and JVC protocols are used by those brands of equipment. The NECx is an extension of NEC used by them and other manufacturers. The RC5 and RC6 protocols were developed by Phillips and used by a variety of manufacturers. Panasonic_Old is used by cable boxes by Scientific Atlanta and Cisco mostly used by Time Warner and BrightHouse cable systems. The example code included with the library has similar routines which support DirecTV, Samsung36 and GIcable the last of which is used by Motorola cable boxes. Also the rcmm used by AT&T U-Verse is in the examples folder.

The NEC protocol uses a special sequence as a repeat code. With the NEC decoder detects a repeat pattern that will return the value 0xffffffff. Other protocols especially RC5 and RC6 makes use of a toggle bit. So if you decode successive presses of the same button, the value you will receive will have one bit inverted each time. However if you hold the same button down, the remote sends repeated codes and the bit will not change. This library has no built-in features for dealing with toggle bits. It treats those bits just like any other bit in the stream. It generally does not hurt to leave the toggle bit either set or reset all of the time.

There is an additional abstract class called IRdecodeRC which is the base class for both RC5 and RC6. Unless we find another protocol based upon those, you will probably never had of it directly.

Library also includes a hash code decoder class. It takes the array of data values and attempts to create a unique 32-bit code based on whether each value is higher, lower, or equal to the previous element of the array. It allows you to come up with an identifying number for an unknown protocol function. However there is no way to re-create the original data stream from that hash code. But for some applications using an unknown protocol it can be useful.

There is an overall IRdecode class which combines all seven protocols into a single class. It is defined as follows…

class IRdecode:

public virtual IRdecodeNEC,

public virtual IRdecodeSony,

public virtual IRdecodeRC5,

public virtual IRdecodeRC6,

public virtual IRdecodePanasonic_Old,

public virtual IRdecodeJVC,

public virtual IRdecodeNECx

{public: virtual bool decode(void);};

It’s decode method calls the decode methods of each of the seven defined protocols in that order and if it finds any of them returning true then it returns true as well. If all of the routines fail then it returns false. While this is useful when using multiple protocols, it creates overhead because all of the code for each of the protocols gets included in your sketch. If you are only using two or three of these seven protocols then you are wasting a lot of code space. It is recommended you create your own custom omnibus decode class that combines only the protocols which you are using. You can either comment out the unused protocols in this given IRdecode class or create your own custom class by copying its definition and getting rid of the unnecessary protocols.

Note that the linking loader is smart enough not to include code from a protocol which appears nowhere in your sketch. So if you do not create an instance of this omnibus decoder, you should include only the protocols you actually use.

## 1.3 Sending Classes

The decoder classes defined by this library all return a binary data value, the number of bits in that data value, and the type of protocol received. That information can then be used to re-create the original signal and send it out using an infrared LED. The sending classes allow you to re-create the signals that are sent by remote controls using the protocols supported by this library.

### 1.3.1. Sending Overview

The decoder classes defined by this library all return a binary data value, the number of bits in that data value, and the type of protocol received. That information can then be used to re-create the original signal and send it out using an infrared LED. There are a number of online references and other software such as LIRC which provide lists of binary values for different kinds of remotes and different functions. However they may have their own unique way of encoding the data that may or may not be compatible with the values used by this library. Therefore you should use the receiving and decoding classes to detect the signal from a remote and obtain the value that this library creates. Then you can use that value and the sending classes provided to re-create that stream and control some device.

You should read the decoding overview section of this reference to familiarize yourself with the protocols. We will not re-create that discussion here.

The library consists of an abstract base sending class and nine derived classes. Seven of them are for the seven supported protocols. One of them sends raw data out of the rawbuf array for use with unknown protocols and the ninth class is an omnibus class which combines all seven of the supported protocols into a single sending class.

Note: additional protocols are demonstrated in various example sketches provided with this library. These examples illustrate how to extend the library using object-oriented programming techniques without having to recompile it. It will be our policy for the foreseeable future not to directly add additional protocols to the library but to implement future protocols as example sketches. We will not accept any pull requests which add additional protocols to the main library. We will also not accept additional examples which do not implement both sending and decoding classes.

### 1.3.2. IRsendBase Class

The prototypes for the sending classes are in “IRLib.h” and the actual code is contained in “IRLib.cpp”. The prototype is…

class IRsendBase

{

public:

IRsendBase();

void sendGeneric(unsigned long data, unsigned char Num_Bits,

unsigned int Head_Mark, unsigned int Head_Space,

unsigned int Mark_One, unsigned int Mark_Zero,

unsigned int Space_One, unsigned int Space_Zero,

unsigned char kHz, bool Stop_Bits,

unsigned long Max_Extent=0);

protected:

void enableIROut(unsigned char khz);

VIRTUAL void mark(unsigned int usec);

VIRTUAL void space(unsigned int usec);

unsigned long Extent;

};

The base class is completely abstract. The constructor takes no parameters. The methods are all for internal use or for the creation of derived classes.

### 1.3.3. Specific Protocol Sending Classes

The seven protocols shown below are each supported with their own sender class. If you only need to use one protocol you should create an instance of one of these classes. The prototypes are in “IRLib.h” and the code itself is in “IRLib.cpp”. Each contains only one method “send()”. Although these derived classes have access to the methods and data of the base class, the end-user has no need of the other methods in the base class unless you are implementing an unsupported protocol. They are all for internal use. The classes are…

class IRsendNEC: public virtual IRsendBase

{public: void send(unsigned long data);};

class IRsendSony: public virtual IRsendBase

{public: void send(unsigned long data, int nbits);};

class IRsendRC5: public virtual IRsendBase

{public: void send(unsigned long data);};

class IRsendRC6: public virtual IRsendBase

{public: void send(unsigned long data, unsigned char nbits);};

class IRsendPanasonic_Old: public virtual IRsendBase

{public: void send(unsigned long data);};

class IRsendJVC: public virtual IRsendBase

{public: void send(unsigned long data, bool First);};

class IRsendNECx: public virtual IRsendBase

{public: void send(unsigned long data);};

Each class contains only one method a “send()” method. The first parameter is the data value to be sent. Some protocols have an additional parameter.

Note that there is no “IRsendHash” class because there is no way to re-create the data stream from the hash code created by the “IRdecodeHash” decoder class.

Sony and RC6 have different versions which use different numbers of bits. Their second parameter is the number of bits.

The JVC protocol sends data differently whether it is the first code sent or it is a repeat of the same code. In our experience you must send JVC codes twice. The first time as an original code and then again as a repeated code. The second parameter is a bool that should be true for the first sending and false for the second sending. See the ”IRsendJVC” example program to see how.

The NEC protocol uses a special sequence as a repeat code. With the NEC decoder detects a repeat pattern that will return the value 0xffffffff. If you pass that value to the send method of the NEC class it will send a special repeat pattern used by that protocol.

Other protocols especially RC5 and RC6 makes use of a toggle bit. So if you decode successive presses of the same button, the value received will have one bit inverted each time however if you hold the same button down, the remote sends repeated codes and the bit will not change. This library has no built-in features for dealing with toggle bits. It treats those bits just like any other bit in the stream. It generally does not hurt to leave the toggle bit either set or reset all of the time. The toggle bit for RC5 is 0x0800 and for RC6 is 0x10000. You would do a bitwise exclusive or with data to toggle that bit. See the “IRrecord” example code which shows how to send any values on any of the supported protocols and it includes support for toggle bits.

That example also shows how to use an additional class to send raw data values for protocols that are unsupported. If you receive an unknown protocol you can copy all of the values from the rawbuf array and save them. They can then re-create the original data stream using the IRsendRaw::send class and method. The prototype is shown here

class IRsendRaw: public virtual IRsendBase

{public: void send(unsigned int buf[],

unsigned char len, unsigned char khz);};

The first parameter points to the array of values. You also need to specify the number of intervals. The third parameter is the modulation frequency to use. If you do not know the modulation frequency then we recommend that you use 38 for this value. The receiver and decoder classes cannot normally detect the modulation frequency. See the section on the IRfrequency class to see how to detect modulation frequency. For more information see the section on implementing your own protocols.

Final class is an omnibus class that will send any of the supported protocols. Its prototype is…

class IRsend:

public virtual IRsendNEC,

public virtual IRsendSony,

public virtual IRsendRaw,

public virtual IRsendRC5,

public virtual IRsendRC6,

public virtual IRsendPanasonic_Old,

public virtual IRsendJVC,

public virtual IRsendNECx

{

public:

void send(IRTYPES Type, unsigned long data, unsigned int data2);

};

Its send method takes three parameters. The first is the protocol type. The second is the binary data to be sent. The third value serves multiple purposes. For some protocols is the number of bits. For other protocols it might be the first flag. In the example code the Samsung36 example uses the third parameter to contain part of the actual received data. That is because it is a 36 bit protocol and we can only use at most 32 bits in an integer variable. For protocols that did not need this third parameter you should set it to zero.

## 1.4 Hardware Considerations

Obviously for this library to be of any use you will need to add some hardware to your Arduino. Specifically an IR LED possibly with a driver circuit for output and some sort of infrared receiver for input purposes.

Most of the features of this library make use of various built-in hardware specific features of the Arduino platforms. They make use of hardware interrupts and built in the hardware timers. Because different Arduino platforms use different base chips, even something as simple as “What pin do I connect to?” Can be a difficult issue to resolve. Additionally more and more platforms beyond the traditional 8-bit Atmel are being labeled with the term “Arduino compatible” which makes the hardware issues even more complicated. We will address all of these issues in the following sections.

### 1.4.1. Interrupts and Timers

The hardware specific portions of the library are based on the fact that it uses hardware timers and hardware interrupts.

The IRrecvPCI and IRfrequency receiver classes make use of pin change hardware interrupts. This is a hardware feature which causes control of your program to branch immediately to a routine that you specify whenever a specific input pin changes. Different platforms have different numbers and locations available input pins which support this type of interrupt. A chart showing which pins are available on which Arduino platforms can be found in the section 1.1.4. IRrecvPCI Class. These interrupts are all handled by the built in “attachInterrupt()” function. It is possible if to use hardware interrupts to detect pin changes on a variety of other input pins however this involves much more complicated setup procedure that directly manipulates various processor pork registers. We have decided not to implement such an extent capability.

The IRrecvLoop receiver class uses no interrupts or timers so it allows you to get away from such hardware dependency. It is not possible to write a looped version of IRfrequency that is fast enough to measure frequency with reasonable accuracy. Therefore the only way to measure input frequency is by use of the pin change interrupts.

Another area of hardware dependency is the use of built in hardware timers. On the receiving end, the original IRrecv receiving class uses the hardware timer to generate an interrupt every 50 µs. The interrupt service routine then polls the input pin to determine its high or low state. While any input pin can be used for this purpose, you must specify an available hardware timer to generate this timed interrupt.

Atmel processors like those used in Arduino boards can have up to six hardware timers numbered 0 through 5. Note that some processors have a special high-speed version of TIMER 4 which they call TIMER 4HS. TIMER 0 is always reserved by the system for the “delay()”, “micros()” and “mills()” functions so it is never used. This library attempts to detect the type of processor you are using and it selects a default hardware timer.

In addition to using a hardware timer to generate the 50 µs interrupts on the IRrecv receiver class, the same timer is used to control the frequency of PWM output for sending signals. We send a PWM signal to an output IR LED or an output driver circuit. While most uses of PWM signals on Arduino platforms have a fixed frequency and a variable duty cycle, our needs are for a fixed duty cycle of about 33% on with a variable frequency. There are no built-in Arduino functions for manipulating the frequency so we have to modify various hardware registers directly. We need to use frequencies ranging from around 30 kHz to 57 kHz. The most accurate way to generate these frequencies is with a hardware timer.

Because the hardware timer driven PWM features are limited to specific output pins, you have a limited choice of pins to use for output. We can overcome this limitation using a method called “bit-bang”. Bit-bang software sits in a tight loop and directly turns the output pin on and off. This allows you to use any available output pin. There are limitations to the bit-bang method which we will discuss later.

The original IRremote library upon which this library is based only supported Arduino Uno and similar devices which had the hardware TIMER 2 available. Later more platforms and timers were added in the following branch of the original library.

https://github.com/TKJElectronics/Arduino-IRremote/

The support for these additional timers and platforms became the basis of the IRLibTimer.h file of this library. Although we had not personally tested all the platforms supported in this file, we were confident they should work because they were almost an exact copy of the branch which originally implemented them. However the changes which were made to separate the use of receiving timers from sending timers have not been tested on all of the platforms mentioned in this file. There is a greater possibility these modifications could have broken something no matter how careful we were in making these changes. We are especially interested in hearing from users of various Teensy platforms to ensure that our changes have not adversely affected your use of the code.

The table below shows the output pin number that you should use for output based upon the platform, chip and timer. If a cell is blank it means that that particular timer is not available on that chip.

Platform | Chip | | Timer
| | 1 | 2 | 3 | 4 | 4HS | 5
Arduino Mega | ATmega1280 & ATmega2560 | 11 | 9* | 5 | 6 | | 46
Arduino Leonardo | ATmega32U4 | 9* | | 5 | | 13
Arduino Uno and older | ATmega328 | 9 | 3*
Teensy 1.0 | AT90USB162 | 17*
Teensy 2.0 | ATmega32U4 | 14 | | 9 | | 10*
Teensy++ 1.0 & 2.0 | AT90USB646 & AT90USB1286 | 25 | 1* | 14
Saguino | ATmega644P & ATmega644 | 13 | 14*
Pinoccio | ATmega256RFR2 | | | D3*

Entries marked with * are the defaults. Note you will probably not need to change any of the timer specifications unless you need to use particular pins or unless you have a conflict with another library which makes use of hardware timers. For example the default timer for Arduino Leonardo is TIMER1 which also happens to be used by the Servo library. In such a circumstance you would need to change to TIMER3 or TIMER4_HS.

### 1.4.2 Changing Defaults

If you are using one of the supported platforms and can use the default output specified in the table above, then you can skip to section 1.4.3 and following which discusses schematics for IR LED drivers and the connection of IR receivers. However if you want to use a different timer, different output pin, or enable bit-bang output then continue with this section of the documentation which discusses how to change the defaults for timers and interrupts.

As mentioned previously, typically both the IRrecv 50 µs interrupt timing and the PWM output timing make use of the same hardware timer. However the implementation of bit-bang meant that we had to split these two functions. While the default still remains that they will use the same timer, it is theoretically possible use different hardware timers for input and output. However given that timers are such a limited resource (some platforms only have one or two) it is unlikely and we have not tested it.

We will begin by setting the IR_SEND_TIMERxx definitions. The IR_RECV_TIMERxx will be automatically set based on the sending timer. We will then show you how to override that automatic selection if you wish to do so. We will also show you later how to specify bit-bang sending side of timer sending. However because the selection of the send timer also controls the selection of the receiving timer, you should still choose a sending timer even if you’re going to override with bit-bang.

You can change the default IR_SEND_TIMERxx by commenting or uncommenting the proper lines in IRLibTimer.h. The section which allows you to change timers begins at approximately line 50. It attempts to detect your Arduino platform. For example if you have an Arduino Mega and want to use something other than the default TIMER 2 you would look for this section of the file…

/* Arduino Mega */

#if defined(__AVR_ATmega1280__) || defined(__AVR_ATmega2560__)

//#define IR_SEND_TIMER1 11

#define IR_SEND_TIMER2 9

//#define IR_SEND_TIMER3 5

//#define IR_SEND_TIMER4 6

//#define IR_SEND_TIMER5 46

You would put double slashes in front of the line for TIMER2 and remove the double slashes from in front of one of the other timer definitions. The number specified in the define is the pin number that you must use for output. While you can choose which of the supported timers you which to use by adding or removing slashes, do not change the numbers because they are required for those particular timers.

If you are modifying this library for unsupported platforms, you should attempt to implement hardware detection code in this section and specify the parameters for your platform here.

If you intend to use the same timer for input as for output, then you need do nothing else. The code will automatically set various IR_RECV_TIMERxx definitions for you. If you wish to override which timer is used for receiving and make it different than the sending timer, look at the IRLibTimer.h at approximately line 125 for the following section.

//#define IR_RECV_TIMER_OVERRIDE

//#define IR_RECV_TIMER1

//#define IR_RECV_TIMER2

//#define IR_RECV_TIMER3

//#define IR_RECV_TIMER4

//#define IR_RECV_TIMER4_HS

//#define IR_RECV_TIMER5

You should un-comment the first line to specify that you want to override and you should un-comment one and only one of the other lines. Note that there is no testing done to ensure that one of these timers is available on your particular platform. You need to look at the section for various IR_SEND_TIMERxx specifications or look at the chart in the previous section to see what is available for your platform. Use at your own risk.

An alternative to using a hardware timer to control the output PWM frequency is the previously discussed method known as “bit-bang”. We require frequencies from approximately 30 kHz to 57 kHz. Because we are dealing with relatively high frequencies, this method is very difficult to implement and is not as accurate as using the built in hardware timers. Most IR protocols specify frequencies within 0.1 kHz such as NEC protocol which uses 38.4 kHz. However even when using the built-in timer hardware, we only support integer frequencies so we rounded that down to even 38.0 kHz.

The bit-bang implementation is less accurate than that. Our limited tests show that our bit-bang implementation might produce results as much as +/-5% off of the target value. However our experience is that the specification of frequency isn’t that critical. We were still able to control TVs, VCRs, and cable boxes using bit-bang. We also discovered there are numerous factors such as hardware interrupts that can interfere with your results. We recommend you only use bit-bang on unsupported platforms or if appropriate timers and PWM pins are unavailable.

You specify use of bit-bang output in the file IRLibTimer.h in a section at approximately line 100. You will find the following two lines of defines.

//#define IR_SEND_BIT_BANG 3

#define IR_BIT_BANG_OVERHEAD 10

If the IR_SEND_BIT_BANG definition is commented out as it is shown here, then the library will use hardware timer driven PWM by default. If you remove the slashes to un-comment the definition, it will use bit-bang output on the pin number that you specify. In this example the default is pin number 3. The other definition is a timing “fudge factor” that you may need to specify. You need not comment it out when not using bit-bang. You can leave it alone.

Note that if you use bit-bang sending and IRrecvLoop for receiving you will not need any hardware timers or hardware interrupts. This may be especially useful for unsupported platforms.

Our implementation of bit-bang output is dependent upon the “delayMicroseconds()” function. If you are porting this code to a different platform, bit-bang will only be as accurate as your limitation of this function. By the way unlike the “micros()” function which is only accurate to 4 µs on 16 MHz processors or 8 µs on 8 MHz processors, delayMicroseconds() attempts to be accurate to 1 µs resolution. That still introduces some granularity into our results.

We want to reiterate that most users will not need to make any changes to IRLibTimer.h as long as they connect their output hardware to a supported pin and they do not have conflicts with other libraries.

### 1.4.3. IR LED Driver Components and Schematics

The simplest output circuit is simply connect the IR LED directly to the output pin of the Arduino and then connect it to +5 volts with a current limiting resistor of 100 ohms like this.

Make sure you get the polarity of the LED correct. The shorter of the two leads should connect to ground. The longer lead connects to the resistor which in turn connects to the Arduino.

Note that all of our examples presume +5 volt supplies however some Arduino systems run at 3.3 volts. These schematics should also work at 3.3 volts however you might want to slightly lower some of the resistor values.

The output pins of an Arduino cannot supply much current. This is especially true of some newer Arduinos based on 16 and 32 bit ARM processors rather than the traditional 8-bit AVR processors. A better solution is to use a driver transistor. The schematic below shows a 2N2222 transistor but any similar NPN transistor should work. The base of the transistor is connected to the output of the Arduino using a 470 ohm resistor. The emitter is connected to ground that the LED is connected between the +5V and the collector.

Note that the current passing through the LED will in all likelihood exceed the maximum continuous current rating of the LED. However in our particular application we have a modulated signal sending a sequence of pulses that only last a few milliseconds total. As long as you’re not sending a continuous signal, the circuit will work fine. Occasionally you will make up a special hardware board which includes both output and input portions but for a particular application you would be only using the input portion. Theoretically you could have an output pin accidentally left on continuously and it would burn out your LED. If you have an application that does input only but you have connected both input and output circuits you should use the IRrecv::No_Output() method in the setup portion of your sketch.

I have had good success with single transistor and single LED circuits over moderate distances but if you really want power you can use multiple LEDs with multiple driving transistors. The schematic below is loosely based on the output portion of the famous TV-B-Gone device with its four output LEDs. Note that the transistors and LEDs on the right half of the schematic can be eliminated if you want a double transistor and double LED circuit instead of quadruple.

The circuit starts with an NPN transistor connected to the Arduino output pin via a 1K resistor. That NPN then drives up to four PNP transistors that drive the LEDs. Note that we have added a 33 ohm resistor to each LED to limit the current. This resistor was added because I designed the circuit to be used with an IR remote control toy helicopter that would continuously send signals to the helicopter. If your application only has intermittent signals you can eliminate those 33 ohm resistors. Again any general purpose PNP switching transistor similar to the one in the schematic should work okay.

IR LEDs come in different varieties. Some are narrow angle and some are wide-angle. We happen to like the IR-333-A Everlight which is a 20° narrow angle LED available here from Moser Electronics (http://www.mouser.com/search/ProductDetail.aspx?R=EL-IR333-Avirtualkey63810000virtualkey638-IR333-A). For a wide-angle LED consider the IR333C/H0/L10 Everlight which has a 40° viewing angle also available here from Moser Electronics (http://www.mouser.com/search/ProductDetail.aspx). Similar devices are available from Adafruit (http://www.adafruit.com/products/387) and RadioShack (http://www.radioshack.com/product/index.jsp?productId=2062565). The one from Adafruit was 20° but the RadioShack model did not specify the angle. I like to use a combination of narrow angle and wide-angle LEDs. Either use one each in a two LED application or two each in a four LED application.

### 1.4.4 IR Receiver Components and Schematics

The schematic for a receiver connection is much simpler than the driver circuit. You simply connect power and ground to the device and connect the output pin of the device to an input on your Arduino.

Note that all of our examples presume +5 volt supplies however some Arduino systems run at 3.3 volts. These schematics should also work at 3.3 volts. It is critical that you do not use a 5 volt supply on your receiver if you are connecting to a 3.3 volt system.

For ordinary receiving, any unused digital input pin can be used. Traditionally we use pin 11 but any pin should work. For determining frequency, you are limited to pins which have been change interrupts available. See the section on the IRfrequency class for details.

While the schematic is trivial, the challenge is finding the proper device for receiving. Although we deal with IR signals and being square waves with pulses varying from a couple of hundred milliseconds up to a few thousand milliseconds, in fact those pulses are actually modulated at a frequency from somewhere between 30 kHz and 58 kHz. Different protocols use different frequencies. The TSOP series of devices from Vishay are generally used. They deem modulate this signal using a bandpass filter and automatic gain control. There is a 4 or 5 digit number after the TSOP designation. The final two digits designate the frequency. The next most significant two digits describe the type of package. A most significant fifth digit may describe the type of AGC. Here is a link to a selector guide from Vishay in PDF format. http://www.vishay.com/doc?49845

Typically you would use through hole packaging such as the TSOP44nn, TSOP84nn, or TSOP14nn. The frequency in the last two digits depends on the protocol you wish to use. Most hobbyists use 38 kHz such as TSOP4438. Frequencies outside the range 36-40 kHz are rare so a 38 kHz device is a good average among the most common protocols. Although they sell devices specifically to two different frequencies, the bandpass filters devices are centered around the specific frequency but are generally wide enough to allow a reasonable range of frequencies. One notable exception is the Panasonic_Old used by Scientific Atlantic and Cisco cable boxes. They are used mostly by Time Warner and Bright House cable systems. These systems use 57 kHz and on occasion 38 kHz receivers have difficulty detecting those signals. We have successfully used a part from RadioShack as seen here http://www.radioshack.com/product/index.jsp?productId=2049727

That particular part when received from them does not look like the photo on the website. It does not include the connector bracket that is depicted. It is described as a 38 kHz device and the packaging looks like the TSOP4438 but RadioShack does not provide a manufacturers part number. They only provide their catalog number 276-640. We have successfully used the RadioShack device at frequencies from 36 kHz to 57 kHz which is the entire range needed. A similar part from Adafruit Industries http://www.adafruit.com/products/157 designated as a TSOP38238 did not work at 57 kHz but if you do not need that higher frequency, it works quite well.

If you are having difficulty receiving 57 kHz signals with a 38 kHz device, you could purchase multiple receivers each tuned to a different frequency. Similarly you might have a device which is receiving signals from different directions. Perhaps you have a robot and you want to put three receivers equally spaced around the outside of the robot that could receive IR signals from any angle. For whatever reason that you might want multiple receivers, a schematic such as the one shown below to be used to connect them.

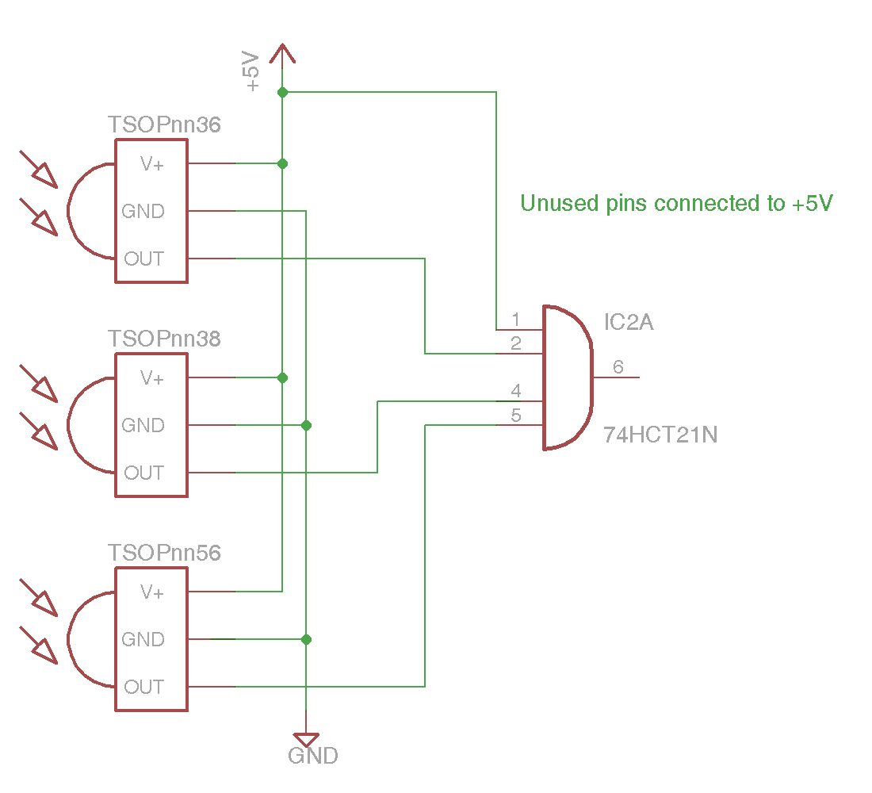
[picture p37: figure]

You would connect the output pins of each receiver to a logical AND gate. Here we are using a 74HCT21N quad input AND gate. You could use a 74HCT08N dual input that come 4 to a package. The 74HCTxx series is a CMOS chip that will operate at 5V TTL compatible levels suitable for use with Arduino at 5V. If you have any unused input pins on the gate you should tie them to +5.

You may wonder why we are using an AND gate when we want to receive a signal anytime any of the input devices are receiving a signal. You might think we want a logical OR gate. However the devices are normally high output and go low when a signal is received. Similarly our library is expecting active low signals. The logical equation says that NOT(NOT(A) OR NOT(B))=A AND B. Thus we use an AND gate.

There is one additional type of receiver we might want to use. The IRfrequency class which is used to detect modulation frequencies requires a different type of receiving device. The TSMP58000 device (note that is TSMP not TSOP) device receives raw signals. It does not have a bandpass filter tuned to a particular frequency and does not have automatic gain control. This type of devices generally described as an “IR learner” instead of “IR receiver”. It can be used to detect the modulation frequency of an incoming signal. This device must be connected to a hardware interrupt pin such as those used with the IRrecvPCI receiver class. See the section on the IRfrequency class.

# 2. Tutorials and Examples

When this section is fully implemented it will provide tutorials on how to use this library and explanation of all of the example programs in the examples directory. For now we will simply include links to some tutorials we have already posted in our blog on this website. Additional tutorials and examples will appear here eventually.

- IRLib Tutorial part 1: Hardware set up – 03/14/2013 (http://tech.cyborg5.com/2013/03/14/irlib-tutorial-part-1-hardware-set-up/)
- IRLib Tutorial part 2: Controlling a Servo Using an IR Remote – 03/14/2013 (http://tech.cyborg5.com/2013/04/13/irlib-tutorial-lesson-2-controlling-a-servo-using-an-ir-remote/)
- IRLib Tutorial part 3a: Sending IR Codes – 04/22/2013 (http://tech.cyborg5.com/2013/04/22/irlib-tutorial-part-3a-sending-ir-codes/)
- IRLib Tutorial part 3b: Creating a Virtual Remote Using Python – 05/04/2013 (http://tech.cyborg5.com/2013/05/04/irlib-tutorial-part-3b-creating-a-virtual-remote-using-python/)
- IRLib Tutorial part 3c: Python, PySerial and PyGame Installation on Windows – 05/30/2013 (http://tech.cyborg5.com/2013/05/30/irlib-tutorial-part-3c-python-pyserial-and-pygame-installation-on-windows/)
- IRLib Tutorial part 4: IR Remote Mouse – 06/10/2013 (http://tech.cyborg5.com/2013/06/10/irlib-tutorial-part-4-ir-remote-mouse/)

# 3. Implementing New Protocols

This section not yet implemented.

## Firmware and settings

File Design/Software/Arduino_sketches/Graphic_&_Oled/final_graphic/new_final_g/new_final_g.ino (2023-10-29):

#include <SPI.h>
#include <Wire.h>
#include <Adafruit_GFX.h>
#include <Adafruit_SSD1306.h>
//#include <IRremote.h>

// If using software SPI (the default case):
#define OLED_MOSI  11
#define OLED_CLK   12
#define OLED_DC    9
#define OLED_CS    8
#define OLED_RESET 10
Adafruit_SSD1306 display(OLED_MOSI, OLED_CLK, OLED_DC, OLED_RESET, OLED_CS);

#define string_default "Default tag"
#define RECV_PIN 4

//SU 2F0, Destra CD0, GIU AF0, SINISTRA 2D0

//#if (SSD1306_LCDHEIGHT != 64)
//#error("Height incorrect, please fix ");
//#endif

//IRrecv irrecv(RECV_PIN);
//IRsend irsend;
//decode_results results;
bool h_rapp=1;
short PulseSensorPurplePin = 0;        // Pulse Sensor PURPLE WIRE connected to ANALOG PIN 0
short Signal;                // holds the incoming raw data. Signal value can range from 0-1024
short Threshold = 550;            // Determine which Signal to "count as a beat", and which to ingore. 
short deanimate = 0, seconds = 0, mode = 2, curs = 0, old_curs = 0, maximum_r = 7, standard_r = 4, flag = 0, scrolly, minY, old_signal=0;

class CELL
{
  public:
    String tag;
    String command;
    short x, y, radius;
    bool hovering;
    void activate();
    void deactivate();
    void set_values (short, short, short);
    void set_activity (String, String);
    void set_hovering (bool);
    void animate();
    void deanimate();
};

void CELL::animate()
{
  if (radius < maximum_r)
    radius++;
}

void CELL::activate()
{ display.fillCircle(x , y , radius, WHITE);
  display.setCursor( 64 - (tag.length() * 3), 28);
  Serial.println(tag);
  display.setTextColor(WHITE, BLACK);
  display.setTextSize(1);
  display.println(tag);
  display.display();
}

void CELL::deactivate()
{
  display.fillCircle(x , y , maximum_r + 1, BLACK);

  if (radius > standard_r)
    radius = radius - 1;

  display.drawCircle(x , y , radius, WHITE);
  display.fillRect( 20, 28, 144, 8, BLACK);
  display.display();
}

void CELL::deanimate()
{
  display.fillCircle(x , y , maximum_r + 1, BLACK);
  if (radius > standard_r)
    radius = radius - 1;
  display.drawCircle(x , y , radius, WHITE);

}

void CELL::set_values (short set_x, short set_y, short set_radius)
{
  x = set_x;
  y = set_y;
  radius = set_radius;
}

void CELL::set_activity (String set_tag, String set_command)
{
  tag = set_tag;
  command = set_command;
}

void CELL::set_hovering (bool set_hovering)
{
  hovering = set_hovering;
}

CELL matrix[6];

void initialize_matrix()
{
  matrix[0].set_values (42, 12, standard_r);
  matrix[0].set_activity ("ciao", string_default);
  matrix[0].set_hovering (0);
  Serial.println("1.h");        //numbers are not wrong

  matrix[1].set_values (64, 8, standard_r);
  matrix[1].set_activity ("hi", string_default);
  matrix[1].set_hovering (0);
  Serial.println("2.h");

  matrix[2].set_values (86, 12, standard_r);
  matrix[2].set_activity ("how", string_default);
  matrix[2].set_hovering (0);
  Serial.println("3.h");

  matrix[3].set_values (42, 48, standard_r);
  matrix[3].set_activity ("are", string_default);
  matrix[3].set_hovering (0);
  Serial.println("4.h");

  matrix[4].set_values (64, 52, standard_r);
  matrix[4].set_activity ("you", string_default);
  matrix[4].set_hovering (0);
  Serial.println("5.h");

  matrix[5].set_values (86, 48, standard_r);
  matrix[5].set_activity ("like", string_default);
  matrix[5].set_hovering (0);
  Serial.println("6.h");
 
}


void setup()   {
  Serial.begin(9600);

  // by default, we'll generate the high voltage from the 3.3v line internally! (neat!)
  display.begin(SSD1306_SWITCHCAPVCC);  // initialize with the I2C addr 0x3C (for the 128x32)
  // init done
  // Clear the buffer.
  display.clearDisplay();
  display.display();
  initialize_matrix(); //give default values (replecable)
  //  irrecv.enableIRIn(); // Start the receiver
}

void loop() {


  if (mode == 0)
  {
    if (flag == 0)      // if the screen base of object have never been initialized before/ we're coming from another modality
      /********************************************drawing the base of the CELL ensemble***********************/
    { int i;
      for (i = 0; i < 6; i++)
      { matrix[i].deactivate();
        flag = 1;
      }
    }
    /*********************************************************************************************************/

    Serial.println("cicle"); //beginning of cicles

    //   results.value=0;
    /*
      irrecv.decode(&results);
      irrecv.resume();
      Serial.println(results.value, DEC);

      if (results.value==3536)
      {
      mode++;
      results.value=0;
      }
      else if (results.value==3280)
      curs=curs+1;
      else if (results.value==720)
      curs=curs-1;
      else if (results.value==2800)
      curs=curs+3;
      else if (results.value==752)
      curs=curs-3;
    */

    /*****************************checking the legality of curs variable******************************************/
    if (curs == 6)
      curs = 0;
    else if (curs < 0)
      curs = 0;
    else if (curs > 6)
      curs = curs % 6;
    /*************************************************************************************************************/

    Serial.println(curs);
    if (curs != old_curs)
    {
      matrix[curs].activate();
      matrix[old_curs].deactivate();
    }
    else
    {
      matrix[curs].animate();
      matrix[curs].activate();
    }

    old_curs = curs;
    curs ++;

    /*******************************Reduction of the CELL objects*************************************************/
    short de;
    for (de = 0; de < 6; de++)
      if (de != curs)
        matrix[de].deanimate();
    /*************************************************************************************************************/


    //   results.value=0;


  }
  /*else if (mode == 1)
  { if (flag=0)
    {
    display.setTextSize(7);
    display.setTextColor(WHITE);
    display.setTextWrap(true);
    scrolly    = display.height();
    minY = - 60 * strlen(string_default);
    flag=1;
    }
    
    display.clearDisplay();
    display.setCursor(0, scrolly);
    display.print(string_default);
    display.display();

    if(--scrolly < minY) 
    scrolly = display.height();
    

    /*      irrecv.decode(&results);
          irrecv.resume();
          Serial.println(results.value, HEX);
          Serial.println("cicle");

            if (results.value==2672)
            {mode++;
             flag=0;
             results.value=0;
            }
    */
  //}*/
  else if (mode == 2)
  {
  Signal = analogRead(PulseSensorPurplePin);  // Read the PulseSensor's value. 
  Serial.println(Signal);                                          // Assign this value to the "Signal" variable.
  
  if((Signal>300)&&(Signal<600))
  {
  if((Signal>old_signal+7)||(Signal<old_signal-7))
  {Serial.println("if");                    // Send the Signal value to Serial Plotter.
                                              // signal:950=x:64 whole screen
   Signal = ((Signal*32)/950)  ;            //zoomed if betwee(300) and (600)
   
   if (h_rapp==0)
   {
    display.fillCircle( (display.width()/2)-Signal/2 , (display.height()/2)-10, Signal,WHITE);
    display.fillCircle( (display.width()/2)+Signal/2 , (display.height()/2-10), Signal,WHITE);
    display.fillTriangle( (display.width()/2)-Signal*1.5,(display.height()/2)-10, (display.width()/2)+Signal*1.5 , (display.height()/2)-10, (display.width()/2) ,display.height()/2+Signal*1.5 , WHITE);
    display.fillCircle( (display.width()/2)-Signal/2 , (display.height()/2)-10, Signal-5,BLACK);
    display.fillCircle( (display.width()/2)+Signal/2 , (display.height()/2-10), Signal-5,BLACK);
    display.fillTriangle( ((display.width()/2)-Signal*1.5)-5,(display.height()/2)-10, ((display.width()/2)+Signal*1.5)-5 , (display.height()/2)-10, (display.width()/2) ,(display.height()/2+Signal*1.5)-5 , BLACK);
    display.display();
    display.clearDisplay();
   }
   else         
   {
    display.drawLine(scrolly-1, old_signal, scrolly, Signal, WHITE);
    display.display();

   scrolly++;
   
    if (scrolly>128)
    {  scrolly=0;
      display.clearDisplay(); 
    }
   
   }
   
   
   
   if(Signal > Threshold){  
   } else {   }
     delay(10);
    }
    
  old_signal=Signal;
  }
  }
}

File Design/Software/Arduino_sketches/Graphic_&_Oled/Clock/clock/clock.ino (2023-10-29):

#include <SPI.h>
#include <Wire.h>
#include <Adafruit_GFX.h>
#include <Adafruit_SSD1306.h>

#define OLED_RESET 4
Adafruit_SSD1306 display(OLED_RESET);

#if (SSD1306_LCDHEIGHT != 32)
#error("Height incorrect, please fix ");
#endif

int seconds=0;


void setup()   {                
  Serial.begin(9600);

  // by default, we'll generate the high voltage from the 3.3v line internally! (neat!)
  display.begin(SSD1306_SWITCHCAPVCC, 0x3C);  // initialize with the I2C addr 0x3C (for the 128x32)
  // init done
  // Clear the buffer.
  display.clearDisplay();
  

/*  // draw many lines
  testdrawline();
  display.display();
  delay(2000);
  display.clearDisplay();

  // draw rectangles
  testdrawrect();
  display.display();
  delay(2000);
  display.clearDisplay();

  // draw multiple rectangles
  testfillrect();
  display.display();
  delay(2000);
  display.clearDisplay();

  // draw mulitple circles
  testdrawcircle();
  display.display();
  delay(2000);
  display.clearDisplay();

  // draw a white circle, 10 pixel radius
  display.fillCircle(display.width()/2, display.height()/2, 10, WHITE);
  display.display();
  delay(2000);
  display.clearDisplay();

  testdrawroundrect();
  delay(2000);
  display.clearDisplay();

  testfillroundrect();
  delay(2000);
  display.clearDisplay();

  testdrawtriangle();
  delay(2000);
  display.clearDisplay();
   
  testfilltriangle();
  delay(2000);
  display.clearDisplay();

  // draw the first ~12 characters in the font
  testdrawchar();
  display.display();
  delay(2000);
  display.clearDisplay();

  // draw scrolling text
  testscrolltext();
  delay(2000);
  display.clearDisplay();

  // text display tests
  display.setTextSize(1);
  display.setTextColor(WHITE);
  display.setCursor(0,0);
  display.println("Hello, world!");
  display.setTextColor(BLACK, WHITE); // 'inverted' text
  display.println(3.141592);
  display.setTextSize(2);
  display.setTextColor(WHITE);
  display.print("0x"); display.println(0xDEADBEEF, HEX);
  display.display();
  delay(2000);
  display.clearDisplay();

  // miniature bitmap display
  display.drawBitmap(30, 16,  logo16_glcd_bmp, 16, 16, 1);
  display.display();
  delay(1);

  // invert the display
  display.invertDisplay(true);
  delay(1000); 
  display.invertDisplay(false);
  delay(1000); 
  display.clearDisplay();

  // draw a bitmap icon and 'animate' movement
  testdrawbitmap(logo16_glcd_bmp, LOGO16_GLCD_HEIGHT, LOGO16_GLCD_WIDTH);
*/
}


void loop() {


  
  clck_base();
  clck_line();
  testo();
  display.display();
  display.clearDisplay();
  delay(100);
}

void testo()
{display.setTextSize(1);
  display.setTextColor(WHITE);
  display.setCursor(2,2);
  display.println("TIME \n IS \n NOW :");



  display.setTextSize(1);
  display.setTextColor(WHITE);
  display.setCursor(100,12);
  display.println(seconds);
  delay(1);
  }

void clck_line()
{ 
  
  int arrivex,arrivey,thirty;
  thirty=32;

  if (seconds==0)
   {arrivex= 32+thirty;
    arrivey= 6; }
  else if (seconds==5)
   {arrivex= 37+thirty;
    arrivey= 8; }
  else if (seconds==10)
   {arrivex= 40+thirty;
    arrivey= 11; }
  else if (seconds==15)
   {arrivex= 41+thirty;
    arrivey= 16; }
  else if (seconds==20)
   {arrivex= 40+thirty;
    arrivey= 21; }
  else if (seconds==25)
   {arrivex= 37+thirty;
    arrivey= 24; }
  else if (seconds==30)
   {arrivex= 32+thirty;
    arrivey= 26; }
  else if (seconds==35)
   {arrivex= 26+thirty;
    arrivey= 24; }
  else if (seconds==40)
   {arrivex= 23+thirty;
    arrivey= 21; }
  else if (seconds==45)
   {arrivex= 22+thirty;
    arrivey= 16; }
  else if (seconds==50)
   {arrivex= 26+thirty;
    arrivey= 11; }
  else if (seconds==55)
   {arrivex= 26+thirty;
    arrivey= 8; }
  else if (seconds==60)
   {arrivex= 32+thirty;
    arrivey= 6; }
  

  
  display.drawLine(display.width()/2, display.height()/2, arrivex, arrivey, WHITE);
  
  if (seconds==60)
    seconds=0;
  else
    seconds=seconds+5;
  
}


void clck_base()
{
  display.drawCircle(display.width()/2, display.height()/2, 15, WHITE);
  }

/*void testdrawbitmap(const uint8_t *bitmap, uint8_t w, uint8_t h) {
  uint8_t icons[NUMFLAKES][3];
 
  // initialize
  for (uint8_t f=0; f< NUMFLAKES; f++) {
    icons[f][XPOS] = random(display.width());
    icons[f][YPOS] = 0;
    icons[f][DELTAY] = random(5) + 1;
    
    Serial.print("x: ");
    Serial.print(icons[f][XPOS], DEC);
    Serial.print(" y: ");
    Serial.print(icons[f][YPOS], DEC);
    Serial.print(" dy: ");
    Serial.println(icons[f][DELTAY], DEC);
  }

  while (1) {
    // draw each icon
    for (uint8_t f=0; f< NUMFLAKES; f++) {
      display.drawBitmap(icons[f][XPOS], icons[f][YPOS], bitmap, w, h, WHITE);
    }
    display.display();
    delay(200);
    
    // then erase it + move it
    for (uint8_t f=0; f< NUMFLAKES; f++) {
      display.drawBitmap(icons[f][XPOS], icons[f][YPOS], bitmap, w, h, BLACK);
      // move it
      icons[f][YPOS] += icons[f][DELTAY];
      // if its gone, reinit
      if (icons[f][YPOS] > display.height()) {
        icons[f][XPOS] = random(display.width());
        icons[f][YPOS] = 0;
        icons[f][DELTAY] = random(5) + 1;
      }
    }
   }
}


void testdrawchar(void) {
  display.setTextSize(1);
  display.setTextColor(WHITE);
  display.setCursor(0,0);

  for (uint8_t i=0; i < 168; i++) {
    if (i == '\n') continue;
    display.write(i);
    if ((i > 0) && (i % 21 == 0))
      display.println();
  }    
  display.display();
  delay(1);
}

void testdrawcircle(void) {
  for (int16_t i=0; i<display.height(); i+=2) {
    display.drawCircle(display.width()/2, display.height()/2, i, WHITE);
    display.display();
    delay(1);
  }
}

void testfillrect(void) {
  uint8_t color = 1;
  for (int16_t i=0; i<display.height()/2; i+=3) {
    // alternate colors
    display.fillRect(i, i, display.width()-i*2, display.height()-i*2, color%2);
    display.display();
    delay(1);
    color++;
  }
}

void testdrawtriangle(void) {
  for (int16_t i=0; i<min(display.width(),display.height())/2; i+=5) {
    display.drawTriangle(display.width()/2, display.height()/2-i,
                     display.width()/2-i, display.height()/2+i,
                     display.width()/2+i, display.height()/2+i, WHITE);
    display.display();
    delay(1);
  }
}

void testfilltriangle(void) {
  uint8_t color = WHITE;
  for (int16_t i=min(display.width(),display.height())/2; i>0; i-=5) {
    display.fillTriangle(display.width()/2, display.height()/2-i,
                     display.width()/2-i, display.height()/2+i,
                     display.width()/2+i, display.height()/2+i, WHITE);
    if (color == WHITE) color = BLACK;
    else color = WHITE;
    display.display();
    delay(1);
  }
}

void testdrawroundrect(void) {
  for (int16_t i=0; i<display.height()/2-2; i+=2) {
    display.drawRoundRect(i, i, display.width()-2*i, display.height()-2*i, display.height()/4, WHITE);
    display.display();
    delay(1);
  }
}
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

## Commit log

2023-10-28 Moved and created with happyness
    [Glove project fritzing.fzz, MPU-6050 Board GY-521 Acelerometro Giroscopio.fzz, Pro micro2.fzz]
2023-10-28 did things
    [Glove project fritzing.fzz, MPU-6050 Board GY-521 Acelerometro Giroscopio.fzz, Pro micro2.fzz]
